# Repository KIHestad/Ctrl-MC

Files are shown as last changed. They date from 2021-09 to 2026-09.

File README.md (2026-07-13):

Ctrl-MC logo

# Motorcycle Control System

Ctrl MC (pronounced: "Control MC") is a system currently in development for simplifying and modernizing the wiring for motorcycles.

The project is managed by [KI Hestad](https://youtube.com/kihestad).
For updated information about the project check the authors [YouTube channel](https://youtube.com/kihestad). Feel free to participate with ideas and feedback by joining the projects [Discord Server](https://discord.gg/p5pfdZxfS8)

PCBs for this project are sponsored by [NextPCB](https://www.nextpcb.com?code=kihestad). If you need PCB manufacturing services, we recommend [NextPCB](https://www.nextpcb.com?code=kihestad).

Do you want to support this project? It's easy, just [click here to subscribe to the YouTube channel](https://youtube.com/kihestad/?sub_confirmation=1)!!!

## Project Description

This project is still in early stages, the idea is to:

* Create a motorcycle control system based on microcontrollers (STM32) and canbus to simplify and improve the wiring harness with possibility to add modern features for 'classic' (=older) motorcycles
  * The main goal is to make an intuitive and reliable system for wiring up a motorcycles lights and instruments 
  * The project does not in the first phases aim to replace or modify the motorcycle engine ignition system, but maybe later?
* Provide software, schematics and instructions free of charge
* Create a community for motorcycle- and Arduino enthusiasts that want to contribute
* Make the solution universal and configurable, it should be suitable for as many motorcycle brands and models as possible

Long term goals, depending on the success of the project:
* Provide a DIY kit with all parts needed
* Provide a completely built solution ready to be installed on the bike

Some of the benefits the system (hopefully) will give:

* Reliability: Individual solid state relays with inbuilt automatic fuses controls 12V to the bikes electrical components
* Simplify wiring: Single cable per component, separat wiring for input controls on handlebar and output power to components
* Providing customization: Setting parameters to enable features and how they should work
* Gives posibility to improve or add new features to the motorcycle (optional): 
  * Touch buttons instead of traditional handlebar switches
  * Keyless ignition using bluetooth, RF-ID or "password" using input buttons
  * OLED display instead of traditional speedometer, tachometer and warning lights
  * Smart functions, ex: auto turn off indicator lights, not possible to trigger start motor when engine is running
  * Alarm if bike is moved
* Use standard components
* Provide a budget friendly solution as an alternative to expensive commercial products

## Development information

The software is developed using Visual Studio Code. The first prototypes where using are using Platform IO, Arduino framework and C++ language. The latest prototype is using STM32CubeIDE and C language. The software is open source and available in this GitHub repository.
* Prototype 1 was a first attempt having a display unit and a relay unit using serial communication to send data in between
* Prototype 2 was a standalone display unit for testing use of hall sensor for speedometer and IT sensor for rpm meter made for a Cagiva 750 Elefant.
* Prototype 3 is a simple canbus communication test using STM32 microcontroller, this is not to be used in further development but just for testing the canbus communication
* MC Wiring Simulator is a PCB designed as a supportng tool for testing and developing purposes. 

## Other info

Let me know if anything is missing, just go to the project [Discord channel](https://discord.gg/p5pfdZxfS8) ^_^

Ctrl-MC logo

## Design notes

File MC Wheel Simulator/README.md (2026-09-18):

# Motorcycle Wheel Simulator

Contributior: Paul McIntosh

The is a wheel simulator is to enable bench testing wheel hall effect sensors and their input to the motorcycle/scooter system.

The basic concept is to simulate a rotating magnet that would sit on a wheel and drives a hall effect sensor. Why is this useful? The signal from a hall effect (or reed switch) can be noisy or not fit for purpose, trying to debug problems on a motorcycle/scooter while riding, takes insane circus skills and although fun, may put your electronic test equipment in danger :)

This simulator solves the problem by providing an adjustable RPM to drive your sensor, so you can develop things like speedometers and other cool things, like power from acceleration.

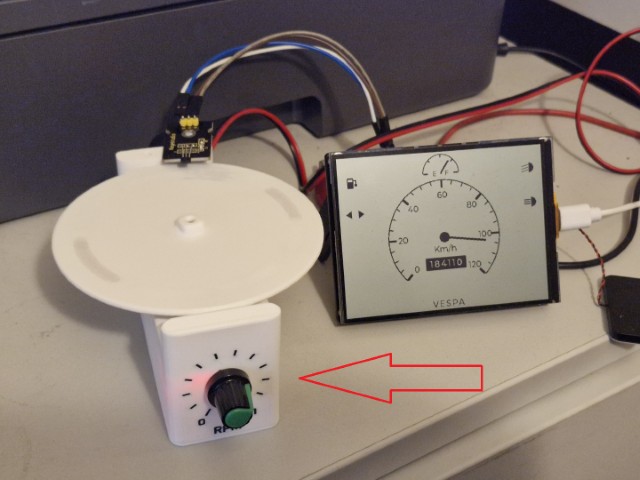
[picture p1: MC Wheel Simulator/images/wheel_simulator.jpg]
wheel_simulator


## What is provided

- stl files you can 3d print
- step files you can adjust to your needs

## What you need

The stls work with the following components

- Neodymium Disc Magnet - 6mm x 2mm
- 1000rpm Mini DC N20 geared motor 
- EMSea PWM DC Low Voltage Motor Speed Controller with Control Knob to match above
- Connectors, screws and wire etc

Note: you get what you pay for - lots of cheap stuff will work but may be noisy and buggy

## Considerations

The stls provided can take 4 x magnets, use 2 or 4 to keep the rotor balanced. **Make sure they are inserted with the same N/S orientation so that the hall sensor detects the same magnetic field each time**

With the above you can pick your target RPM based on wheel size and speed e.g. 2 magnets with 1000RPM motor = 2000RPM.

## Construction Images

Steps to construct - assuming 3d printing has completed

1. Attach wiring to components (see parts list above)

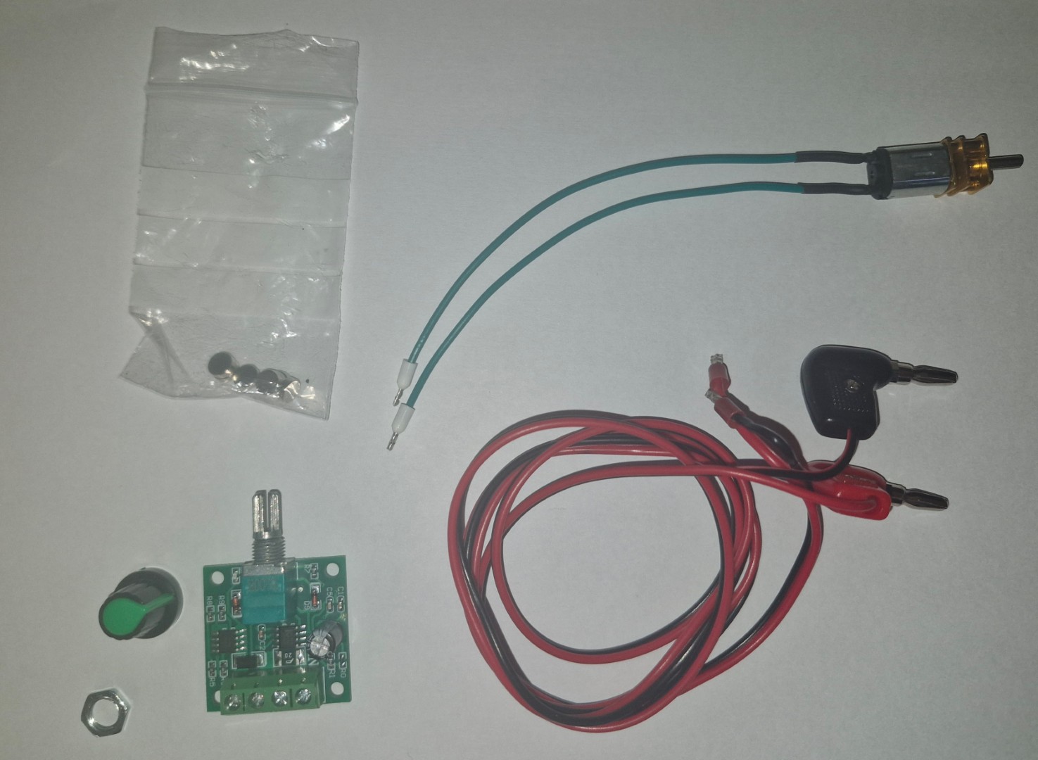
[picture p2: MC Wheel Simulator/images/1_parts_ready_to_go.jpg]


2. Push motor in from the top

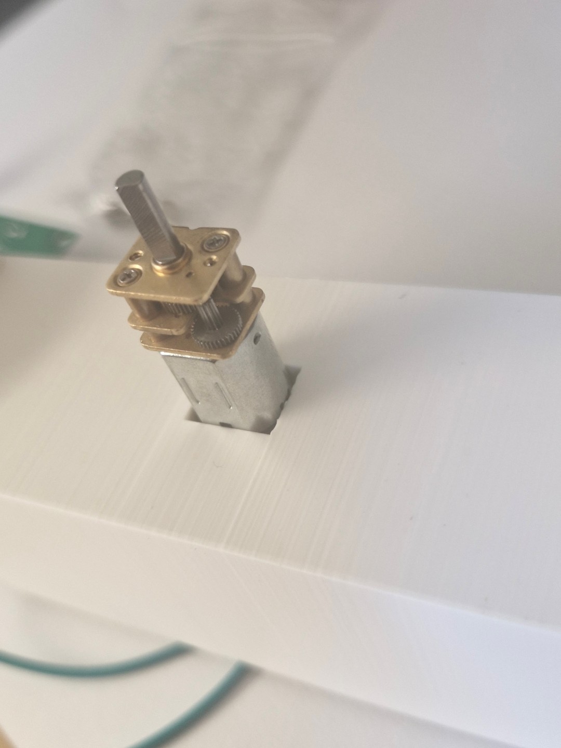
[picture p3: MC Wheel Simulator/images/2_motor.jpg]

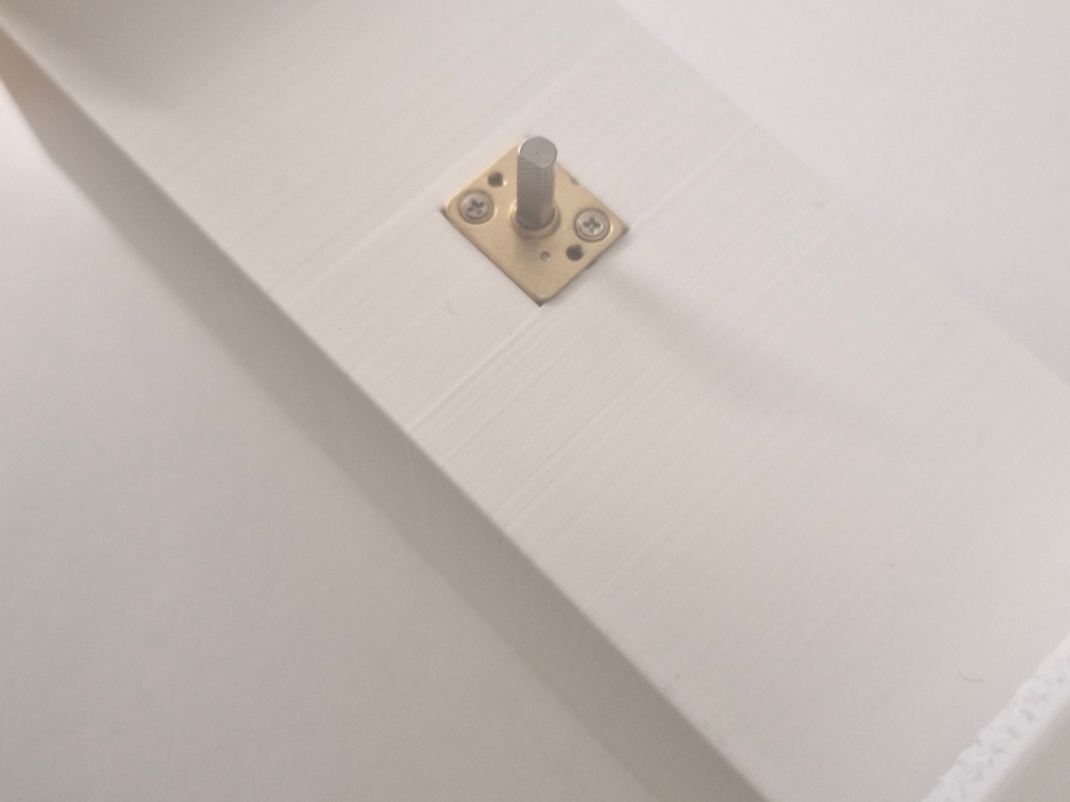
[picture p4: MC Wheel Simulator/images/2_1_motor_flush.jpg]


3. Press on adaptor

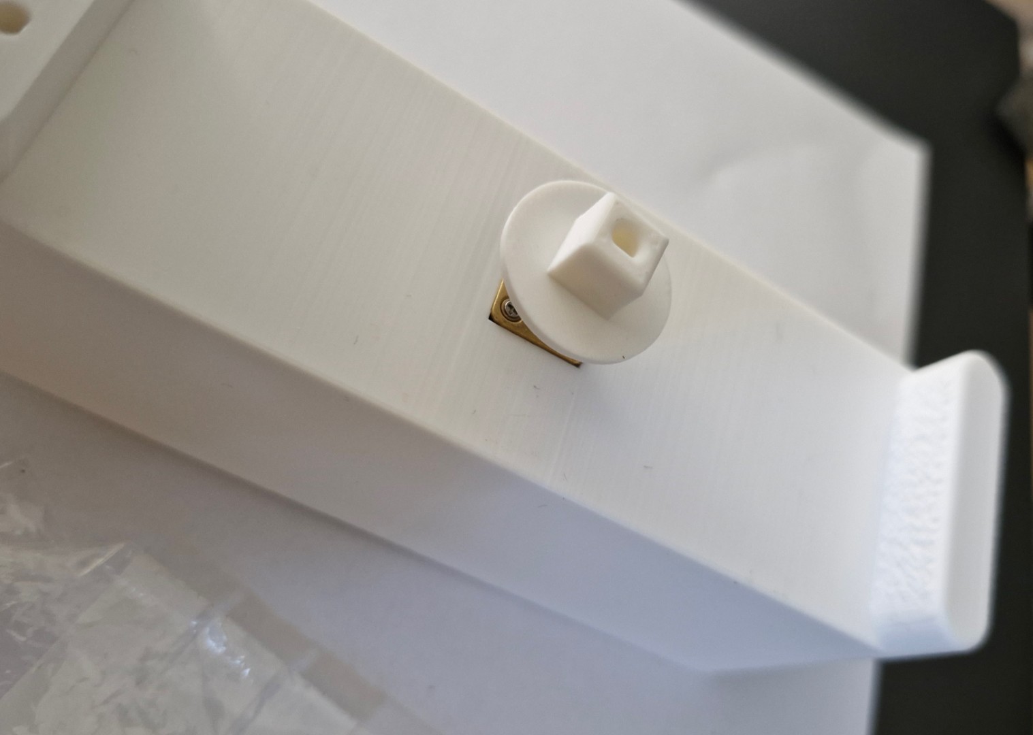
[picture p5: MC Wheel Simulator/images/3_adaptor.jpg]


4. Connect internal wiring and screw controller board into place

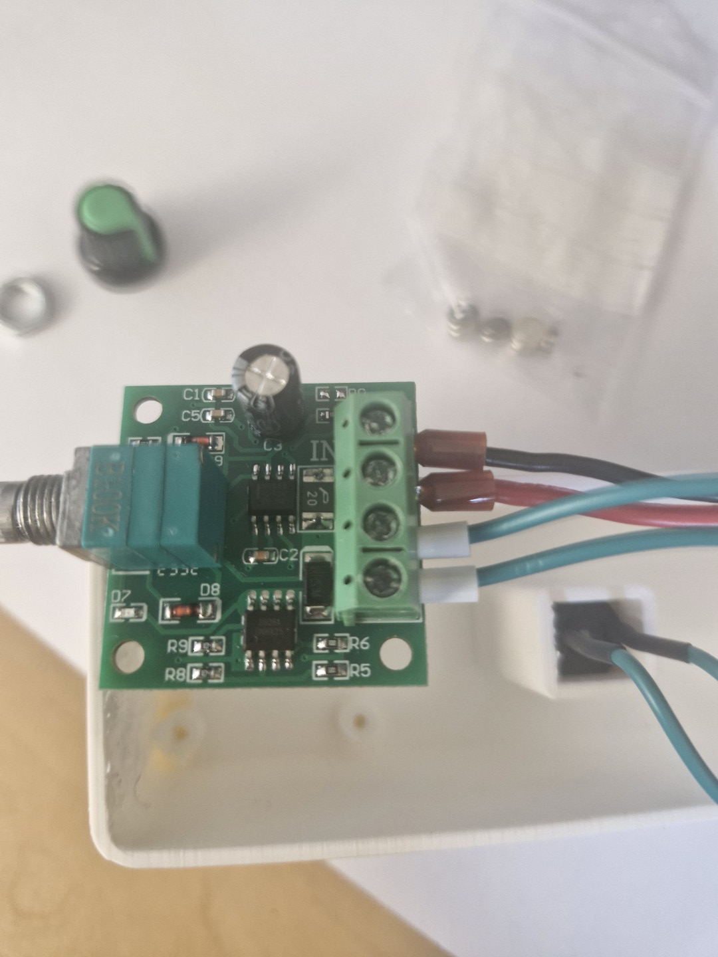
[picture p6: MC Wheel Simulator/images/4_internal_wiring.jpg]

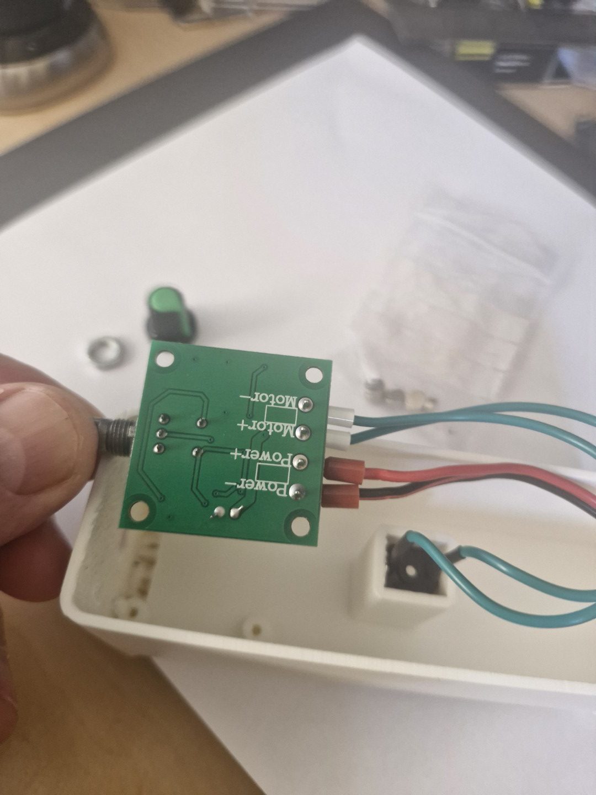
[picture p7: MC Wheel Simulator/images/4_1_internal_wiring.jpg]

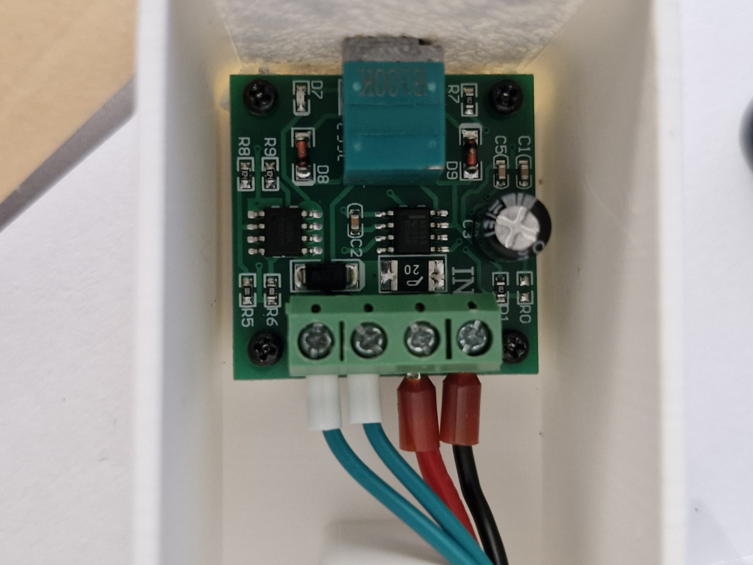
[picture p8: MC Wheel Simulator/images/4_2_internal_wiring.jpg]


5. Check everything works and clip in the base

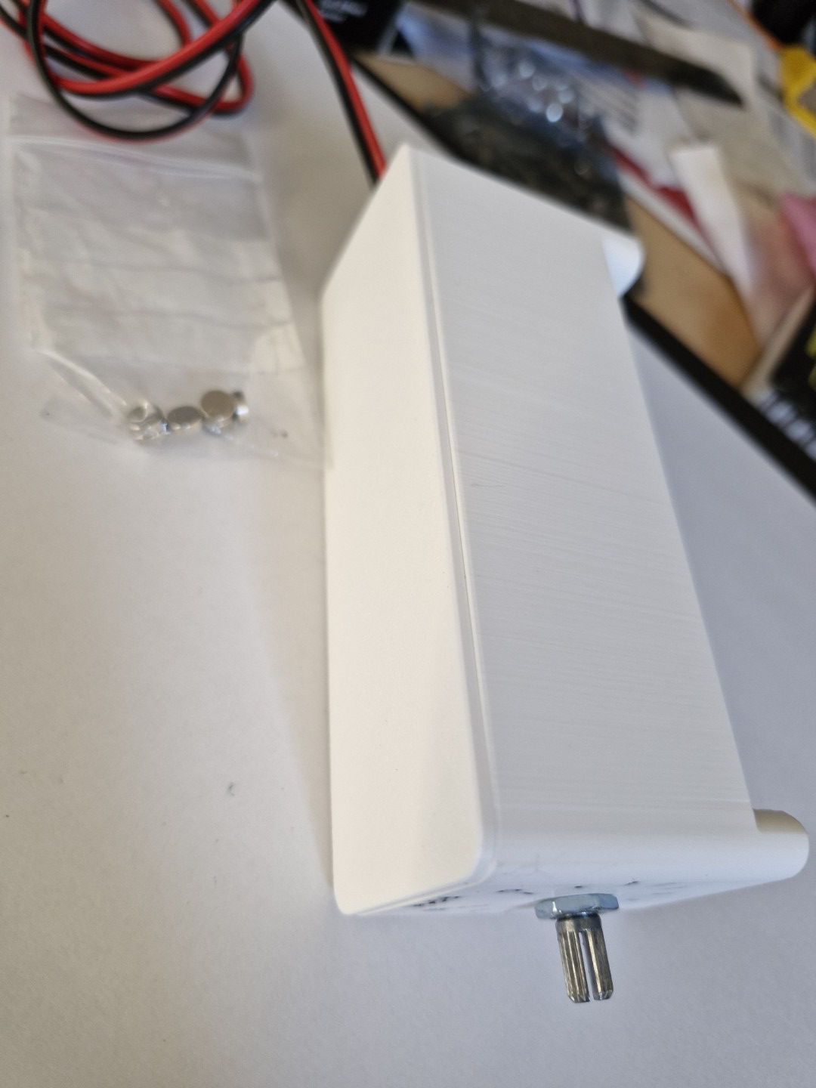
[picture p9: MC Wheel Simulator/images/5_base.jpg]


6. Insert magnets into rotor (keep polarity the same - marking dots helps)

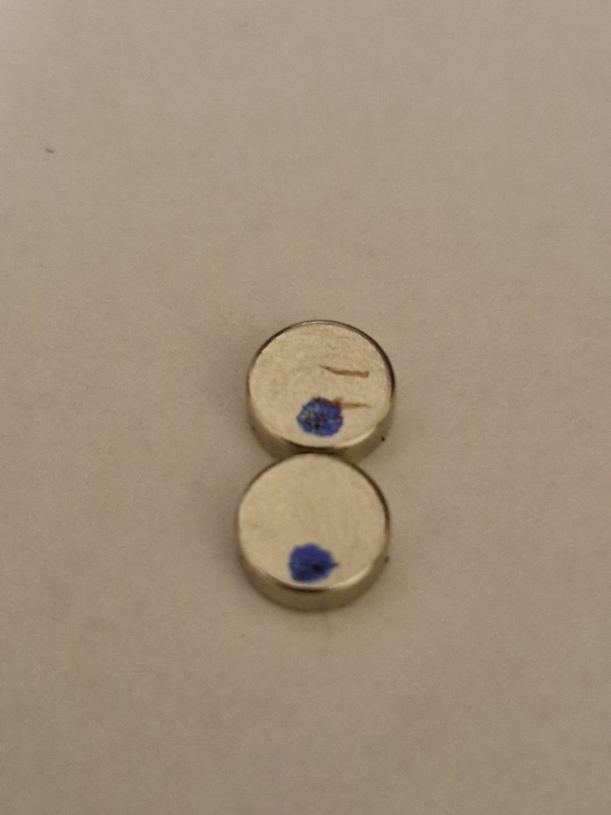
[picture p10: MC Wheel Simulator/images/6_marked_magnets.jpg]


7. Mount rotor and control knob

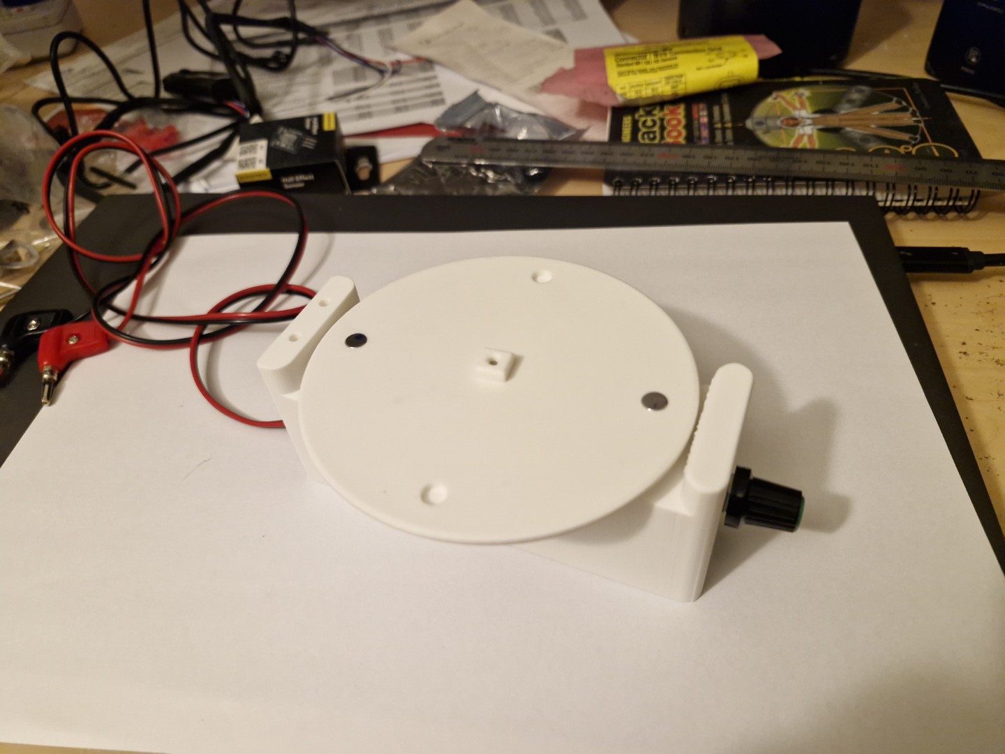
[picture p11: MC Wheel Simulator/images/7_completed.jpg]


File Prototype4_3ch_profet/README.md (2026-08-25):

Ctrl MC logo

# PROTOTYPE 4B: 3 CHANNEL PROFET SWITCHES - STM32 with Infineon Profet +12V Smart Switch modules

The prototype 4B is the second complete software for the Ctrl MC system that uses Infineon Profet +12V Smart Switches. This code is the basis for further development, but it is not the final system. 

The software is made to be used on a WeAct Studio STM32G431 dev board, and one custom PCB module with one 15Amp switch and one 2 x 5Amp swithc. Input GPIO's are also configuret to be able to test turning the switches on and off. It's tested with the MC Wiring Simulator.

The code is built using VS Code with the STM32 extensions. The setup is explained in the document:

*  [Ctrl MC Software Stack Setup.pdf](https://github.com/KIHestad/Ctrl-MC/blob/main/Documents/Ctrl-MC%20Software%20Stack%20Setup.pdf)

Here is the link to the YouTube video demoing this system:

* [The New Modern Motorcycle Wiring System - Ctrl MC](https://youtu.be/QElHGgWnjcQ?si=KIwvGmHAoNGqVMwO)

Here is the link to the YouTube video explaining the system overall:

* [Uprade Your Motorcycle using Smart High-Side Switches](https://youtu.be/tBPsuoETR0Y?si=mi2s_HrKnGi2g0Y8)

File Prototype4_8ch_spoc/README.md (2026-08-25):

Ctrl MC logo

# PROTOTYPE 4C: 8 CHANNEL SPOC SWITCHES - STM32 with Infineon SPOC +12V Smart Switch modules

The prototype 4C is the third complete software for the Ctrl MC system that uses Infineon SPOC +12V Smart Switches. This code is the basis for further development, but it is not the final system. 

The software is made to be used on a WeAct Studio STM32G431 dev board, and one custom PCB modules with two 4 channel SPOC swithces. Each swithc has 2 x 4Amp and 2 x 7Amp channels. It uses SPI for communication with the MCU. It's tested with the MC Wiring Simulator.

The code is built using VS Code with the STM32 extensions. The setup is explained in the document:

*  [Ctrl MC Software Stack Setup.pdf](https://github.com/KIHestad/Ctrl-MC/blob/main/Documents/Ctrl-MC%20Software%20Stack%20Setup.pdf)

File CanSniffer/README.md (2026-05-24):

Ctrl MC logo

# CanSniffer

This is a simple software for sniffing on can bus messages from the Ctrl MC system. It's made so it's possible to connect the system to a computer to inspect canbus messages being transferred on the bus. It's not just sniffing btw, it's also possible to send messages to the can bus, but this is not the main purpose of the software.

The software is made to be used on a WeAct Studio STM32G431 dev board, and a custom power and can bus transceiver PCB module made as part of the Ctrl MC project. 

When using SavvyCan, select connection type "Serial Connection (GVRET) and select highest speed (1000000).

Upload the cmc_can_message.dbc to the DBC File Manager in SavvyCan to get the message names and signals. 

The code is built using VS Code with the STM32 extensions. The setup is explained in the document:

*  [Ctrl MC Software Stack Setup.pdf](https://github.com/KIHestad/Ctrl-MC/blob/main/Documents/Ctrl-MC%20Software%20Stack%20Setup.pdf)

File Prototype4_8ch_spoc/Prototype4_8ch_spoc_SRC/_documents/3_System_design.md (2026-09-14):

# System Design Principles

The system is designed to be modular, with clear separation between hardware abstraction and core application logic. Data structs and functions are separated into separate files, and each is responsible for a specific aspect of the system, such as sensor input processing, actuator control, and CANBUS communication.

The code aligns with the Sense-Compute-Actuate pattern, decoupled by a central app state: `cmc_app_state` that is the single source of truth. The app state is not just a global data store — it also acts as an event bus where changes trigger reactions from features across units. This allows for a reactive and flexible design where different units can respond to state changes without being tightly coupled to each other.

CAN bus messages are used for communication between units. Interrupts should only fetch data and set flags, these are written to app state. The main loop handles all processing and state management.

For data coming from the unit itself, like buttons and sensors, this is managed by the `cmc_app_state_updater`. 

The enabled features are responsible for reading the app state and driving outputs or performing actions based on that state. This separation allows for a clean and maintainable codebase where each component has a clear responsibility. The features are also where CAN messages are generated and transmitted to other units.

# System Logic Processing Flow
The following illustration shows the high-level system logic processing flows.

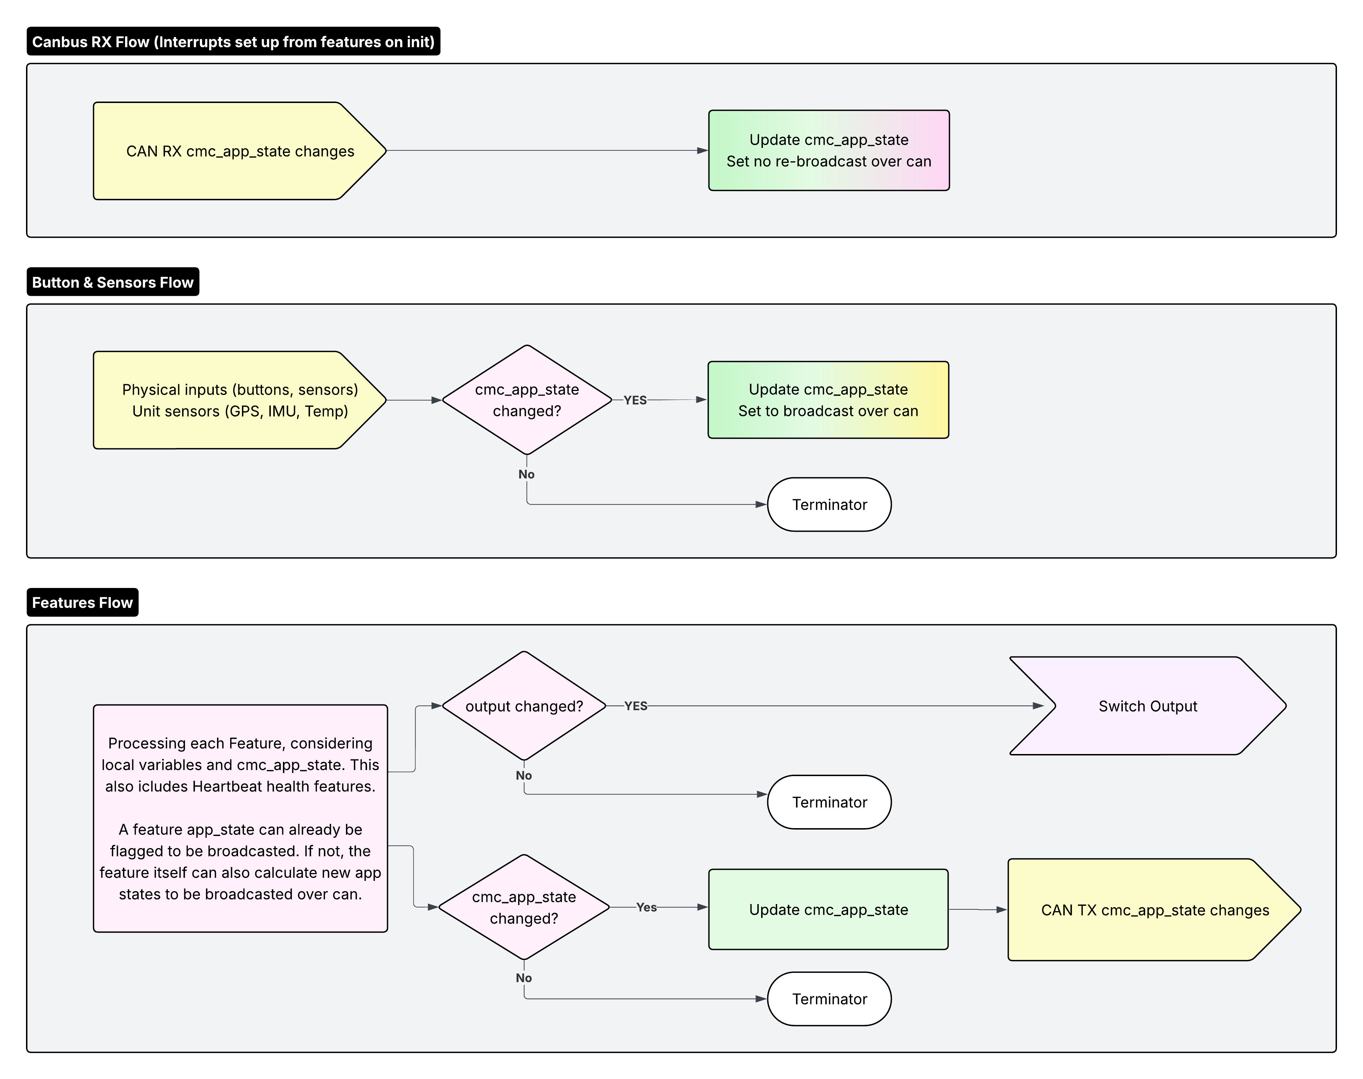
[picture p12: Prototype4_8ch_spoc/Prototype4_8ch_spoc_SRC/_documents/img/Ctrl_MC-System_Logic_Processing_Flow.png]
System Logic Processing Flow


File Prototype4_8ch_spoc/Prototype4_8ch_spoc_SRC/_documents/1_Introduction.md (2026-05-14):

# Introduction

The documents in this folder a high-level overview of the code and its structure. The code is primarily commented inline. 

## The Ctrl MC system
Goto [KI Hestad's homepage](https://hestad.no) or the [Ctrl MC GitHub repository](https://github.com/KIHestad/Ctrl-MC) for more information about the Ctrl MC system.

## About Prototype 4
Prototype 4 is a prototype of the Ctrl MC system, primarely for testing out a fully working prototype of the I/O units based on STM32 microcontoller, Inifion PROFET high-side smart switches and canbus communication for connecting multiple I/O units.

## User Manual

As the system boots up the unit flashes very fast (50ms/150ms = 5 blinks per sec). This is normally such a short time it's not noticable. If this is observed it is most likely a startup issue where the system has crashed before any error handling has been invoked. 

When the unit starts up successfully after memory is cleared, the unit goes into a configuration mode for setting unit id. The onboard LED is flashing medium fast (50ms/950ms = 1 blink per sec) and waits for a button press, when button 1-4 is pressed (short to GND) this will be the unit id.

When unit id is set and the system starts successfully, the unit goes into normal operation mode. 
The onboard LED is flashing every 5th second with number of blinks idincating the unit id.

If an startup error occurs, the unit onboard LED flashes fast the number of blinks representing the error code, repeated every second. The error codes are as the number for the enum: `cmc_app_state_status_t`

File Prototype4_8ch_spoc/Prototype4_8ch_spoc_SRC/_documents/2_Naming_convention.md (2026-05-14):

# Naming Convention

To separate the code made for the Ctrl MC system from the STM32 HAL code, all files, variables and methods uses `cmc_` prefix. 

The `snake_case` style is used for all files, variables and methods.

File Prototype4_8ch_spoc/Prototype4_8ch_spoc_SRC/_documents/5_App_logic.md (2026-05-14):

# Application logic

This explains the application logic.

## Global configuration: cmc_config - flash region: CONFIG (r)

The system is controlled by a global configuration, this is to be set by the user and contains all the settings for the system. All units on the system must have the exact same configuration. A CRC checksum is compared across units to ensure there is no misconfiguration.

The configuration is stored in a struct called `cmc_config_t` and is defined in `cmc_config_type.h`. The configuration is stored in flash memory and is loaded at startup. 

A new unit might be loaded with a new config, when this happens other units will be updated to use the new configuration. A new unit could be "empty", it will then request a valid using canbus and be updated with what is in use on other units. A new config can also be inserted by a dedicated programming unit. 

For the prototype the config is hardcoded by the user by editing the `cmc_config_default`. This is loaded on startup if config is not present in flash. When flashing a unit a complete erase of flash must be done to force the default config to be loaded on first startup after flashing. 

## Unit info: cmc_config_unit_info - flash region: UNIT_INFO (r)

The unit info is a struct that contains information about the individual unit. The unit id is very important, there can not be two units on the system with the same id. This ensures that each unit can be uniquely identified and addressed on the canbus, and when troubleshooting the user can easily identify the unit.

The unit info is stored in flash memory and is loaded at startup. For a new unit with flash erased, the unit info can be updated by the user by pressing a button during startup. 

## Usage Journal: cmc_usage_journal - flash region: USAGE_JOURNAL (r)

The usage journal is a struct that contains information about the usage of the system. Typical data to be stored is distance ridden (total and trip counter), max speed, average speed, ride time, etc. The usage journal is stored in flash memory by rotating what byte position the storage happens to not wear out the flash memory, and is updated during runtime in suitable intervals.

## Startup sequence: (cmc_app_logic) cmc_app_init

The startup sequence reads alle the necessary data from flash (listed above), checks if it is valid, and triggers initialization routines or warnings if needed. The cmc_app_state.system.status is set accoring to the startup result. If error the system will inititate a blink pattern on the onboard LED to indicate the error. 

If startup is successful the system will proceed to normal operation and the unit will blink every 5 seconds to indicate success and number of rapid blinks tells the unit id.

The startup sequence will also set canbus interrupts: `cmc_features_manager.cmc_features_init` according to what features are enabled and active on the unit.

## Normal operation: (cmc_app_logic) cmc_app_execute

During normal operation the system will continuously scan for input, update the state of the system, and execute features based on the state and input. The system will also periodically save the usage journal to flash.

Units are handled by interrupts and not shown as a separate function as part of the main loop.

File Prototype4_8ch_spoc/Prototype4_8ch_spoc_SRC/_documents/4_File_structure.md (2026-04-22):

# File Structure

The ./Core/Src/main.c file is generated by STM32CubeMX and contains the main loop and is the entry point of the program. This file should not be edited beside three specific sections:

```c
/* USER CODE BEGIN Includes */
#include "cmc_app_logic.h"
/* USER CODE END Includes */

/* USER CODE BEGIN 2 */
cmc_app_init();
/* USER CODE END 2 */

/* Infinite loop */
/* USER CODE BEGIN WHILE */
while (1)
{
  cmc_app_process(); // Start main application logic loop
  /* USER CODE END WHILE */
}
```

This makes sure most of the code for the system is separated from the generated code and makes it easier to update the generated from STM32CubeMX code without worrying about merge conflicts. 

## Reference code files for build

CMake is used for building the code, and the CMakeLists.txt file contains the build instructions. 

**CMakeLists.txt files:**

`/cmake/stm32cubemx/CMakeLists.txt`  
This file is generated by STM32CubeMX and contains the build instructions for the generated code. This file should not be edited.

`/CMakeLists.txt`  
This file in root folder contains the build instructions for the code and has a separate secton `# Add sources to executable` for adding the cmc_ files for the build. This file can be edited by the user and is not generated by STM32CubeMX.

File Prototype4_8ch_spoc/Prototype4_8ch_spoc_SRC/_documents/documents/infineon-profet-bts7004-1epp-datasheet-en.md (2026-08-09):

<!-- PageNumber="Side 1" -->

<figure>

infineon

</figure>

BTS7004-1EPP

PROFET™+2 12V
Smart High-Side Power Switch

<figure>

O
Qualified

AEC

·

V

RoHS

</figure>

# 1 Overview

## Potential Applications

· Suitable for driving 15 A resistive, inductive and capacitive loads

· Replaces electromechanical relays, fuses and discrete circuits

· Suitable for driving glow plug, heating loads, DC motor and for power
distribution

## 1x 4.4 ml2

<table>
<tr>
<td>Package</td>
<td>PG-TSDSO-14</td>
</tr>
<tr>
<td>Marking</td>
<td>7004-1P</td>
</tr>
</table>

<figure>

JA
Infineon
TSDSO-14

</figure>

<figure>
<figcaption>Figure 1 BTS7004-1EPP Application Diagram. Further information in Chapter 10</figcaption>

VBAT

ZWIRE

Optional

Optional

Cvs

CVSGND

T1

Logic Supply

J

RGND

VDD

GND

VS

GPIO

RIN

IN

ROL

GPIO

RDEN

DEN

OUT

PROFET™+2
12V

RPD

COUT0

Dz2

Cvs2

Microcontroller

ZWIRE

ADC

RADE

RIS PROT

IS

VSS

CSENSE

DZ1

RSENSE

ZLOAD*

Logic GND

Power GND

Optional

Chassis GND

*See Chapter 1 „Potential Applications“

App_CM_JNTDIO_CVG.ent

</figure>

<!-- PageFooter="Data Sheet www.infineon.com" -->
<!-- PageNumber="1" -->
<!-- PageFooter="Rev. 1.03 2019-10-15" -->
<!-- PageBreak -->

<!-- PageNumber="Side 2" -->

<figure>

Infineon

</figure>

<!-- PageHeader="BTS7004-1EPP PROFET™+2 12V" -->

### Overview

#### Basic Features

· High-Side Switch with Diagnosis and Embedded Protection

· Part of PROFET™+2 12V Family

· ReverseON for low power dissipation in Reverse Polarity

· Green Product (RoHS compliant)

#### Protection Features

· Absolute and dynamic temperature limitation with controlled reactivation

· Overcurrent protection (tripping) with Intelligent Latch

· Undervoltage shutdown

· Overvoltage protection with external components (as shown in Figure 37)

#### Diagnostic Features

· Proportional load current sense

· Open Load in ON and OFF state

· Short circuit to ground and battery

#### Product Validation

Qualified for automotive applications. Product validation according to AEC-Q100 Grade 1.

#### Description

The BTS7004-1EPP is a Smart High-Side Power Switch, providing protection functions and diagnosis.

<table>
<caption>Table 1 Product Summary</caption>
<tr>
<th>Parameter</th>
<th>Symbol</th>
<th>Values</th>
</tr>
<tr>
<td>Minimum Operating voltage</td>
<td>VS(OP)</td>
<td>4.1 V</td>
</tr>
<tr>
<td>Minimum Operating voltage (cranking)</td>
<td>VS(UV)</td>
<td>3.1 V</td>
</tr>
<tr>
<td>Maximum Operating voltage</td>
<td>Vs</td>
<td>28 V</td>
</tr>
<tr>
<td>Minimum Overvoltage protection (T) ≥ 25 ℃)</td>
<td>VDS(CLAMP)_25</td>
<td>35 V</td>
</tr>
<tr>
<td>Maximum current in OFF mode (T) ≤ 85 ℃)</td>
<td>"VS(OFF)_85</td>
<td>0.5 µA</td>
</tr>
<tr>
<td>Maximum operative current</td>
<td>İGND(ON_D)</td>
<td>3 mA</td>
</tr>
<tr>
<td>Typical ON-state resistance (T) = 25 ℃)</td>
<td>RDS(ON)_25</td>
<td>4.4 m22</td>
</tr>
<tr>
<td>Maximum ON-state resistance (T) = 150 ℃)</td>
<td>RDS(ON)_150</td>
<td>8 m22</td>
</tr>
<tr>
<td>Nominal load current (TA = 85 ℃)</td>
<td>IL(NOM)</td>
<td>15 A</td>
</tr>
<tr>
<td>Minimum overload detection current</td>
<td>IL(OVL0)_-40</td>
<td>107 A</td>
</tr>
<tr>
<td>Typical current sense ratio at /L = IL(NOM)</td>
<td>KILIS</td>
<td>20000</td>
</tr>
</table>

<!-- PageFooter="Data Sheet" -->
<!-- PageNumber="2" -->
<!-- PageFooter="Rev. 1.03 2019-10-15" -->
<!-- PageBreak -->

<!-- PageNumber="Side 3" -->

<!-- PageHeader="BTS7004-1EPP PROFET™+2 12V" -->

<figure>

Infineon

</figure>

## Block Diagram and Terms

### 2 Block Diagram and Terms

#### 2.1 Block Diagram

<figure>
<figcaption>Figure 2 Block Diagram of BTS7004-1EPP</figcaption>

VS

Supply Voltage
Monitoring

Overvoltage
Protection

Internal Power Supply

Channel

Intelligent Restart
Control

Voltage Sensor

Overtemperature

T

Overvoltage
Clamping

IS

SENSE Output

Driver
Logic

Gate Control
+
Chargepump

Overcurrent
Protection

IN

ESD
Protection
+
Input Logic

ReverseON
InverseON

OUT

DEN

Load Current Sense

Output Voltage Limitation

Internal Reverse
Polarity Protection

GND Circuitry

GND

Block_HEAT1ch.emf

</figure>

<!-- PageFooter="Data Sheet" -->
<!-- PageNumber="3" -->
<!-- PageFooter="Rev. 1.03 2019-10-15" -->
<!-- PageBreak -->

<!-- PageNumber="Side 4" -->

<!-- PageHeader="BTS7004-1EPP PROFET™+2 12V" -->

<figure>

Infineon

</figure>

## Block Diagram and Terms

### 2.2 Terms

Figure 3 shows all terms used in this data sheet, with associated convention for positive values.

<figure>
<figcaption>Figure 3 Voltage and Current Convention</figcaption>

Ivs

☒

VsIs

VS

/IN

☒
IN

VDS

/DEN

☒
DEN

IL

Vs

OUT
☒

VIN

VDEN

/Is

☒
IS

VOUT

GND

VIS

☒

IGND

Terms_1CH.emf

</figure>

<!-- PageFooter="Data Sheet" -->
<!-- PageNumber="4" -->
<!-- PageFooter="Rev. 1.03 2019-10-15" -->
<!-- PageBreak -->

<!-- PageNumber="Side 5" -->

<!-- PageHeader="BTS7004-1EPP PROFET™+2 12V" -->

<figure>

Infineon

</figure>

Pin Configuration

# 3 Pin Configuration

## 3.1 Pin Assignment

<figure>
<figcaption>Figure 4 Pin Configuration</figcaption>

GND

1

14

OUT

IN

2

13

OUT

DEN

3

12

OUT

IS

4

VS

11

n.c.

n.c.

5

10

OUT

n.c.

6

9

OUT

n.c.

7

exposed pad (bottom)

8

OUT

PinOut_PROFET1ch_PDH.emf

</figure>

<!-- PageFooter="Data Sheet" -->
<!-- PageNumber="5" -->
<!-- PageFooter="Rev. 1.03 2019-10-15" -->
<!-- PageBreak -->

<!-- PageNumber="Side 6" -->

<figure>

Infineon

</figure>

<!-- PageHeader="BTS7004-1EPP PROFET™+2 12V" -->
<!-- PageHeader="Pin Configuration" -->

## 3.2 Pin Definitions and Functions

<table>
<caption>Table 2 Pin Definition</caption>
<tr>
<th>Pin</th>
<th>Symbol</th>
<th>Function</th>
</tr>
<tr>
<td>EP</td>
<td>VS (exposed pad)</td>
<td>Supply Voltage Battery voltage</td>
</tr>
<tr>
<td>1</td>
<td>GND</td>
<td>Ground Signal ground</td>
</tr>
<tr>
<td>2</td>
<td>IN</td>
<td>Input Channel Digital signal to switch ON the channel ("high" active) If not used: connect to GND pin or to module ground with resistor RIN = 4.7 k£2</td>
</tr>
<tr>
<td>3</td>
<td>DEN</td>
<td>Diagnostic Enable Digital signal to enable device diagnosis ("high" active) and to clear the protection latch of channel If not used: connect to GND pin or to module ground with resistor RDEN = 4.7 kQ2</td>
</tr>
<tr>
<td>4</td>
<td>IS</td>
<td>SENSE current output Analog/digital signal for diagnosis If not used: left open</td>
</tr>
<tr>
<td>5-7,11</td>
<td>n.c.</td>
<td>Not connected, internally not bonded</td>
</tr>
<tr>
<td>8-10, 12- 14</td>
<td>OUT</td>
<td>Output Protected high-side power output channel1)</td>
</tr>
</table>

1\) All output pins of the channel must be connected together on the PCB. All pins of the output are internally connected
together. PCB traces have to be designed to withstand the maximum current which can flow.

<!-- PageFooter="Data Sheet" -->
<!-- PageNumber="6" -->
<!-- PageFooter="Rev. 1.03 2019-10-15" -->
<!-- PageBreak -->

<!-- PageNumber="Side 7" -->

<figure>

Infineon

</figure>

<!-- PageHeader="BTS7004-1EPP PROFET™+2 12V" -->

### General Product Characteristics

#### 4 General Product Characteristics

##### 4.1 Absolute Maximum Ratings - General

Table 3
Absolute Maximum Ratings1)

TJ =- 40 °C to +150 ℃; all voltages with respect to ground, positive current flowing into pin
(unless otherwise specified)

<table>
<tr>
<th rowspan="2">Parameter</th>
<th rowspan="2">Symbol</th>
<th colspan="3">Values</th>
<th rowspan="2">Unit</th>
<th rowspan="2">Note or Test Condition</th>
<th rowspan="2">Number</th>
</tr>
<tr>
<th>Min.</th>
<th>Typ.</th>
<th>Max.</th>
</tr>
<tr>
<td>Supply pins</td>
<td></td>
<td></td>
<td colspan="2"></td>
<td></td>
<td></td>
<td></td>
</tr>
<tr>
<td>Power Supply Voltage</td>
<td>Vs</td>
<td>-0.3</td>
<td>–</td>
<td>28</td>
<td>V</td>
<td>–</td>
<td>P_4.1.0.1</td>
</tr>
<tr>
<td>Load Dump Voltage</td>
<td>V BAT(LD)</td>
<td>–</td>
<td>–</td>
<td>35</td>
<td>V</td>
<td>suppressed Load Dump acc. to ISO16750-2 (2010). Ri = 202</td>
<td>P_4.1.0.3</td>
</tr>
<tr>
<td>Supply Voltage for Short Circuit Protection</td>
<td>VBAT(SC)</td>
<td>0</td>
<td>–</td>
<td>24</td>
<td>V</td>
<td>Setup acc. to AEC-Q100-012</td>
<td>P_4.1.0.25</td>
</tr>
<tr>
<td>Reverse Polarity Voltage</td>
<td>-V BAT(REV)</td>
<td>–</td>
<td>–</td>
<td>16</td>
<td>V</td>
<td>t ≤ 2 min TA = +25 ℃ Setup as described in Chapter 10</td>
<td>P_4.1.0.5</td>
</tr>
<tr>
<td>Current through GND Pin</td>
<td>IGND</td>
<td>-50</td>
<td>–</td>
<td>50</td>
<td>mA</td>
<td>RGND according to Chapter 10</td>
<td>P_4.1.0.9</td>
</tr>
<tr>
<td colspan="8">Logic &amp; control pins (Digital Input = DI) DI = IN, DEN</td>
</tr>
<tr>
<td>Current through DI Pin</td>
<td>IDI</td>
<td>-1</td>
<td>–</td>
<td>2</td>
<td>mA</td>
<td>2)</td>
<td>P_4.1.0.14</td>
</tr>
<tr>
<td>Current through DI Pin Reverse Battery Condition</td>
<td>/DI(REV)</td>
<td>-1</td>
<td>–</td>
<td>10</td>
<td>mA</td>
<td>2) t ≤ 2 min</td>
<td>P_4.1.0.36</td>
</tr>
<tr>
<td colspan="8">IS pin</td>
</tr>
<tr>
<td>Voltage at IS Pin</td>
<td>VIS</td>
<td>-1.5</td>
<td>–</td>
<td>VS</td>
<td>V</td>
<td>lis = 10 µA</td>
<td>P_4.1.0.16</td>
</tr>
<tr>
<td>Current through IS Pin</td>
<td>'Is</td>
<td>-25</td>
<td>–</td>
<td>"IS(SAT),M AX</td>
<td>mA</td>
<td>–</td>
<td>P_4.1.0.18</td>
</tr>
<tr>
<td colspan="8">Temperatures</td>
</tr>
<tr>
<td>Junction Temperature</td>
<td>TJ</td>
<td>-40</td>
<td>–</td>
<td>150</td>
<td>℃</td>
<td>–</td>
<td>P_4.1.0.19</td>
</tr>
<tr>
<td>Storage Temperature</td>
<td>TSTG</td>
<td>-55</td>
<td>–</td>
<td>150</td>
<td>ºC</td>
<td>–</td>
<td>P_4.1.0.20</td>
</tr>
</table>

<!-- PageFooter="Data Sheet" -->
<!-- PageNumber="7" -->
<!-- PageFooter="Rev. 1.03 2019-10-15" -->
<!-- PageBreak -->

<!-- PageNumber="Side 8" -->

<figure>

Infineon

</figure>

<!-- PageHeader="BTS7004-1EPP PROFET™+2 12V" -->

###### General Product Characteristics

Table 3
Absolute Maximum Ratings1) (continued)

TJ =- 40 °C to +150 ℃; all voltages with respect to ground, positive current flowing into pin
(unless otherwise specified)

<table>
<tr>
<th rowspan="2">Parameter</th>
<th rowspan="2">Symbol</th>
<th colspan="3">Values</th>
<th rowspan="2">Unit</th>
<th rowspan="2">Note or Test Condition</th>
<th rowspan="2">Number</th>
</tr>
<tr>
<th>Min.</th>
<th>Typ.</th>
<th>Max.</th>
</tr>
<tr>
<td>ESD Susceptibility</td>
<td></td>
<td></td>
<td></td>
<td></td>
<td></td>
<td></td>
<td></td>
</tr>
<tr>
<td>ESD Susceptibility all Pins (HBM)</td>
<td>VESD(HBM)</td>
<td>-2</td>
<td>–</td>
<td>2</td>
<td>kV</td>
<td>HBM3)</td>
<td>P_4.1.0.21</td>
</tr>
<tr>
<td>ESD Susceptibility OUT vs GND and VS connected (HBM)</td>
<td>VESD(HBM)_OU T</td>
<td>-4</td>
<td>–</td>
<td>4</td>
<td>kV</td>
<td>HBM3)</td>
<td>P_4.1.0.22</td>
</tr>
<tr>
<td>ESD Susceptibility all Pins (CDM)</td>
<td>ESD(CDM)</td>
<td>-500</td>
<td>–</td>
<td>500</td>
<td>V</td>
<td>CDM4)</td>
<td>P_4.1.0.23</td>
</tr>
<tr>
<td>ESD Susceptibility Corner Pins (CDM) (pins 1, 7, 8, 14)</td>
<td>VESD(CDM)_CR N</td>
<td>-750</td>
<td>–</td>
<td>750</td>
<td>V</td>
<td>CDM4)</td>
<td>P_4.1.0.24</td>
</tr>
</table>

1\) Not subject to production test - specified by design.

2\) Maximum Vpi to be considered for Latch-Up tests: 5.5 V.

3\) ESD susceptibility, Human Body Model "HBM", according to AEC Q100-002.

4\) ESD susceptibility, Charged Device Model "CDM", according to AEC Q100-011.

####### Notes

1\. Stresses above the ones listed here may cause permanent damage to the device. Exposure to absolute
maximum rating conditions for extended periods may affect device reliability.

2\. Integrated protection functions are designed to prevent IC destruction under fault conditions described in the
data sheet. Fault conditions are considered as "outside" normal operating range. Protection functions are
not designed for continuous repetitive operation.

##### 4.2 Absolute Maximum Ratings - Power Stages

###### 4.2.1 Power Stage - 4 m22

Table 4
Absolute Maximum Ratings1)

TJ =- 40 °C to +150 ℃; all voltages with respect to ground, positive current flowing into pin
(unless otherwise specified)

<table>
<tr>
<th rowspan="2">Parameter</th>
<th rowspan="2">Symbol</th>
<th colspan="3">Values</th>
<th rowspan="2">Unit</th>
<th rowspan="2">Note or Test Condition</th>
<th rowspan="2">Number</th>
</tr>
<tr>
<th>Min.</th>
<th>Typ.</th>
<th>Max.</th>
</tr>
<tr>
<td>Maximum Energy Dissipation Single Pulse</td>
<td>EAS</td>
<td>–</td>
<td>–</td>
<td>150</td>
<td>mJ</td>
<td>/L =2*/L(NOM) TJ(0) = 150 ℃ Vs = 28 V</td>
<td>P_4.2.11.1</td>
</tr>
</table>

<!-- PageFooter="Data Sheet" -->
<!-- PageNumber="8" -->
<!-- PageFooter="Rev. 1.03 2019-10-15" -->
<!-- PageBreak -->

<!-- PageNumber="Side 9" -->

<figure>

Infineon

</figure>

<!-- PageHeader="BTS7004-1EPP PROFET™+2 12V" -->

### General Product Characteristics

Table 4
Absolute Maximum Ratings1) (continued)

TJ =- 40 °C to +150 ℃; all voltages with respect to ground, positive current flowing into pin
(unless otherwise specified)

<table>
<tr>
<th rowspan="2">Parameter</th>
<th rowspan="2">Symbol</th>
<th colspan="3">Values</th>
<th rowspan="2">Unit</th>
<th rowspan="2">Note or Test Condition</th>
<th rowspan="2">Number</th>
</tr>
<tr>
<th>Min.</th>
<th>Typ.</th>
<th>Max.</th>
</tr>
<tr>
<td>Maximum Energy Dissipation Repetitive Pulse</td>
<td>EAR</td>
<td>–</td>
<td>–</td>
<td>44</td>
<td>mJ</td>
<td>IL= IL(NOM) TJ(0) = 85 ℃ Vs = 13.5 V 1M cycles</td>
<td>P_4.2.11.4</td>
</tr>
<tr>
<td>Load Current</td>
<td>V/11</td>
<td>-</td>
<td>-</td>
<td>I L(OVL0),MAX</td>
<td>A</td>
<td>–</td>
<td>P_4.2.11.3</td>
</tr>
</table>

1\) Not subject to production test - specified by design.

#### 4.3 Functional Range

<table>
<caption>Table 5 Functional Range - Supply Voltage and Temperature1)</caption>
<tr>
<th rowspan="2">Parameter</th>
<th rowspan="2">Symbol</th>
<th colspan="3">Values</th>
<th rowspan="2">Unit</th>
<th rowspan="2">Note or Test Condition</th>
<th rowspan="2">Number</th>
</tr>
<tr>
<th>Min.</th>
<th>Typ.</th>
<th>Max.</th>
</tr>
<tr>
<td>Supply Voltage Range for Normal Operation</td>
<td>VS(NOR)</td>
<td>6</td>
<td>13.5</td>
<td>18</td>
<td>V</td>
<td>–</td>
<td>P_4.3.0.1</td>
</tr>
<tr>
<td>Lower Extended Supply Voltage Range for Operation</td>
<td>VS(EXT,LOW)</td>
<td>3.1</td>
<td>–</td>
<td>6</td>
<td>V</td>
<td>2)3) (parameter deviations possible)</td>
<td>P_4.3.0.2</td>
</tr>
<tr>
<td>Supply Voltage Range reached after Overload Protection activation leading to "Undervoltage on Vs" condition</td>
<td>VS(EXT,CVG)</td>
<td>–</td>
<td>–</td>
<td>3.1</td>
<td>V</td>
<td>CVSGND is required when the Overload Protection is triggered (see Chapter 8.2) and the observed number of retries is different from what specified in Chapter 8.3.1</td>
<td>P_4.3.0.7</td>
</tr>
<tr>
<td>Upper Extended Supply Voltage Range for Operation</td>
<td>VS(EXT,UP)</td>
<td>18</td>
<td>–</td>
<td>28</td>
<td>V</td>
<td>3) (parameter deviations possible)</td>
<td>P_4.3.0.3</td>
</tr>
<tr>
<td>Junction Temperature</td>
<td>TJ</td>
<td>-40</td>
<td>–</td>
<td>150</td>
<td>ºC</td>
<td>–</td>
<td>P_4.3.0.5</td>
</tr>
</table>

1\) Not subject to production test - specified by design.

2\) In case of Vs voltage decreasing: VS(EXT,LOW), MIN = 3.1 V. In case of Vs voltage increasing: VS(EXT,LOW), MIN = 4.1 V.

3\) Protection functions still operative.

Note:
Within the functional or operating range, the IC operates as described in the circuit description. The
electrical characteristics are specified within the conditions given in the Electrical Characteristics
tables.

<!-- PageFooter="Data Sheet" -->
<!-- PageNumber="9" -->
<!-- PageFooter="Rev. 1.03 2019-10-15" -->
<!-- PageBreak -->

<!-- PageNumber="Side 10" -->

<!-- PageHeader="BTS7004-1EPP PROFET™+2 12V" -->

<figure>

Infineon

</figure>

# General Product Characteristics

## 4.4 Thermal Resistance

Note:
This thermal data was generated in accordance with JEDEC JESD51 standards. For more
information, go to www.jedec.org.

<table>
<caption>Table 6 Thermal Resistance1)</caption>
<tr>
<th rowspan="2">Parameter</th>
<th rowspan="2">Symbol</th>
<th colspan="3">Values</th>
<th rowspan="2">Unit</th>
<th rowspan="2">Note or Test Condition</th>
<th rowspan="2">Number</th>
</tr>
<tr>
<th>Min.</th>
<th>Typ.</th>
<th>Max.</th>
</tr>
<tr>
<td>Thermal Characterization Parameter Junction-Top</td>
<td>Y JTOP</td>
<td>–</td>
<td>3</td>
<td>5</td>
<td>K/W</td>
<td>2)</td>
<td>P_4.4.0.1</td>
</tr>
<tr>
<td>Thermal Resistance Junction-to-Case</td>
<td>RthJC</td>
<td>–</td>
<td>1.4</td>
<td>2.4</td>
<td>K/W</td>
<td>2) simulated at exposed pad</td>
<td>P_4.4.0.2</td>
</tr>
<tr>
<td>Thermal Resistance Junction-to-Ambient</td>
<td>RthJA</td>
<td>–</td>
<td>31.8</td>
<td>–</td>
<td>K/W</td>
<td>2)</td>
<td>P_4.4.0.3</td>
</tr>
</table>

1\) Not subject to production test - specified by design.

2\) According to Jedec JESD51-2,-5,-7 at natural convection on FR4 2s2p board; the Product (Chip + Package) was
simulated on a 76.2 × 114.3 x 1.5 mm board with 2 inner copper layers (2 x 70 um Cu, 2 x 35 um Cu). Where applicable
a thermal via array under the exposed pad contacted the first inner copper layer. Simulation done at TA = 105℃,
PDISSIPATION = 1 W.

### 4.4.1 PCB Setup

<figure>
<figcaption>Figure 5 1s0p PCB Cross Section</figcaption>

70 um modeled (traces, cooling area)

1,5 mm

70 um, 5% metalization*

*: means percentual Cu metalization on each layer

PCB_Zth_1s0p.emf

</figure>

<figure>
<figcaption>Figure 6 2s2p PCB Cross Section</figcaption>

70 um modeled (traces)

1,5 mm

35 um, 90% metalization*

35 um, 90% metalization*

70 um, 5% metalization*

*: means percentual Cu metalization on each layer

PCB_Zth_2s2p.emf

</figure>

<!-- PageFooter="Data Sheet" -->
<!-- PageNumber="10" -->
<!-- PageFooter="Rev. 1.03 2019-10-15" -->
<!-- PageBreak -->

<!-- PageNumber="Side 11" -->

<!-- PageHeader="BTS7004-1EPP PROFET™+2 12V" -->

<figure>

Infineon

</figure>

#### General Product Characteristics

<figure>
<figcaption>Figure 7 PCB setup for thermal simulations</figcaption>

FE

JEDEC 1s0p / 600mm2

JEDEC 150p / footprint
JEDEC 252p

PCB 1s0p + 600 mm2 cooling

PCB 2s2p / 1s0p footprint

PCB_sim_setup_TSDSO14.emf

</figure>

<figure>
<figcaption>Figure 8 Thermal vias on PCB for 2s2p PCB setup</figcaption>

Solder Pads
Vias

PCB_2s2p_vias_TSDSO14.emf

</figure>

<!-- PageFooter="Data Sheet" -->
<!-- PageNumber="11" -->
<!-- PageFooter="Rev. 1.03 2019-10-15" -->
<!-- PageBreak -->

<!-- PageNumber="Side 12" -->

<!-- PageHeader="BTS7004-1EPP PROFET™+2 12V" -->

<figure>

Infineon

</figure>

# General Product Characteristics

## 4.4.2 Thermal Impedance

<figure>
<figcaption>Figure 9 Typical Thermal Impedance. PCB setup according Chapter 4.4.1</figcaption>

BTS7004-1EPx

100

10

ZthJA (K/W)

TA = 105℃

1

2s2p

1sOp - 600 mm2

1s0p - 300 mm2

1s0p - footprint

0,1

0,0001

0,001

0,01

0,1

1

10

Time (s)

100

1000

</figure>

<figure>
<figcaption>Figure 10 Thermal Resistance on 1s0p PCB with various cooling surfaces</figcaption>

BTS7004-1EPx

120

1sOp - Ta = 105℃

110

100

90

RthJA (K/W)

80

70

60

50

40

30

0

100

200

300

400

500

600

Cooling area (mm2)

</figure>

<!-- PageFooter="Data Sheet" -->
<!-- PageNumber="12" -->
<!-- PageFooter="Rev. 1.03 2019-10-15" -->
<!-- PageBreak -->

<!-- PageNumber="Side 13" -->

<figure>

<!-- PageHeader="Infineon" -->

</figure>

<!-- PageHeader="BTS7004-1EPP PROFET™+2 12V" -->

Logic Pins

# 5 Logic Pins

The device has 2 digital pins.

## 5.1 Input Pin (IN)

The input pin IN activates the output channel. The input circuitry is compatible with 3.3V and 5V
microcontroller (see Chapter 10 for the complete application setup overview). The electrical equivalent of the
input circuitry is shown in Figure 11. In case the pin is not used, it should be pulled to module GND or device
GND pin via RIN = 4.7 kQ2.

<figure>
<figcaption>Figure 11 Input circuitry</figcaption>

VS

IN

IDI

VS(CLAMP)

ESD

/DI

VDI(CLAMP)

VDI

GND

IGND

RGND

Input_IN_INTDIO.emf

</figure>

The logic thresholds for "low" and "high" states are defined by parameters VDI(TH) and VDI(HYS). The relationship
between these two values is shown in Figure 12. The voltage VIN needed to ensure a "high" state is always
higher than the voltage needed to ensure a "low" state.

<figure>
<figcaption>Figure 12 Input Threshold voltages and hysteresis</figcaption>

VDI 4

VDI(TH ),MAX

VDI(TH)

VDI(HYS)

VD(TH ) MIN

t

Internal channel
activation signal

0

x
☒

1

x
☒

0

t

Input_VDITH_2.emf

</figure>

<!-- PageFooter="Data Sheet" -->
<!-- PageNumber="13" -->
<!-- PageFooter="Rev. 1.03 2019-10-15" -->
<!-- PageBreak -->

<!-- PageNumber="Side 14" -->

<figure>

Infineon

</figure>

<!-- PageHeader="BTS7004-1EPP PROFET™+2 12V" -->

Logic Pins

## 5.2 Diagnosis Pin

The Diagnosis Enable (DEN) pin controls the diagnosis circuitry and can be used to reset the latched protection
(Protection circuitry not disabled by DEN). When DEN pin is set to "high", the diagnosis is enabled (see
Chapter 9.2 for more details). When it is set to "low", the diagnosis is disabled (IS pin is set to high
impedance).

The transition from "high" to "low" of DEN pin clears the protection latch of the channel depending on the
logic state of IN pin and DEN pulse length (see Chapter 8.3 for more details). The internal structure of
diagnosis pins is the same as the one of input pins. See Figure 11 for more details.

## 5.3 Electrical Characteristics Logic Pins

Vs = 6 V to 18 V, TJ =- 40 °C to +150 ℃
Typical values: Vs = 13.5 V, TJ= 25 ℃

Digital Input (DI) pins = IN, DEN

<table>
<caption>Table 7 Electrical Characteristics: Logic Pins - General</caption>
<tr>
<th rowspan="2">Parameter</th>
<th rowspan="2">Symbol</th>
<th colspan="3">Values</th>
<th rowspan="2">Unit</th>
<th rowspan="2">Note or Test Condition</th>
<th rowspan="2">Number</th>
</tr>
<tr>
<th>Min.</th>
<th>Typ.</th>
<th>Max.</th>
</tr>
<tr>
<td>Digital Input Voltage Threshold</td>
<td>VDI(TH)</td>
<td>0.8</td>
<td>1.3</td>
<td>2</td>
<td>V</td>
<td>See Figure 11 and Figure 12</td>
<td>P_5.4.0.1</td>
</tr>
<tr>
<td>Digital Input Clamping Voltage</td>
<td>DI(CLAMP1)</td>
<td>-</td>
<td>7</td>
<td>-</td>
<td>V</td>
<td>1) IDI = 1 mA See Figure 11 and Figure 12</td>
<td>P_5.4.0.2</td>
</tr>
<tr>
<td>Digital Input Clamping Voltage</td>
<td>DI(CLAMP2)</td>
<td>6.5</td>
<td>7.5</td>
<td>8.5</td>
<td>V</td>
<td>IDI = 2 mA See Figure 11 and Figure 12</td>
<td>P_5.4.0.3</td>
</tr>
<tr>
<td>Digital Input Hysteresis</td>
<td>VDI(HYS)</td>
<td>–</td>
<td>0.25</td>
<td>–</td>
<td>V</td>
<td>1) See Figure 11 and Figure 12</td>
<td>P_5.4.0.4</td>
</tr>
<tr>
<td>Digital Input Current ("high")</td>
<td>IDI(H)</td>
<td>2</td>
<td>10</td>
<td>25</td>
<td>HA</td>
<td>VDI = 2 V See Figure 11 and Figure 12</td>
<td>P_5.4.0.5</td>
</tr>
<tr>
<td>Digital Input Current ("low")</td>
<td>/DI(L)</td>
<td>2</td>
<td>10</td>
<td>25</td>
<td>µA</td>
<td>VDI = 0.8 V See Figure 11 and Figure 12</td>
<td>P_5.4.0.6</td>
</tr>
</table>

1\) Not subject to production test - specified by design.

<!-- PageFooter="Data Sheet" -->
<!-- PageNumber="14" -->
<!-- PageFooter="Rev. 1.03 2019-10-15" -->
<!-- PageBreak -->

<!-- PageNumber="Side 15" -->

<figure>

Infineon

</figure>

<!-- PageHeader="BTS7004-1EPP PROFET™+2 12V" -->

Power Supply

# 6 Power Supply

The BTS7004-1EPP is supplied by Vs, which is used for the internal logic as well as supply for the power output
stage. Vs has an undervoltage detection circuit, which prevents the activation of the power output stage and
diagnosis in case the applied voltage is below the undervoltage threshold (Vs < VS(op)). During power up, the
internal power on signal is set when supply voltage (Vs) exceeds the minimum operating voltage (Vs > VS(OP).

## 6.1 Operation Modes

BTS7004-1EPP has the following operation modes in case of Vs > VS(OP):

· OFF mode

· ON mode

· Diagnosis in ON mode

· Diagnosis in OFF mode

· Fault

The transition between operation modes is determined according to these variables:

· Logic level at IN pin

· Logic level at DEN pin

· Internal latch

· Sense current lis level

The truth table in case of Vs > Vs(op) is shown in Table 8. The behavior of BTS7004-1EPP as well as some
parameters may change in dependence on the operation mode of the device.

There are three parameters describing each operation mode of BTS7004-1EPP:

· Status of the output channel

· Status of the diagnosis

· Current consumption at VS pin (measured by lys in OFF mode, IGND in all other operative modes)

<table>
<caption>Table 8 Operation Mode truth table</caption>
<tr>
<th>IN</th>
<th>DEN</th>
<th>Internal latch</th>
<th>lis</th>
<th>Operative Mode</th>
<th>Comment</th>
</tr>
<tr>
<td>L</td>
<td>L</td>
<td>L</td>
<td>leakage</td>
<td>OFF</td>
<td>DMOS channel is OFF</td>
</tr>
<tr>
<td>L</td>
<td>L</td>
<td>H</td>
<td>leakage</td>
<td>OFF</td>
<td>DMOS channel is OFF</td>
</tr>
<tr>
<td rowspan="2">L</td>
<td>H</td>
<td>L</td>
<td>leakage</td>
<td rowspan="3">OFF_DIAG</td>
<td>Diagnostic in OFF-mode</td>
</tr>
<tr>
<td></td>
<td></td>
<td>open load</td>
<td>Diagnostic in OFF-mode</td>
</tr>
<tr>
<td>L</td>
<td>H</td>
<td>H</td>
<td>fault</td>
<td>Diagnostic in OFF-mode</td>
</tr>
<tr>
<td>H</td>
<td>L</td>
<td>L</td>
<td>leakage</td>
<td>ON</td>
<td>DMOS channel is ON, no diagnostic</td>
</tr>
<tr>
<td>H</td>
<td>L</td>
<td>H</td>
<td>leakage</td>
<td>fault</td>
<td>DMOS channel is switched OFF due to failure</td>
</tr>
<tr>
<td>H</td>
<td>H</td>
<td>L</td>
<td>Ils</td>
<td>ON_DIAG</td>
<td>DMOS channel is ON and diagnostic</td>
</tr>
<tr>
<td>H</td>
<td>H</td>
<td>H</td>
<td>fault</td>
<td>fault</td>
<td>DMOS channel is switched OFF due to failure</td>
</tr>
</table>

<!-- PageFooter="Data Sheet" -->
<!-- PageNumber="15" -->
<!-- PageFooter="Rev. 1.03 2019-10-15" -->
<!-- PageBreak -->

<!-- PageNumber="Side 16" -->

<figure>

Infineon

</figure>

<!-- PageHeader="BTS7004-1EPP PROFET™+2 12V" -->

Power Supply

### 6.1.1 OFF mode

When BTS7004-1EPP is in OFF mode, the output channel is OFF. The current consumption is minimum (see
parameter /vs(OFF). No Overtemperature, Overload protection mechanism and no diagnosis function is active
when the device is in OFF mode.

### 6.1.2 ON mode

ON (IN = High; DEN = Low) mode is the normal operation mode of BTS7004-1EPP. Device current consumption
is specified with IGND(ON_D) + /IS(OFF) (measured at GND pin because the current at VS pin includes the load
current). Overcurrent and Overtemperature protections are active. No diagnosis function is active.

### 6.1.3 OFF_Diag mode

The device is in OFF_Diag mode as long as DEN pin is set to "high" and IN pin is set to "low". The output
channel is OFF. If an open load case happens, an Open Load in OFF current /IS(OLOFF) may be present at IS pin.
In such situation, the current consumption of the device is increased.

### 6.1.4 ON_Diag mode

The device is in normal ON mode with current sense function. lis or /IS(FAULT) will be present at IS pin. Device
current consumption is specified with IGND(ON_D). Depending on the load condition, either a fault current
VIS(FAULT) or /Is current may be present at IS pin.

### 6.1.5 Fault mode

The device is in Fault mode as soon as a protection event happens which affects that the device switches off
due to its protection function. In Fault mode, a /IS(FAULT) signal is presenting at IS pin during the DEN signal is
"high".

## 6.2 Undervoltage on Vs

Between Vs(OP) and Vs(uv) the undervoltage mechanism is triggered. If the device is operative (in ON mode) and
the supply voltage drops below the undervoltage threshold Vs(uv), the internal logic switches OFF the output
channel.

As soon as the supply voltage Vs is above the operative threshold Vs(op), the channel is switched ON again. The
restart is delayed with a time tDELAY(Uv) which protects the device in case the undervoltage condition is caused
by a short circuit event (according to AEC-Q100-012), as shown in Figure 13.

If the device is in OFF mode and the input is set to "high", the channel will be switched ON if Vs > VS(op) without
waiting for tDELAY(UV)·

<!-- PageFooter="Data Sheet" -->
<!-- PageNumber="16" -->
<!-- PageFooter="Rev. 1.03 2019-10-15" -->
<!-- PageBreak -->

<!-- PageNumber="Side 17" -->

<!-- PageHeader="BTS7004-1EPP PROFET™+2 12V" -->

<figure>

Infineon

</figure>

### Power Supply

<figure>
<figcaption>Figure 13 Vs undervoltage behavior</figcaption>

Vs

VS(OP)

1 VS(HYS)

Vs(Uv)

t

Channel
activation signal

t

VOUT

tDELAY(UV)

t

Power Supply_UVRVS.emf

</figure>

<!-- PageFooter="Data Sheet" -->
<!-- PageNumber="17" -->
<!-- PageFooter="Rev. 1.03 2019-10-15" -->
<!-- PageBreak -->

<!-- PageNumber="Side 18" -->

<figure>

Infineon

</figure>

<!-- PageHeader="BTS7004-1EPP PROFET™+2 12V" -->

Power Supply

## 6.3 Electrical Characteristics Power Supply

Vs = 6 V to 18 V, TJ =- 40 °C to +150 ℃

Typical values: Vs = 13.5 V, TJ= 25 °℃

Typical resistive load connected to the output for testing (unless otherwise specified):

RL = 2.1 22

<table>
<caption>Table 9 Electrical Characteristics: Power Supply - General</caption>
<tr>
<th rowspan="2">Parameter</th>
<th rowspan="2">Symbol</th>
<th colspan="3">Values</th>
<th rowspan="2">Unit</th>
<th rowspan="2">Note or Test Condition</th>
<th rowspan="2">Number</th>
</tr>
<tr>
<th>Min.</th>
<th>Typ.</th>
<th>Max.</th>
</tr>
<tr>
<td colspan="2">VS pin</td>
<td colspan="5"></td>
<td></td>
</tr>
<tr>
<td>Power Supply Undervoltage Shutdown</td>
<td>VS(UV)</td>
<td>1.8</td>
<td>2.3</td>
<td>3.1</td>
<td>V</td>
<td>Vs decreasing IN = "high" From Vps ≤ 0.5 V to VDS=Vs See Figure 13</td>
<td>P_6.4.0.1</td>
</tr>
<tr>
<td>Power Supply Minimum Operating Voltage</td>
<td>VS(OP)</td>
<td>2.0</td>
<td>3.0</td>
<td>4.1</td>
<td>V</td>
<td>Vs increasing IN = "high" From VDs = Vs to VDS ≤ 0.5V See Figure 13</td>
<td>P_6.4.0.3</td>
</tr>
<tr>
<td>Power Supply Undervoltage Shutdown Hysteresis</td>
<td>VS(HYS)</td>
<td>–</td>
<td>0.7</td>
<td>–</td>
<td>V</td>
<td>1) VS(OP) - Vs(Uv) See Figure 13</td>
<td>P_6.4.0.6</td>
</tr>
<tr>
<td>Power Supply Undervoltage Recovery Time</td>
<td>ťDELAY(UV)</td>
<td>2.5</td>
<td>5</td>
<td>7.5</td>
<td>ms</td>
<td>dVs/dt ≤0.5 V/us Vs2 -1V See Figure 13</td>
<td>P_6.4.0.7</td>
</tr>
<tr>
<td>Breakdown Voltage between GND and VS Pins in Reverse Battery</td>
<td>-VS(REV)</td>
<td>16</td>
<td>–</td>
<td>30</td>
<td>V</td>
<td>1) IGND(REV) = 7 mA TJ=150 ℃</td>
<td>P_6.4.0.9</td>
</tr>
</table>

1\) Not subject to production test - specified by design.

<!-- PageFooter="Data Sheet" -->
<!-- PageNumber="18" -->
<!-- PageFooter="Rev. 1.03 2019-10-15" -->
<!-- PageBreak -->

<!-- PageNumber="Side 19" -->

<figure>

Infineon

</figure>

<!-- PageHeader="BTS7004-1EPP PROFET™+2 12V" -->

Power Supply

## 6.4 Electrical Characteristics Power Supply - Product Specific

Vs = 6 V to 18 V, TJ =- 40 °C to +150 ℃

Typical values: Vs = 13.5 V, TJ= 25 ℃

Typical resistive load connected to the output for testing (unless otherwise specified):
RL = 2.1 22

### 6.4.1 BTS7004-1EPP

<table>
<caption>Table 10 Electrical Characteristics: Power Supply BTS7004-1EPP</caption>
<tr>
<th rowspan="2">Parameter</th>
<th rowspan="2">Symbol</th>
<th colspan="3">Values</th>
<th rowspan="2">Unit</th>
<th rowspan="2">Note or Test Condition</th>
<th rowspan="2">Number</th>
</tr>
<tr>
<th>Min.</th>
<th>Typ.</th>
<th>Max.</th>
</tr>
<tr>
<td>Supply Current Consumption in OFF Mode with Loads</td>
<td>VS(OFF)_85</td>
<td>–</td>
<td>0.05</td>
<td>0.5</td>
<td>µA</td>
<td>1) Vs = 18 V VOUT = 0 V IN = DEN = "low" TJ ≤85°℃</td>
<td>P_6.5.21.1</td>
</tr>
<tr>
<td>Supply Current Consumption in OFF Mode with Loads</td>
<td>Ivs(OFF)_150</td>
<td>–</td>
<td>5</td>
<td>20</td>
<td>µA</td>
<td>Vs = 18 V VOUT = 0 V IN = DEN = "low" TJ=150 ℃</td>
<td>P_6.5.21.2</td>
</tr>
<tr>
<td>Operating Current in ON_Diag Mode (Channel ON)</td>
<td>İGND(ON_D)</td>
<td>–</td>
<td>2</td>
<td>3</td>
<td>mA</td>
<td>Vs = 18 V IN = DEN = “high"</td>
<td>P_6.5.21.3</td>
</tr>
<tr>
<td>Operating Current in OFF_Diag Mode</td>
<td>‘GND(OFF_D)</td>
<td>–</td>
<td>1.2</td>
<td>1.8</td>
<td>mA</td>
<td>Vs = 18 V IN = "low"; DEN = "high"</td>
<td>P_6.5.21.5</td>
</tr>
</table>

1\) Not subject to production test - specified by design.

<!-- PageFooter="Data Sheet" -->
<!-- PageNumber="19" -->
<!-- PageFooter="Rev. 1.03 2019-10-15" -->
<!-- PageBreak -->

<!-- PageNumber="Side 20" -->

<figure>

Infineon

</figure>

<!-- PageHeader="BTS7004-1EPP PROFET™+2 12V" -->

# Power Stages

## 7 Power Stages

The high-side power stage is built using a N-channel vertical Power MOSFET with charge pump.

### 7.1 Output ON-State Resistance

The ON-state resistance RDS(ON) depends mainly on junction temperature TJ. Figure 14 shows the variation of
RDS(ON) across the whole T, range. The value "2" on the y-axis corresponds to the maximum RDS(ON) measured
at TJ = 150 ℃.

<figure>
<figcaption>Figure 14 RDS(ON) variation factor</figcaption>

RDS(ON) variation over TJ

2.20

Reference value:

2.00

"2"=RDS(ON),MAX@150 ℃

1.80

1.60

RDS(ON) variation factor

1.40

1.20

1.00

0.80

0.60

0.40

0.20

Typical

0.00

-40

-30

-20

-10

0

10

20

30

40

50

60

70

80

90

100

110

120

130

140

150

160

Junction Temperature (℃)

</figure>

The behavior in Reverse Polarity is described in Chapter 8.4.1.

### 7.2 Switching loads

#### 7.2.1 Switching Resistive Loads

When switching resistive loads, the switching times and slew rates shown in Figure 15 can be considered. The
switch energy values EON and EOFF are proportional to load resistance and times ton and tOFF.

<!-- PageFooter="Data Sheet" -->
<!-- PageNumber="20" -->
<!-- PageFooter="Rev. 1.03 2019-10-15" -->
<!-- PageBreak -->

<!-- PageNumber="Side 21" -->

<figure>

Infineon

</figure>

<!-- PageHeader="BTS7004-1EPP PROFET™+2 12V" -->

##### Power Stages

<figure>
<figcaption>Figure 15 Switching a Resistive Load</figcaption>

IN

VIN(TH)

VIN (HYS)

t

VOUT

90% of Vs

ton

tOFF(DELAY)

70% of Vs

70% of Vs

(dV/dt)ON

-(dV/dt)OFF

30% of Vs

30% of Vs

10% of Vs

tON(DELAY)

tOFF

t

PDMOS

EON

EOFF

t

Power Stage_SwitchRes.emf

</figure>

#### 7.2.2 Switching Inductive Loads

When switching OFF inductive loads with high-side switches, the voltage VOUT drops below ground potential,
because the inductance intends to continue driving the current. To prevent the destruction of the device due
to overvoltage, a voltage clamp mechanism is implemented. The clamping structure limits the negative
output voltage so that VDs = VDS(CLAMP). Figure 16 shows a concept drawing of the implementation. The
clamping structure is available in all operation modes listed in Chapter 6.1.

<figure>
<figcaption>Figure 16 Output Clamp concept</figcaption>

Vs

High-side
Channel

VS

VDS

VSIS(CLAMP)

VDS(CLAMP)

IS

IL

VS(CLAMP)

OUT

VOUT

RSENSE

GND

L,

RL

RGND

PowerStage_Clamp_INTDIO_1CH.emf

</figure>

<!-- PageFooter="Data Sheet" -->
<!-- PageNumber="21" -->
<!-- PageFooter="Rev. 1.03 2019-10-15" -->
<!-- PageBreak -->

<!-- PageNumber="Side 22" -->

<!-- PageHeader="BTS7004-1EPP PROFET™+2 12V" -->

<figure>

Infineon

</figure>

##### Power Stages

During demagnetization of inductive loads, energy has to be dissipated in BTS7004-1EPP. The energy can be
calculated with Equation (7.1):

VS-VDS(CLAMP)

E = VDS(CLAMP)
⋅
–
L
I
RL
· In(1
VS - VDS(CLAMP)
⎞
+
L
(7.1)

The maximum energy, therefore the maximum inductance for a given current, is limited by the thermal design
of the component. Please refer to Chapter 4.2 for the maximum allowed values of EAs (single pulse energy)
and EAR (repetitive energy).

#### 7.2.3 Output Voltage Limitation

To increase the current sense accuracy, Vps voltage is monitored. When the output current /_ decreases while
the channel is diagnosed (DEN pin set to "high" - see Figure 17) bringing Vps equal or lower than VDS(SLC), the
output DMOS gate is partially discharged. This increases the output resistance so that VDs = VDS(SLC) even for
very small output currents. The Vps increase allows the current sensing circuitry to work more efficiently,
providing better kILIs accuracy for output current in the low range.

<figure>
<figcaption>Figure 17 Output Voltage Limitation activation during diagnosis</figcaption>

IN

t

DEN

IL

t

VDS

t

Vs

VDS(SLC)

t

PowerStage_GBR_diag_HEAT.emf

</figure>

### 7.3 Advanced Switching Characteristics

#### 7.3.1 Inverse Current behavior

When VOUT > Vs, a current /INy flows into the power output transistor (see Figure 18). This condition is known
as "Inverse Current".

If the channel is in OFF state, the current flows through the intrinsic body diode generating high power losses
therefore an increase of overall device temperature. If the channel is in ON state, RDS(INV) can be expected and
power dissipation in the output stage is comparable to normal operation in RDS(ON).

During Inverse Current condition, the channel remains in ON or OFF state as long as |-4| |-[INV) .

With InverseON, it is possible to switch ON the channel during Inverse Current condition as long as |-| -|- L(INV]
(see Figure 19).

<!-- PageFooter="Data Sheet" -->
<!-- PageNumber="22" -->
<!-- PageFooter="Rev. 1.03 2019-10-15" -->
<!-- PageBreak -->

<!-- PageNumber="Side 23" -->

<!-- PageHeader="BTS7004-1EPP PROFET™+2 12V" -->

<figure>

<!-- PageHeader="Infineon" -->

</figure>

##### Power Stages

<figure>
<figcaption>Figure 18 Inverse Current Circuitry</figcaption>

VBAT

Vs

Gate
Driver

Device
Logic

INV
Comp.

-IL

VOUT>VS

OUT

GND

RGND
RGND

PowerStage_Inverse_HEAT.emf

</figure>

<figure>
<figcaption>Figure 19 InverseON - Channel behavior in case of applied Inverse Current</figcaption>

IN

CASE 1 : Switch is ON

IN

CASE 2 : Switch is OFF

ON

OFF

t

t

IL

IL

NORMAL

NORMAL

NORMAL

NORMAL

t

t

INVERSE

INVERSE

DMOS state

DMOS state

ON

OFF

t

t

CASE 3 : Switch ON into Inverse Current

CASE 4 : Switch OFF into Inverse Current

IN

IN

OFF

ON

ON

OFF

t

t

IL

IL

NORMAL

NORMAL

NORMAL

NORMAL

t

t

INVERSE

INVERSE

DMOS state

DMOS state

OFF

ON

ON

OFF

t

t

PowerStage_InvCurr_INVON.emf

</figure>

Note:
No protection mechanism like Overtemperature or Overload protection is active during applied
Inverse Currents.

<!-- PageFooter="Data Sheet" -->
<!-- PageNumber="23" -->
<!-- PageFooter="Rev. 1.03 2019-10-15" -->
<!-- PageBreak -->

<!-- PageNumber="Side 24" -->

<!-- PageHeader="BTS7004-1EPP PROFET™+2 12V" -->

<figure>

Infineon

</figure>

# Power Stages

## 7.3.2 Cross Current robustness with H-Bridge configuration

When BTS7004-1EPP is used as high-side switch e.g. in a bridge configuration (therefore paired with a low-side
switch as shown in Figure 20), the maximum slew rate applied to the output by the low-side switch must be
lower than | dVOUT / dt |. Otherwise the output stage may turn ON in linear mode (not in RDS(ON)) while the low-
side switch is commutating. This creates an unprotected overheating for the DMOS due to the cross-
conduction current.

<figure>
<figcaption>Figure 20 High-Side switch used in Bridge configuration</figcaption>

VBAT

R/L cable

HSS 1

HSS 2

VS

VS

T

T

ON (DC)

IN

IN

OFF

OUT

OUT

dVour / dt

Current through Motor

Cross
Current

M

ON (PWM)

OFF

PowerStage_PassiveSlew_PROFET1Ch.emf

</figure>

<!-- PageFooter="Data Sheet" -->
<!-- PageNumber="24" -->
<!-- PageFooter="Rev. 1.03 2019-10-15" -->
<!-- PageBreak -->

<!-- PageNumber="Side 25" -->

<figure>

Infineon

</figure>

<!-- PageHeader="BTS7004-1EPP PROFET™+2 12V" -->

Power Stages

### 7.4 Electrical Characteristics Power Stages

Vs = 6 V to 18 V, T] = - 40 °C to +150 ℃

Typical values: Vs = 13.5 V, TJ= 25 °℃

Typical resistive load connected to the output for testing (unless otherwise specified):

RL = 2.1 22

<table>
<caption>Table 11 Electrical Characteristics: Power Stages - General</caption>
<tr>
<th rowspan="2">Parameter</th>
<th rowspan="2">Symbol</th>
<th colspan="3">Values</th>
<th rowspan="2">Unit</th>
<th rowspan="2">Note or Test Condition</th>
<th rowspan="2">Number</th>
</tr>
<tr>
<th>Min.</th>
<th>Typ.</th>
<th>Max.</th>
</tr>
<tr>
<td>Voltages</td>
<td></td>
<td></td>
<td></td>
<td></td>
<td></td>
<td></td>
<td></td>
</tr>
<tr>
<td>Drain to Source Clamping Voltage at TJ = - 40 ℃</td>
<td>VDS(CLAMP) _- 40</td>
<td>33</td>
<td>36.5</td>
<td>42</td>
<td>V</td>
<td>/L = 5 mA TJ =- 40ºC See Figure 16</td>
<td>P_7.4.0.1</td>
</tr>
<tr>
<td>Drain to Source Clamping Voltage at TJ ≥ 25 °℃</td>
<td>VDS(CLAMP)_25</td>
<td>35</td>
<td>38</td>
<td>44</td>
<td>V</td>
<td>1) /L = 5 mA TJ ≥ 25°C See Figure 16</td>
<td>P_7.4.0.2</td>
</tr>
</table>

1\) Tested at TJ = 150°C.

#### 7.4.1 Electrical Characteristics Power Stages

<table>
<caption>Table 12 Electrical Characteristics: Power Stages</caption>
<tr>
<th rowspan="2">Parameter</th>
<th rowspan="2">Symbol</th>
<th colspan="3">Values</th>
<th rowspan="2">Unit</th>
<th rowspan="2">Note or Test Condition</th>
<th rowspan="2">Number</th>
</tr>
<tr>
<th>Min.</th>
<th>Typ.</th>
<th>Max.</th>
</tr>
<tr>
<td>Timings</td>
<td></td>
<td></td>
<td></td>
<td></td>
<td></td>
<td></td>
<td></td>
</tr>
<tr>
<td>Switch-ON Delay</td>
<td>tON(DELAY)</td>
<td>10</td>
<td>70</td>
<td>130</td>
<td>μς</td>
<td>Vs = 13.5 V VOUT = 10% VS</td>
<td>P_7.4.5.1</td>
</tr>
<tr>
<td>Switch-OFF Delay</td>
<td>tOFF(DELAY)</td>
<td>10</td>
<td>50</td>
<td>160</td>
<td>μς</td>
<td>Vs = 13.5 V VOUT = 90% VS</td>
<td>P_7.4.5.2</td>
</tr>
<tr>
<td>Switch-ON Time</td>
<td>ton</td>
<td>50</td>
<td>130</td>
<td>210</td>
<td>μς</td>
<td>Vs = 13.5 V VOUT = 90% VS</td>
<td>P_7.4.5.3</td>
</tr>
<tr>
<td>Switch-OFF Time</td>
<td>tOFF</td>
<td>30</td>
<td>100</td>
<td>220</td>
<td>μς</td>
<td>Vs = 13.5 V VOUT = 10% VS</td>
<td>P_7.4.5.4</td>
</tr>
<tr>
<td>Switch-ON/OFF Matching ton - tOFF</td>
<td>Atsw</td>
<td>-60</td>
<td>25</td>
<td>90</td>
<td>μς</td>
<td>Vs = 13.5 V</td>
<td>P_7.4.5.5</td>
</tr>
<tr>
<td colspan="8">Voltage Slope</td>
</tr>
<tr>
<td>Switch-ON Slew Rate</td>
<td>(dV/dt) ON</td>
<td>0.16</td>
<td>0.27</td>
<td>0.39</td>
<td>V/us</td>
<td>Vs = 13.5 V VOUT = 30% to 70% of Vs</td>
<td>P_7.4.5.6</td>
</tr>
<tr>
<td>Switch-OFF Slew Rate</td>
<td>-(dV/dt) OFF</td>
<td>0.16</td>
<td>0.27</td>
<td>0.39</td>
<td>V/us</td>
<td>Vs = 13.5 V VOUT = 70% to 30% of Vs</td>
<td>P_7.4.5.7</td>
</tr>
</table>

<!-- PageFooter="Data Sheet" -->
<!-- PageNumber="25" -->
<!-- PageFooter="Rev. 1.03 2019-10-15" -->
<!-- PageBreak -->

<!-- PageNumber="Side 26" -->

<figure>

Infineon

</figure>

<!-- PageHeader="BTS7004-1EPP PROFET™+2 12V" -->

# Power Stages

<table>
<caption>Table 12 Electrical Characteristics: Power Stages (continued)</caption>
<tr>
<th rowspan="2">Parameter</th>
<th rowspan="2">Symbol</th>
<th colspan="3">Values</th>
<th rowspan="2">Unit</th>
<th rowspan="2">Note or Test Condition</th>
<th rowspan="2">Number</th>
</tr>
<tr>
<th>Min.</th>
<th>Typ.</th>
<th>Max.</th>
</tr>
<tr>
<td>Slew Rate Matching (dV/dt) ON - (dV/dt) OFF</td>
<td>A(dV/dt)sw</td>
<td>-0.15</td>
<td>0</td>
<td>+0.15</td>
<td>V/us</td>
<td>Vs = 13.5 V</td>
<td>P_7.4.5.8</td>
</tr>
<tr>
<td colspan="8">Voltages</td>
</tr>
<tr>
<td>Output Voltage Drop Limitation at Small Load Currents</td>
<td>VDS(SLC)</td>
<td>2</td>
<td>10</td>
<td>20</td>
<td>mV</td>
<td>1) "OUT = "OUT(OL) =20 mA</td>
<td>P_7.4.5.9</td>
</tr>
</table>

1\) Not subject to production test - specified by design

## 7.5 Electrical Characteristics - Power Output Stages

Vs = 6 V to 18 V, T] =- 40 ℃ to +150 ℃

Typical values: Vs = 13.5 V, TJ= 25 ℃

Typical resistive load connected to the output for testing (unless otherwise specified):

RL = 2.12

### 7.5.1 Power Output Stage - 4 m22

<table>
<caption>Table 13 Electrical Characteristics: Power Stages - 4 m22</caption>
<tr>
<th rowspan="2">Parameter</th>
<th rowspan="2">Symbol</th>
<th colspan="3">Values</th>
<th rowspan="2">Unit</th>
<th rowspan="2">Note or Test Condition</th>
<th rowspan="2">Number</th>
</tr>
<tr>
<th>Min.</th>
<th>Typ.</th>
<th>Max.</th>
</tr>
<tr>
<td>Output characteristics</td>
<td></td>
<td></td>
<td></td>
<td></td>
<td></td>
<td></td>
<td></td>
</tr>
<tr>
<td>ON-State Resistance at TJ =25 ℃</td>
<td>RDS(ON)_25</td>
<td>–</td>
<td>4.4</td>
<td>–</td>
<td>m22</td>
<td>1) TJ =25 ℃</td>
<td>P_7.5.11.1</td>
</tr>
<tr>
<td>ON-State Resistance at TJ=150 ℃</td>
<td>RDS(ON)_150</td>
<td>-</td>
<td>-</td>
<td>8</td>
<td>m22</td>
<td>TJ=150 ℃</td>
<td>P_7.5.11.2</td>
</tr>
<tr>
<td>ON-State Resistance in Cranking</td>
<td>RDS(ON)_CRAN K</td>
<td>–</td>
<td>–</td>
<td>10</td>
<td>mQ2</td>
<td>TJ =150 ℃ Vs = 3.1 V</td>
<td>P_7.5.11.3</td>
</tr>
<tr>
<td>ON-State Resistance in Inverse Current at Ty = 25 ℃</td>
<td>RDS(INV)_25</td>
<td>–</td>
<td>4.5</td>
<td>–</td>
<td>m22</td>
<td>1) TJ =25 ℃ Vs = 13.5 V /L =- 4A DEN = "low" see Figure 18</td>
<td>P_7.5.11.4</td>
</tr>
<tr>
<td>ON-State Resistance in Inverse Current at TJ = 150 ℃</td>
<td>RDS(INV)_150</td>
<td>–</td>
<td>–</td>
<td>10</td>
<td>mQ2</td>
<td>TJ =150 ℃ Vs = 13.5 V /L =- 4A DEN = "low" see Figure 18</td>
<td>P_7.5.11.5</td>
</tr>
</table>

<!-- PageFooter="Data Sheet" -->
<!-- PageNumber="26" -->
<!-- PageFooter="Rev. 1.03 2019-10-15" -->
<!-- PageBreak -->

<!-- PageNumber="Side 27" -->

<figure>

Infineon

</figure>

<!-- PageHeader="BTS7004-1EPP PROFET™+2 12V" -->

Power Stages

<table>
<caption>Table 13 Electrical Characteristics: Power Stages - 4 m22 (continued)</caption>
<tr>
<th rowspan="2">Parameter</th>
<th rowspan="2">Symbol</th>
<th colspan="3">Values</th>
<th rowspan="2">Unit</th>
<th rowspan="2">Note or Test Condition</th>
<th rowspan="2">Number</th>
</tr>
<tr>
<th>Min.</th>
<th>Typ.</th>
<th>Max.</th>
</tr>
<tr>
<td>ON-State Resistance in Reverse Polarity at TJ = 25 ℃</td>
<td>RDS(REV)_25</td>
<td>–</td>
<td>9.5</td>
<td>–</td>
<td>m22</td>
<td>1) TJ =25 ℃ Vs =- 13.5 V /L =- 4A see Figure 29</td>
<td>P_7.5.11.6</td>
</tr>
<tr>
<td>ON-State Resistance in Reverse Polarity at TJ = 150 ℃</td>
<td>RDS(REV)_150</td>
<td>–</td>
<td>–</td>
<td>16</td>
<td>m22</td>
<td>TJ =150 ℃ Vs =- 13.5 V /L =- 4A</td>
<td>P_7.5.11.7</td>
</tr>
<tr>
<td>Nominal Load Current</td>
<td>IL(NOM)</td>
<td>–</td>
<td>15</td>
<td>–</td>
<td>A</td>
<td>1) TA = 85 ℃ TJ ≤150℃</td>
<td>P_7.5.11.8</td>
</tr>
<tr>
<td>Output Leakage Current at TJ ≤ 85℃</td>
<td>IL(OF)_85</td>
<td>–</td>
<td>0.05</td>
<td>0.5</td>
<td>µA</td>
<td>1) VOUT = 0 V VIN = "low" TA ≤ 85℃</td>
<td>P_7.5.11.9</td>
</tr>
<tr>
<td>Output Leakage Current at TJ =150 ℃</td>
<td>IL(OFF)_150</td>
<td>–</td>
<td>–</td>
<td>15</td>
<td>µA</td>
<td>VOUT = 0 V VIN = "low" TA = 150 ℃</td>
<td>P_7.5.11.10</td>
</tr>
<tr>
<td>Inverse Current Capability</td>
<td>IL(INV)</td>
<td>–</td>
<td>-15</td>
<td>–</td>
<td>A</td>
<td>1) VS &lt; VOUT IN = "high" see Figure 18</td>
<td>P_7.5.11.11</td>
</tr>
<tr>
<td>Voltage Slope</td>
<td colspan="7"></td>
</tr>
<tr>
<td>Passive Slew Rate (e.g. for Half Bridge Configuration)</td>
<td>IdVOUT / dt]</td>
<td>-</td>
<td>–</td>
<td>10</td>
<td>V/μς</td>
<td>1) Vs = 13.5 V see Figure 20</td>
<td>P_7.5.11.12</td>
</tr>
<tr>
<td colspan="8">Voltages</td>
</tr>
<tr>
<td>Drain Source Diode Voltage</td>
<td>IV DS(DIODE)</td>
<td>–</td>
<td>550</td>
<td>700</td>
<td>mV</td>
<td>/_ =- 190 mA TJ=150 ℃</td>
<td>P_7.5.11.13</td>
</tr>
<tr>
<td colspan="8">Switching Energy</td>
</tr>
<tr>
<td>Switch-ON Energy</td>
<td>EON</td>
<td>–</td>
<td>1.4</td>
<td>–</td>
<td>mJ</td>
<td>1) Vs = 18 V see Figure 15</td>
<td>P_7.5.11.14</td>
</tr>
<tr>
<td>Switch-OFF Energy</td>
<td>E OFF</td>
<td>–</td>
<td>1.65</td>
<td>–</td>
<td>mJ</td>
<td>1) Vs = 18 V see Figure 15</td>
<td>P_7.5.11.15</td>
</tr>
</table>

1\) Not subject to production test - specified by design.

<!-- PageFooter="Data Sheet" -->
<!-- PageNumber="27" -->
<!-- PageFooter="Rev. 1.03 2019-10-15" -->
<!-- PageBreak -->

<!-- PageNumber="Side 28" -->

<!-- PageHeader="BTS7004-1EPP PROFET™+2 12V" -->

<figure>

Infineon

</figure>

<!-- PageHeader="Protection" -->

# 8 Protection

The BTS7004-1EPP is protected against Overtemperature, Overload, Reverse Battery (with ReverseON) and
Overvoltage. Overtemperature and Overload protections are working when the device is in ON or ON_Diag
mode but not during InverseON and ReverseON function. Overvoltage protection works in all operation
modes. Reverse Battery protection works when the GND and VS pins are reverse supplied.

## 8.1 Overtemperature Protection

The device incorporates both an absolute (TJ(ABS) and a dynamic (TJ(DYN) temperature protection circuitry for
the channel. An increase of junction temperature T, above either one of the two thresholds (TJ(ABS) or TJ(DYN))
switches OFF the overheated channel to prevent destruction. The channel remains switched OFF until
junction temperature has reached the "Reactivation" condition described in Table 14. The behavior is shown
in Figure 21 (absolute Overtemperature Protection) and Figure 22 (dynamic Overtemperature Protection).
TJ(REF) is the reference temperature used for dynamic temperature protection.

<figure>
<figcaption>Figure 21 Overtemperature Protection (Absolute)</figcaption>

IN

t

DEN

t

IL

IL(OVL 0)

IL(NOM)

t

TJ

TJ(ABS)

Is

t

Is = IL/KILIS

/IS(FAULT)

t

Internal
latch

0

1

t

Over_Temperature_Behaviour.emf

</figure>

<!-- PageFooter="Data Sheet" -->
<!-- PageNumber="28" -->
<!-- PageFooter="Rev. 1.03 2019-10-15" -->
<!-- PageBreak -->

<!-- PageNumber="Side 29" -->

<!-- PageHeader="BTS7004-1EPP PROFET™+2 12V" -->

<figure>

Infineon

</figure>

### Protection

<figure>
<figcaption>Figure 22 Overtemperature Protection (Dynamic)</figcaption>

IN

t

DEN

t

1

IL(OVL)

t

TJ

T(ABS)

Tx(DYN)

T (REF)

t

Is

LIKILIS

IS(FAULT)

t

Internal
Latch

0

1

t

</figure>

When the Overtemperature protection circuitry allows the channel to be switched ON again, the Intelligent
Latch strategy described in Chapter 8.3 is followed.

## 8.2 Overload Protection

The BTS7004-1EPP is protected in case of Overload or short circuit to ground. Two Overload thresholds are
defined (see Figure 23) and selected automatically depending on the voltage Vos across the power DMOS:

· IL(OVLO) when VDs < 13 V

· IL(OVL1) When VDs > 22 V

<!-- PageFooter="Data Sheet" -->
<!-- PageNumber="29" -->
<!-- PageFooter="Rev. 1.03 2019-10-15" -->
<!-- PageBreak -->

<!-- PageNumber="Side 30" -->

<!-- PageHeader="BTS7004-1EPP PROFET™+2 12V" -->

<figure>

Infineon

</figure>

### Protection

<figure>
<figcaption>Figure 23 Overload Current Thresholds</figcaption>

Overload threshold variation ("1" = IL(OVLo) typ @ VDs =5 V)

1.1

IL(OVLO)

1

0.9

0.8

0.7

0.6

L(OVL1)

0.5

0.4

0.3

0.2

0.1

0

4

6

8

10

12

14

16

18

20

22

24

26

28

Drain Source Voltage (V)

</figure>

In order to allow a higher load inrush at low ambient temperature, Overload threshold is maximum at low
temperature and decreases when Ty increases (see Figure 24). IL(OVLO) typical value remains constant up to a
junction temperature of +75 ℃.

<figure>
<figcaption>Figure 24 Overload Current Thresholds variation with T,</figcaption>

IL(OVLO) Variation over T,

1.3

1.2

1.1

0

IL (OVLO) Variation factor

0.9

0.8

0.7

reference value

"1"= IL(OVLO) typ@-40 ℃

0.6

0.5

0.4

0.3

0.2

0.1

Typ

0.0

-40°℃

-20°℃

0°℃

20°℃

40℃

60℃

80°℃

100°C

120°℃

140℃

160℃

Junction Temperature (℃)

</figure>

<!-- PageFooter="Data Sheet" -->
<!-- PageNumber="30" -->
<!-- PageFooter="Rev. 1.03 2019-10-15" -->
<!-- PageBreak -->

<!-- PageNumber="Side 31" -->

<figure>

Infineon

</figure>

<!-- PageHeader="BTS7004-1EPP PROFET™+2 12V" -->

#### Protection

Power supply voltage Vs can increase above 18 V for short time, for instance in Load Dump or in Jump Start
condition. Whenever Vs > Vs(s), the overload detection current is set to IL(OVL_Js) as shown in Figure 25.

<figure>
<figcaption>Figure 25 Overload Detection Current variation with Vs voltage</figcaption>

/L(OVL)

/L(OVL_JS)

Vs(JS)

Vs

Protection_JS.emf

</figure>

When ILL(OVL) (either / L(OVLO) or /L(OVL1) the channel is switched OFF. The channel is allowed to be reactivated
according to the intelligent latch strategy described in Chapter 8.3.

## 8.3 Protection and Diagnosis in case of Fault

Any event that triggers a protection mechanism (either Overtemperature or Overload) has 2 consequences:

· The channel switches OFF and the internal latch is set to "1"

· If the diagnosis is active for the channel, a current /IS(FAULT) is provided by IS pin (see Chapter 9.2.2 for
further details)

The channel can be switched ON again if all the protection mechanisms fulfill the "reactivation" conditions
described in Table 14. Furthermore, the device has the intelligent latch to protect itself against unwanted
repetitive reactivation in fault condition.

<table>
<caption>Table 14 Protection "Reactivation" Condition</caption>
<tr>
<th>Fault condition</th>
<th>Switch OFF event</th>
<th>"Reactivation" condition</th>
</tr>
<tr>
<td>Overtemperature</td>
<td>TJ ≥ TJ(ABS) Or (TJ - TJ(REF) ≥ TJ(DYN)</td>
<td>TJ &lt;TJ(ABS) and (T) -TJ(REF) &lt;TJ(DYN) (including hysteresis)</td>
</tr>
<tr>
<td>Overload</td>
<td>IL≥ /L(OVL)</td>
<td>Device is OFF</td>
</tr>
</table>

### 8.3.1 Intelligent Latch Strategy

At normal condition, when IN is set to "high", the channel is switched ON. In case of fault condition the output
stage latches OFF. There are two ways to de-latch the switch.

With IN pin:

It is necessary to set the input pin to "low" for a time longer than tDELAY(LR) ("latch reset delay" time) to de-latch
the channel. The channel can be allowed to restart only if the "latch" conditions for the protection
mechanisms are fulfilled (see Table 14 ).

<!-- PageFooter="Data Sheet" -->
<!-- PageNumber="31" -->
<!-- PageFooter="Rev. 1.03 2019-10-15" -->
<!-- PageBreak -->

<!-- PageNumber="Side 32" -->

<!-- PageHeader="BTS7004-1EPP PROFET™+2 12V" -->

<figure>

Infineon

</figure>

#### Protection

During the "latch reset delay" time, if the input is set to "high" the channel remains switched OFF and the timer
tDELAY(LR) is reset. The timer tDELAY(LR) restarts as soon as the input pin is set to "low" again.
The intelligent latch strategy is shown in Figure 28 (flowchart) and Figure 26 (timing diagram).

With DEN pin:

It is possible to "force" a reset of the internal latch without waiting for tDELAY(LR) by applying a pulse (rising edge
followed by a falling edge) to the DEN pin while IN pin is "low". The pulse applied to DEN pin must have a
duration longer than tDEN(LR) to ensure a reset of the internal latch.

The timing is shown in Figure 27.

<figure>
<figcaption>Figure 26 Intelligent Latch Timing Diagram</figcaption>

ÉDELAY (LR)

IN

t

Short circuit
to ground

t

IL

t

Internal
latch

0

1

0

1

t

DEN

t

ts IS(DIAG )

ton

/Is (FAULT)

,

IS (FAULT)

lis

t

Protection_Latch_Timing.emf

</figure>

<!-- PageFooter="Data Sheet" -->
<!-- PageNumber="32" -->
<!-- PageFooter="Rev. 1.03 2019-10-15" -->
<!-- PageBreak -->

<!-- PageNumber="Side 33" -->

<!-- PageHeader="BTS7004-1EPP PROFET™+2 12V" -->

<figure>

Infineon

</figure>

<!-- PageHeader="Protection" -->

<figure>
<figcaption>Figure 27 Intelligent Latch Timing Diagram with Forced Reset</figcaption>

IN

t

Short circuit
to ground

1

t

t

Internal
latch

0

1

0

1

t <İDEN(LR)

t > tDEN(LR)

t

DEN

t

tsIS (DIAG)

ts IS(DIAG )

tsIS(DIAG)

IS (FAULT)

/IS (FAULT )

VIS (FAULT)

lis

t

Protection_Latch_DENforce.emf

</figure>

<!-- PageFooter="Data Sheet" -->
<!-- PageNumber="33" -->
<!-- PageFooter="Rev. 1.03 2019-10-15" -->
<!-- PageBreak -->

<!-- PageNumber="Side 34" -->

<!-- PageHeader="BTS7004-1EPP PROFET™+2 12V" -->

<figure>

Infineon

</figure>

##### Protection

<figure>
<figcaption>Figure 28 Intelligent Latch Flowchart</figcaption>

START

IN is "high"

no

yes

yes

Latch = 1

no

Reactivation
condition fulfilled
(T, and / or AT / and / or
Overload)

no

yes

Latch = 0

Switch channel ON

Yes

DEN pulse > tDEN(LR)

Fault
(Overtemperature
or Overload)

no

no

yes

Switch channel OFF

Wait until
DEN pulse > tDEN(LR)

Latch = 1

Wait until IN is "low"
then start counting for
tDELAY(LR)

Set DEN to „high“

IN is "low"

no

yes

yes

De-latching with
DEN

no

Continue latching for
İDELAY(LR)

İDELAY(LR) elapsed

no

yes

Latch = 0

</figure>

Protection_PROFET_Flow_PDH.emf

<!-- PageFooter="Data Sheet" -->
<!-- PageNumber="34" -->
<!-- PageFooter="Rev. 1.03 2019-10-15" -->
<!-- PageBreak -->

<!-- PageNumber="Side 35" -->

<!-- PageHeader="BTS7004-1EPP PROFET™+2 12V" -->

<figure>

<!-- PageHeader="Infineon" -->

</figure>

<!-- PageHeader="Protection" -->

## 8.4 Additional protections

### 8.4.1 Reverse Polarity Protection

In Reverse Polarity condition (also known as Reverse Battery), the output stage is switched ON (see parameter
RDS(REV)) because of ReverseON feature which limits the power dissipation in the output stage. Each ESD diode
of the logic contributes to total power dissipation. The reverse current through the output stage must be
limited by the connected load. The current through digital input pins has to be limited as well by an external
resistor (please refer to the Absolute Maximum Ratings listed in Chapter 4.1 and to Application Information in
Chapter 10).

Figure 29 shows a typical application including a device with ReverseON. A current flowing into GND pin (-/GND)
during Reverse Polarity condition is necessary to activate ReverseON, therefore a resistive path between
module ground and device GND pin must be present.

<figure>
<figcaption>Figure 29 Reverse Battery Protection (application example)</figcaption>

-VBAT(REV)

High-side
Channel

VS

Microcontroller

IDI

DO

RDI

DI

ReverseON

OUT

-/L

GND

IS

GND

L, C, R

-/Is

RSENSE

RGND

-IGND

Protection_RevBatt_HEAT.emf

</figure>

### 8.4.2 Overvoltage Protection

In the case of supply voltages between VS(EXT,UP) and VBAT(LD), the output transistor is still operational and
follows the input pin. In addition to the output clamp for inductive loads as described in Chapter 7.2.2, there
is a clamp mechanism available for Overvoltage protection for the logic circuit and the output channel,
monitoring the voltage between VS and GND pins (VS(CLAMP).

<!-- PageFooter="Data Sheet" -->
<!-- PageNumber="35" -->
<!-- PageFooter="Rev. 1.03 2019-10-15" -->
<!-- PageBreak -->

<!-- PageNumber="Side 36" -->

<!-- PageHeader="BTS7004-1EPP PROFET™+2 12V" -->

<figure>

Infineon

</figure>

<!-- PageHeader="Protection" -->

## 8.5 Protection against loss of connection

### 8.5.1 Loss of Battery and Loss of Load

The loss of connection to battery or to the load has no influence on device robustness when load and wire
harness are purely resistive. In case of driving an inductive load, the energy stored in the inductance must be
handled. PROFET™+2 12V devices can handle the inductivity of the wire harness up to 10 uH with /L(NOM). In case
of applications where currents and/or the aforementioned inductivity are exceeded, an external suppressor
diode (like diode Dz2 shown in Chapter 10) is recommended to handle the energy and to provide a well-
defined path to the load current.

### 8.5.2 Loss of Ground

In case of loss of device ground, it is recommended to have a resistor connected between any Digital Input pin
and the microcontroller to ensure a channel switch OFF (as described in Chapter 10).

Note:
In case any Digital Input pin is pulled to ground (either by a resistor or active) a parasitic ground
path is available, which could keep the device operational during loss of device ground.

<!-- PageFooter="Data Sheet" -->
<!-- PageNumber="36" -->
<!-- PageFooter="Rev. 1.03 2019-10-15" -->
<!-- PageBreak -->

<!-- PageNumber="Side 37" -->

<figure>

Infineon

</figure>

<!-- PageHeader="BTS7004-1EPP PROFET™+2 12V" -->

# Protection

## 8.6 Electrical Characteristics Protection

Vs = 6 V to 18 V, TJ =- 40 ℃ to +150 ℃

Typical values: Vs = 13.5 V, TJ= 25 ℃

Typical resistive load connected to the output for testing (unless otherwise specified):

RL = 2.12

<table>
<caption>Table 15 Electrical Characteristics: Protection - General</caption>
<tr>
<th rowspan="2">Parameter</th>
<th rowspan="2">Symbol</th>
<th colspan="3">Values</th>
<th rowspan="2">Unit</th>
<th rowspan="2">Note or Test Condition</th>
<th rowspan="2">Number</th>
</tr>
<tr>
<th>Min.</th>
<th>Typ.</th>
<th>Max.</th>
</tr>
<tr>
<td>Thermal Shutdown Temperature (Absolute)</td>
<td>TJ(ABS)</td>
<td>150</td>
<td>175</td>
<td>200</td>
<td>ºC</td>
<td>1)2) See Figure 21</td>
<td>P_8.6.0.1</td>
</tr>
<tr>
<td>Thermal Shutdown Hysteresis (Absolute)</td>
<td>THYS(ABS)</td>
<td>–</td>
<td>30</td>
<td>–</td>
<td>K</td>
<td>3) See Figure 21</td>
<td>P_8.6.0.2</td>
</tr>
<tr>
<td>Thermal Shutdown Temperature (Dynamic)</td>
<td>TJ(DYN)</td>
<td>–</td>
<td>80</td>
<td>–</td>
<td>K</td>
<td>3) See Figure 22</td>
<td>P_8.6.0.3</td>
</tr>
<tr>
<td>Power Supply Clamping Voltage at TJ = - 40 ℃</td>
<td>VS(CLAMP) _- 40</td>
<td>33</td>
<td>36.5</td>
<td>42</td>
<td>V</td>
<td>Ivs = 5 mA TJ =- 40 °℃ See Figure 16</td>
<td>P_8.6.0.6</td>
</tr>
<tr>
<td>Power Supply Clamping Voltage at TJ ≥ 25 ℃</td>
<td>VS(CLAMP)_25</td>
<td>35</td>
<td>38</td>
<td>44</td>
<td>V</td>
<td>2) Ivs = 5 mA TJ ≥ 25°℃ See Figure 16</td>
<td>P_8.6.0.7</td>
</tr>
<tr>
<td>Power Supply Voltage Threshold for Overcurrent Threshold Reduction in case of Short Circuit</td>
<td>VS(JS)</td>
<td>20.5</td>
<td>22.5</td>
<td>24.5</td>
<td>V</td>
<td>3) Setup acc. to AEC- Q100-012</td>
<td>P_8.6.0.8</td>
</tr>
</table>

1\) Functional test only.

2\) Tested at TJ = 150℃ only.

3\) Not subject to production test - specified by design.

### 8.6.1 Electrical Characteristics Protection

<table>
<caption>Table 16 Electrical Characteristics: Protection</caption>
<tr>
<th rowspan="2">Parameter</th>
<th rowspan="2">Symbol</th>
<th colspan="3">Values</th>
<th rowspan="2">Unit</th>
<th rowspan="2">Note or Test Condition</th>
<th rowspan="2">Number</th>
</tr>
<tr>
<th>Min.</th>
<th>Typ.</th>
<th>Max.</th>
</tr>
<tr>
<td>Latch Reset Delay Time after Fault Condition</td>
<td>tDELAY(LR)</td>
<td>40</td>
<td>70</td>
<td>100</td>
<td>ms</td>
<td>1)</td>
<td>P_8.6.4.1</td>
</tr>
<tr>
<td>Minimum DEN Pulse Duration for Latch Reset</td>
<td>İDEN(LR)</td>
<td>50</td>
<td>100</td>
<td>150</td>
<td>us</td>
<td>2)</td>
<td>P_8.6.4.2</td>
</tr>
</table>

1\) Functional test only.

2\) Not subject to production test - specified by design.

<!-- PageFooter="Data Sheet" -->
<!-- PageNumber="37" -->
<!-- PageFooter="Rev. 1.03 2019-10-15" -->
<!-- PageBreak -->

<!-- PageNumber="Side 38" -->

<figure>

Infineon

</figure>

<!-- PageHeader="BTS7004-1EPP PROFET™+2 12V" -->
<!-- PageHeader="Protection" -->

## 8.7 Electrical Characteristics Protection - Power Output Stages

Vs = 6 V to 18 V, TJ =- 40 °C to +150 ℃
Typical values: Vs = 13.5 V, T ]= 25 ℃

Typical resistive load connected to the output for testing (unless otherwise specified):

RL =2.12

### 8.7.1 Protection Power Output Stage - 4 m22

<table>
<caption>Table 17 Electrical Characteristics: Protection - 4 m22</caption>
<tr>
<th rowspan="2">Parameter</th>
<th rowspan="2">Symbol</th>
<th colspan="3">Values</th>
<th rowspan="2">Unit</th>
<th rowspan="2">Note or Test Condition</th>
<th rowspan="2">Number</th>
</tr>
<tr>
<th>Min.</th>
<th>Typ.</th>
<th>Max.</th>
</tr>
<tr>
<td>Overload Detection Current at TJ =- 40 °℃</td>
<td>IL(OVLO) _- 40</td>
<td>107</td>
<td>119.5</td>
<td>132</td>
<td>A</td>
<td>1) TJ =- 40 ℃ d//dt = 0.4 A/us see Figure 23 and Figure 24</td>
<td>P_8.7.11.1</td>
</tr>
<tr>
<td>Overload Detection Current at TJ = 25 ℃</td>
<td>I L(OVL0)_25</td>
<td>103</td>
<td>117.5</td>
<td>132</td>
<td>A</td>
<td>2) TJ = 25 ℃ d//dt = 0.4 A/us see Figure 23 and Figure 24</td>
<td>P_8.7.11.7</td>
</tr>
<tr>
<td>Overload Detection Current at TJ =150 ℃</td>
<td>/L(OVLO)_150</td>
<td>88</td>
<td>101</td>
<td>114</td>
<td>A</td>
<td>2) TJ=150 ℃ d//dt = 0.4 A/us see Figure 23 and Figure 24</td>
<td>P_8.7.11.8</td>
</tr>
<tr>
<td>Overload Detection Current at High VDs</td>
<td>IL(OVL1)</td>
<td>–</td>
<td>72</td>
<td>–</td>
<td>A</td>
<td>2) d//dt = 0.4 A/us see Figure 23</td>
<td>P_8.7.11.5</td>
</tr>
<tr>
<td>Overload Detection Current Jump Start Condition</td>
<td>L(OV_JS)</td>
<td>–</td>
<td>72</td>
<td>–</td>
<td>A</td>
<td>2) V=&gt;VS(JS) d//dt = 0.4 A/us see Figure 25</td>
<td>P_8.7.11.6</td>
</tr>
</table>

1\) Functional test only.

2\) Not subject to production test - specified by design.

<!-- PageFooter="Data Sheet" -->
<!-- PageNumber="38" -->
<!-- PageFooter="Rev. 1.03 2019-10-15" -->
<!-- PageBreak -->

<!-- PageNumber="Side 39" -->

<!-- PageHeader="BTS7004-1EPP PROFET™+2 12V" -->

<figure>

Infineon

</figure>

<!-- PageHeader="Diagnosis" -->

## 9 Diagnosis

For diagnosis purpose, the BTS7004-1EPP provides a sense current signal (/Is) at pin IS. In case of disabled
diagnostic (DEN pin set to "low"), IS pin becomes high impedance.

A sense resistor RSENSE must be connected between IS pin and module ground if the current sense diagnosis is
used. RSENSE Value has to be higher than 820 02 (or 400 02 when a central Reverse Battery protection is present
on the battery feed) to limit the power losses in the sense circuitry. A typical value is RSENSE = 1.2 kQ2.

Due to the internal connection between IS pin and Vs supply voltage, it is not recommended to connect the IS
pin to the sense current output of other devices, if they are supplied by a different battery feed.

See Figure 30 for details as an overview.

<figure>
<figcaption>Figure 30 Diagnosis Block Diagram</figcaption>

VS

Output Channel

T

Overtemperature

Latch

IS Pin Control
Logic

IN

OUT

DEN

KILIS

/IS(FAULT)

\+
VDS(OLOFF)

/IS(OLOFF)

MUX

IS

RSENSE

Diagnosis_HEAT_1CH.emf

</figure>

<!-- PageFooter="Data Sheet" -->
<!-- PageNumber="39" -->
<!-- PageFooter="Rev. 1.03 2019-10-15" -->
<!-- PageBreak -->

<!-- PageNumber="Side 40" -->

<figure>

Infineon

</figure>

<!-- PageHeader="BTS7004-1EPP PROFET™+2 12V" -->
<!-- PageHeader="Diagnosis" -->

### 9.1 Overview

Table 18 gives a quick reference to the state of the IS pin during BTS7004-1EPP operation.

<table>
<caption>Table 18 SENSE Signal, Function of Application Condition</caption>
<tr>
<th>Application Condition</th>
<th>Input level</th>
<th>DEN level</th>
<th>VOUT</th>
<th>Diagnostic Output</th>
</tr>
<tr>
<td>Normal operation</td>
<td rowspan="6">“low"</td>
<td rowspan="14">“high"</td>
<td>~ GND</td>
<td>Z VIS(FAULT) if latch # 0</td>
</tr>
<tr>
<td>Short circuit to GND</td>
<td>~ GND</td>
<td>Z JIS(FAULT) if latch # 0</td>
</tr>
<tr>
<td>Overtemperature</td>
<td>Z</td>
<td>/ IS(FAULT)</td>
</tr>
<tr>
<td>Short circuit to Vs</td>
<td>Vs</td>
<td>/IS(OLOFF) (/IS(FAULT) if latch # 0)</td>
</tr>
<tr>
<td>Open Load</td>
<td>&lt;Vs - VDS(OLOF) &gt; Vs - VDS(OLOF) 1)</td>
<td>Z !IS(OLOFF) (in both cases /IS(FAULT) if latch # 0)</td>
</tr>
<tr>
<td>Inverse current</td>
<td>VOUT &gt; Vs</td>
<td>‘S(OLOF) (/IS(FAULT) if latch # 0)</td>
</tr>
<tr>
<td>Normal operation</td>
<td rowspan="8">“high"</td>
<td>~ Vs</td>
<td>/Is = /L / KILIS</td>
</tr>
<tr>
<td>Overload</td>
<td>&lt; Vs</td>
<td>/ IS(FAULT)</td>
</tr>
<tr>
<td>Short circuit to GND</td>
<td>~ GND</td>
<td>/ IS(FAULT)</td>
</tr>
<tr>
<td>Overtemperature</td>
<td>Z</td>
<td>/ IS(FAULT)</td>
</tr>
<tr>
<td>Short circuit to Vs</td>
<td>VS</td>
<td>IS &lt; /1 / KILIS</td>
</tr>
<tr>
<td>Open Load</td>
<td>~ Vs 2 )</td>
<td>Is = 1 Is(EN)</td>
</tr>
<tr>
<td>Under load (e.g. Output Voltage Limitation condition)</td>
<td>~ VS3)</td>
<td>IS(EN) &lt;115&lt;/L(NOM) / KILIS</td>
</tr>
<tr>
<td>Inverse current</td>
<td>VOUT &gt; Vs</td>
<td>Is = IS (EN)</td>
</tr>
<tr>
<td>All conditions</td>
<td>n.a.</td>
<td>“low"</td>
<td>n.a.</td>
<td>Z</td>
</tr>
</table>

1\) With additional pull-up resistor.

2\) The output current has to be smaller than /L(OL)-

3\) The output current has to be higher than / L(OL)-

### 9.2 Diagnosis in ON state

A current proportional to the load current (ratio kILIs =/L/ /Is) is provided at pin IS when the following conditions
are fulfilled:

· The power output stage is switched ON with VDs < VDS(OLOFF)

· The diagnosis is enabled

. No fault (as described in Chapter 8.3) is present or was present and not cleared yet (see Chapter 9.2.2 for
further details)

If a "hard" failure mode is present or was present and not cleared yet a current /IS(FAULT) is provided at IS pin.

<!-- PageFooter="Data Sheet" -->
<!-- PageNumber="40" -->
<!-- PageFooter="Rev. 1.03 2019-10-15" -->
<!-- PageBreak -->

<!-- PageNumber="Side 41" -->

<!-- PageHeader="BTS7004-1EPP PROFET™+2 12V" -->

<figure>

Infineon

</figure>

<!-- PageHeader="Diagnosis" -->

#### 9.2.1 Current Sense (KILIS)

The accuracy of the sense current depends on temperature and load current. lis increases linearly with IL
output current until it reaches the saturation current /IS(SAT). In case of Open Load at the output stage (/) close
to 0 A), the maximum sense current /IS(EN) (no load, diagnosis enabled) is specified. This condition is shown in
Figure 32. The blue line represents the ideal klus line, while the red lines show the behavior of a typical
product.

An external RC filter between IS pin and microcontroller ADC input pin is recommended to reduce signal ripple
and oscillations (a minimum time constant of 1 us for the RC filter is recommended).

The KILIs factor is specified with limits that take into account effects due to temperature, supply voltage and
manufacturing process. Tighter limits are possible (within a defined current window) with calibration:

· A well-defined and precise current (/L(CAL) is applied at the output during End of Line test at customer side

. The corresponding current at IS pin is measured and the kILIs is calculated (KILIS @ IL(CAL))

. Within the current range going from / L(CAL)_ to / L(CAL)_H the KILIS is equal to KILIS @ L(CAL) with limits defined by
AKILIS

The derating of kILIs after calibration is calculated using the formulas in Figure 31 and it is specified by AKILIS

<figure>

AKILIS, MAX = 100 · MAX

KILIS@IL(CAL)_L

1,
KILIS@IL(CAL)_H
KILIS@IL(CAL)

KILIS@IL(CAL)

1

AK ILIS, MIN = 100 · MIN

KILIS@IL(CAL)_L
KILIS@IL(CAL)

KILIS@IL(CAL)_H
1

1,

KILIS@IL(CAL)

Diagnosik_CHILIS ant

</figure>

Figure 31 AKILIs calculation formulas

The calibration is intended to be performed at TA(CAL) = 25℃. The parameter AKILIs includes the drift
overtemperature as well as the drift over the current range from /L(CAL)_ to /L(CAL)_H.

<figure>
<figcaption>Figure 32 Current Sense Ratio in Open Load at ON condition</figcaption>

/Is

/IS(OL)

IS(EN)

L(OL)

IL

Diagnosis_OLON_adv.emf

</figure>

#### 9.2.2 Fault Current (/IS(FAULT))

As soon as a protection event occurs, the value of the internal latch (see Chapter 8.3 for more details) is
changed from 0 to 1, a current /IS(FAULT) is provided by pin IS when DEN is set to "high" and the affected device
is switched OFF.

<!-- PageFooter="Data Sheet" -->
<!-- PageNumber="41" -->
<!-- PageFooter="Rev. 1.03 2019-10-15" -->
<!-- PageBreak -->

<!-- PageNumber="Side 42" -->

<!-- PageHeader="BTS7004-1EPP PROFET™+2 12V" -->

<figure>

Infineon

</figure>

##### Diagnosis

If internal latch is 1, and it is not reset, the current /IS(FAULT) is provided each time the device diagnosis is
activated by DEN=High.

Figure 33 shows the relation between /Is = IL / KILIS, 'IS(SAT) and /IS(FAULT).

<figure>
<figcaption>Figure 33 SENSE behavior - overview</figcaption>

lis

/IS (SAT).max

VIS (SAT)

/IS (FAULT).max

VIS (FAULT)

VIS (SAT).min
/IS(FAULT).min

ILI KLIS

İL(OVL).min

İL(OVL).max

IL

Diagnosis_HEAT_IISFAULT_IISSAT.emf

</figure>

### 9.3 Diagnosis in OFF state

When a power output stage is in OFF state, the BTS7004-1EPP can measure the drain-source voltage and
compare it with a threshold voltage. In this way, using some additional external components (a pull-down
resistor and a switchable pull-up current source), it is possible to detect if the load is missing or if there is a
short circuit to battery. If a Fault condition was detected by the device (if internal latch is 1, fault current is
provided by IS pin independent of drain-source or output voltage, as long as DEN=High) a current /Is(FAULT) iS
provided by IS pin each time the channel diagnosis is checked also in OFF state. See Chapter 9.2.2 for further
details.

#### 9.3.1 Open Load current (/Is(OLOFF))

In OFF state, when DEN pin is set to "high", the Vps voltage is compared with a threshold voltage VDS(OLOFF). If
the load is properly connected and there is no short circuit to battery, VDs ~ Vs therefore VDs > VDS(OLOFF). When
the diagnosis is active and VDs ≤ VDS(OLOFF), a current /IS(OLOFF) is provided by IS pin. Figure 34 shows the
relationship between /IS(OLOFF) and /IS(FAULT) as functions of Vps. The two currents do not overlap making it always
possible to differentiate between Open Load in OFF and Fault condition.

<!-- PageFooter="Data Sheet" -->
<!-- PageNumber="42" -->
<!-- PageFooter="Rev. 1.03 2019-10-15" -->
<!-- PageBreak -->

<!-- PageNumber="Side 43" -->

<!-- PageHeader="BTS7004-1EPP PROFET™+2 12V" -->

<figure>

Infineon

</figure>

<!-- PageHeader="Diagnosis" -->

<figure>
<figcaption>Figure 34 lIs in OFF State</figcaption>

his

/IS(FAUL T)

/IS(OLOFF)

VDS(OLOFF)

VDS

Diagnosis_PROFET_IISOL OFF.emf

</figure>

It is necessary to wait a time tIS(OLOFF)_D between the falling edge of the input pin and the sensing at pin IS for
Open Load in OFF diagnosis to allow the internal comparator to settle. In Figure 35 the timings for an Open
Load detection are shown - the load is always disconnected.

<figure>
<figcaption>Figure 35 Open Load in OFF Timings - load disconnected</figcaption>

IN

t

DEN

ts(OLOFF)_D

t

VOUT

~ Vs

VDS(OLOFF)

Load
connect ed

t

/Is

/IS(OLOFF)

/ S(OL)

t

Diagnosis_PROFET_OLOFF_time.emf

</figure>

<!-- PageFooter="Data Sheet" -->
<!-- PageNumber="43" -->
<!-- PageFooter="Rev. 1.03 2019-10-15" -->
<!-- PageBreak -->

<!-- PageNumber="Side 44" -->

<!-- PageHeader="BTS7004-1EPP PROFET™+2 12V" -->

<figure>

Infineon

</figure>

<!-- PageHeader="Diagnosis" -->

## 9.4 SENSE Timings

Figure 36 shows the timing during settling tsIS(ON) and disabling tsIS(OFF) of the SENSE (including the case of load
change). As a proper signal cannot be established before the load current is stable (therefore before tON),
tsIS(DIAG) ≤3x(tON_max +tsIS(ON)_max).

<figure>
<figcaption>Figure 36 SENSE Settling / Disabling Timing</figcaption>

IN

OFF

ON

OFF

t

DEN

t

IL

tsIS (LC)

tsIS (OFF)

tsIS (ON)

tsIS (OFF)

t

lIs

tsIS (DIAG)

Diagnose_PROFET_SENSE_timings_Heat.emf

t

</figure>

<!-- PageFooter="Data Sheet" -->
<!-- PageNumber="44" -->
<!-- PageFooter="Rev. 1.03 2019-10-15" -->
<!-- PageBreak -->

<!-- PageNumber="Side 45" -->

<figure>

Infineon

</figure>

<!-- PageHeader="BTS7004-1EPP PROFET™+2 12V" -->

Diagnosis

## 9.5 Electrical Characteristics Diagnosis

Vs = 6 V to 18 V, TJ =- 40 °C to +150 ℃
Typical values: Vs = 13.5 V, T ]= 25 ℃

Typical resistive load connected to the output for testing (unless otherwise specified):

RL = 2.12

<table>
<caption>Table 19 Electrical Characteristics: Diagnosis - General</caption>
<tr>
<th rowspan="2">Parameter</th>
<th rowspan="2">Symbol</th>
<th colspan="3">Values</th>
<th rowspan="2">Unit</th>
<th rowspan="2">Note or Test Condition</th>
<th rowspan="2">Number</th>
</tr>
<tr>
<th>Min.</th>
<th>Typ.</th>
<th>Max.</th>
</tr>
<tr>
<td>SENSE Saturation Current</td>
<td>/ IS(SAT)</td>
<td>4.4</td>
<td>–</td>
<td>15</td>
<td>mA</td>
<td>1) VSIS = Vs - VIS≥ 2 V See Figure 33</td>
<td>P_9.6.0.1</td>
</tr>
<tr>
<td>SENSE Leakage Current when Disabled</td>
<td>/IS(OFF)</td>
<td>–</td>
<td>0.01</td>
<td>0.5</td>
<td>µA</td>
<td>DEN = "low" VIS = 0 V</td>
<td>P_9.6.0.2</td>
</tr>
<tr>
<td>SENSE Leakage Current when Enabled at TJ ≤ 85 ℃</td>
<td>/IS(EN)_85</td>
<td>–</td>
<td>0.2</td>
<td>1</td>
<td>µA</td>
<td>1) TJ ≤85°℃ DEN = "high" 1=0A See Figure 32</td>
<td>P_9.6.0.3</td>
</tr>
<tr>
<td>SENSE Leakage Current when Enabled at TJ = 150 ℃</td>
<td>/IS(EN)_150</td>
<td>–</td>
<td>0.2</td>
<td>1</td>
<td>HA</td>
<td>TJ=150 ℃ DEN = "high" IL = 0 A See Figure 32</td>
<td>P_9.6.0.4</td>
</tr>
<tr>
<td>SENSE Operative Range for KILIS Operation (Vs - VIs)</td>
<td>VSIS_k</td>
<td>–</td>
<td>0.5</td>
<td>1</td>
<td>V</td>
<td>1) Vs =6V IN = DEN = "high" IL ≤2* /L(NOM)</td>
<td>P_9.6.0.6</td>
</tr>
<tr>
<td>SENSE Operative Range for Open Load at OFF Diagnosis (Vs - VIS)</td>
<td>VSIS_OL</td>
<td>–</td>
<td>0.5</td>
<td>1</td>
<td>V</td>
<td>1) Vs =6V IN = "low" DEN = "high"</td>
<td>P_9.6.0.7</td>
</tr>
<tr>
<td>SENSE Operative Range for Fault Diagnosis (Vs - VIs)</td>
<td>VSIS_F</td>
<td>–</td>
<td>0.5</td>
<td>1</td>
<td>V</td>
<td>1) Vs = 6V IN = "low" DEN = "high" latch ± 0</td>
<td>P_9.6.0.8</td>
</tr>
<tr>
<td>Power Supply to IS Pin Clamping Voltage at TJ =- 40 ℃</td>
<td>SIS(CLAMP) _- 40</td>
<td>33</td>
<td>36.5</td>
<td>42</td>
<td>V</td>
<td>lis = 1 mA TJ =- 40 ℃ See Figure 16</td>
<td>P_9.6.0.9</td>
</tr>
<tr>
<td>Power Supply to IS Pin Clamping Voltage at TJ ≥ 25℃</td>
<td>SIS(CLAMP)_25</td>
<td>35</td>
<td>38</td>
<td>44</td>
<td>V</td>
<td>2) lis = 1 mA TJ ≥25℃ See Figure 16</td>
<td>P_9.6.0.10</td>
</tr>
</table>

1\) Not subject to production test - specified by design.

2\) Tested at TJ = 150°C.

<!-- PageFooter="Data Sheet" -->
<!-- PageNumber="45" -->
<!-- PageFooter="Rev. 1.03 2019-10-15" -->
<!-- PageBreak -->

<!-- PageNumber="Side 46" -->

<figure>

Infineon

</figure>

<!-- PageHeader="BTS7004-1EPP PROFET™+2 12V" -->

Diagnosis

### 9.5.1 Electrical Characteristics Diagnosis

<table>
<caption>Table 20 Electrical Characteristics: Diagnosis</caption>
<tr>
<th rowspan="2">Parameter</th>
<th rowspan="2">Symbol</th>
<th colspan="3">Values</th>
<th rowspan="2">Unit</th>
<th rowspan="2">Note or Test Condition</th>
<th rowspan="2">Number</th>
</tr>
<tr>
<th>Min.</th>
<th>Typ.</th>
<th>Max.</th>
</tr>
<tr>
<td>SENSE Fault Current</td>
<td>/IS(FAULT)</td>
<td>4.4</td>
<td>5.5</td>
<td>10</td>
<td>mA</td>
<td>–</td>
<td>P_9.6.4.1</td>
</tr>
<tr>
<td>SENSE Open Load in OFF Current</td>
<td>"IS(OLOFF)</td>
<td>1.8</td>
<td>2.5</td>
<td>3.5</td>
<td>mA</td>
<td>–</td>
<td>P_9.6.4.2</td>
</tr>
<tr>
<td>SENSE Open Load in OFF Delay Time</td>
<td>tIS(OLOFF)_D</td>
<td>70</td>
<td>185</td>
<td>300</td>
<td>μς</td>
<td>VDS &lt; VOL(OF) from IN falling edge to VIS = RSENSE * 0.9 * /IS(OLOFF), MIN DEN = "high"</td>
<td>P_9.6.4.4</td>
</tr>
<tr>
<td>Open Load Vps Detection Threshold in OFF State</td>
<td>VDS(OLOFF)</td>
<td>1.3</td>
<td>1.8</td>
<td>2.3</td>
<td>V</td>
<td>–</td>
<td>P_9.6.4.5</td>
</tr>
<tr>
<td>SENSE Settling Time with Nominal Load Current Stable</td>
<td>İşIS(ON)</td>
<td>–</td>
<td>5</td>
<td>40</td>
<td>μς</td>
<td>IL=IL(NOM) DEN from "low" to “high"</td>
<td>P_9.6.4.6</td>
</tr>
<tr>
<td>SENSE Disable Time</td>
<td>İşIS(OFF)</td>
<td>–</td>
<td>5</td>
<td>20</td>
<td>μς</td>
<td>1) From DEN falling edge to lis = /IS(OFF) See Figure 36</td>
<td>P_9.6.4.8</td>
</tr>
<tr>
<td>SENSE Settling Time after Load Change</td>
<td>tsIS(LC)</td>
<td>–</td>
<td>5</td>
<td>20</td>
<td>μς</td>
<td>1) from /L = IL18 to I L = I L19 See Figure 36</td>
<td>P_9.6.4.9</td>
</tr>
</table>

1\) Not subject to production test - specified by design.

<!-- PageFooter="Data Sheet" -->
<!-- PageNumber="46" -->
<!-- PageFooter="Rev. 1.03 2019-10-15" -->
<!-- PageBreak -->

<!-- PageNumber="Side 47" -->

<figure>

Infineon

</figure>

<!-- PageHeader="BTS7004-1EPP PROFET™+2 12V" -->

Diagnosis

## 9.6 Electrical Characteristics Diagnosis - Power Output Stages

Vs = 6 V to 18 V, TJ =- 40 °C to +150 ℃
Typical values: Vs = 13.5 V, T ] = 25 ℃

Typical resistive load connected to the output for testing (unless otherwise specified):
RL = 2.12

### 9.6.1 Diagnosis Power Output Stage - 4 m22

<table>
<caption>Table 21 Electrical Characteristics: Diagnosis - 4 m22</caption>
<tr>
<th rowspan="2">Parameter</th>
<th rowspan="2">Symbol</th>
<th colspan="3">Values</th>
<th rowspan="2">Unit</th>
<th rowspan="2">Note or Test Condition</th>
<th rowspan="2">Number</th>
</tr>
<tr>
<th>Min.</th>
<th>Typ.</th>
<th>Max.</th>
</tr>
<tr>
<td>Open Load Output Current at /Is = 4 uA</td>
<td>/L(OL)_4u</td>
<td>60</td>
<td>90</td>
<td>120</td>
<td>mA</td>
<td>"Is = /Is(OL) = 4 µA see Figure 32</td>
<td>P_9.7.11.1</td>
</tr>
<tr>
<td>Current Sense Ratio at IL=/L04</td>
<td>KILIS04</td>
<td>-65%</td>
<td>20000</td>
<td>+65%</td>
<td></td>
<td>/L04 = 50 mA</td>
<td>P_9.7.11.8</td>
</tr>
<tr>
<td>Current Sense Ratio at 1L=/L07</td>
<td>KILIS07</td>
<td>-65%</td>
<td>20000</td>
<td>+65%</td>
<td></td>
<td>/L07 = 200 mA</td>
<td>P_9.7.11.11</td>
</tr>
<tr>
<td>Current Sense Ratio at 1L=1109</td>
<td>KILIS09</td>
<td>-55%</td>
<td>20000</td>
<td>+55%</td>
<td></td>
<td>/L09 = 450 mA</td>
<td>P_9.7.11.13</td>
</tr>
<tr>
<td>Current Sense Ratio at /L=1113</td>
<td>KILIS13</td>
<td>-40%</td>
<td>20000</td>
<td>+40%</td>
<td></td>
<td>/113 = 2 A</td>
<td>P_9.7.11.17</td>
</tr>
<tr>
<td>Current Sense Ratio at IL = IL16</td>
<td>KILIS16</td>
<td>-24%</td>
<td>20000</td>
<td>+24%</td>
<td></td>
<td>/L16 = 5.5 A</td>
<td>P_9.7.11.20</td>
</tr>
<tr>
<td>Current Sense Ratio at IL = IL18</td>
<td>KILIS18</td>
<td>-8%</td>
<td>20000</td>
<td>+8%</td>
<td></td>
<td>IL18 = 10 A</td>
<td>P_9.7.11.22</td>
</tr>
<tr>
<td>Current Sense Ratio at 1L=1119</td>
<td>KILIS19</td>
<td>-8%</td>
<td>20000</td>
<td>+8%</td>
<td></td>
<td>1) /119 = 15 A</td>
<td>P_9.7.11.23</td>
</tr>
<tr>
<td>SENSE Current Derating with Low Current Calibration</td>
<td>AKILIS (OL)</td>
<td>-30</td>
<td>0</td>
<td>+30</td>
<td>%</td>
<td>1) IL(CAL) = /107 IL(CAL)_H = /L09 /L(CAL)_L = /L04 TA(CAL) = 25 ℃</td>
<td>P_9.7.11.27</td>
</tr>
<tr>
<td>SENSE Current Derating with Nominal Current Calibration</td>
<td>AKILIS(NOM)</td>
<td>-4</td>
<td>0</td>
<td>+4</td>
<td>%</td>
<td>1) IL(CAL) = /L18 IL(CAL)_H = /L19 IL(CAL)_L = /L16 TA(CAL) = 25 ℃</td>
<td>P_9.7.11.29</td>
</tr>
</table>

1\) Not subject to production test - specified by design.

<!-- PageFooter="Data Sheet" -->
<!-- PageNumber="47" -->
<!-- PageFooter="Rev. 1.03 2019-10-15" -->
<!-- PageBreak -->

<!-- PageNumber="Side 48" -->

<!-- PageHeader="BTS7004-1EPP PROFET™+2 12V" -->

<figure>

Infineon

</figure>

# Application Information

## 10 Application Information

Note:
The following information is given as a hint for the implementation of the device only and shall not
be regarded as a description or warranty of a certain functionality, condition or quality of the device.

## 10.1 Application setup

<figure>
<figcaption>Figure 37 BTS7004-1EPP Application Diagram</figcaption>

VBAT

ZWIRE

Optional

[Optional

Cvs

CVSGND

T1

Logic Supply

RGND

VDD

GND

VS

GPIO

RIN

IN

ROL

GPIO

RDEN

DEN

OUT

PROFET™+2
12V

RPD

COUT0

ZWIRE

Dz2

Cvs2

Microcontroller

ADC

RADC

RIS PROT

IS

VSS

CSENSE

Dz1

RSENSE

ZLOAD*

Logic GND

Power GND

Optional

Chassis GND

*See Chapter 1 „Potential Applications“

App_ICH_INTDE)_CVG.Jernf

</figure>

Note:
This is a very simplified example of an application circuit. The function must be verified in the real
application.

<!-- PageFooter="Data Sheet" -->
<!-- PageNumber="48" -->
<!-- PageFooter="Rev. 1.03 2019-10-15" -->
<!-- PageBreak -->

<!-- PageNumber="Side 49" -->

<figure>

Infineon

</figure>

<!-- PageHeader="BTS7004-1EPP PROFET™+2 12V" -->

# Application Information

## 10.2 External Components

<table>
<caption>Table 22 Suggested Component values</caption>
<tr>
<th>Reference</th>
<th>Value</th>
<th>Purpose</th>
</tr>
<tr>
<td>RIN</td>
<td>4.7 kQ</td>
<td>Protection of the microcontroller during Overvoltage and Reverse Polarity Necessary to switch OFF BTS7004-1EPP output during Loss of Ground</td>
</tr>
<tr>
<td>RDEN</td>
<td>4.7 k22</td>
<td>Protection of the microcontroller during Overvoltage and Reverse Polarity Necessary to switch OFF BTS7004-1EPP output during Loss of Ground</td>
</tr>
<tr>
<td>RPD</td>
<td>47 kQ</td>
<td>Output polarization (pull-down) Ensures polarization of BTS7004-1EPP outputs to distinguish between Open Load and Short to Vs in OFF Diagnosis</td>
</tr>
<tr>
<td>ROL</td>
<td>1.5 kQ</td>
<td>Output polarization (pull-up) Ensures polarization of BTS7004-1EPP output during Open Load in OFF diagnosis</td>
</tr>
<tr>
<td>COUT</td>
<td>10 nF</td>
<td>Protection of BTS7004-1EPP output during ESD events and BCI</td>
</tr>
<tr>
<td>T1</td>
<td>BC 807</td>
<td>Switch the battery voltage for Open Load in OFF diagnosis</td>
</tr>
<tr>
<td>Cvs</td>
<td>100 nF</td>
<td>Filtering of voltage spikes on the battery line</td>
</tr>
<tr>
<td>CVSGND</td>
<td>47 nF</td>
<td>Buffer capacitor for fast transient See Table 5 (P_4.3.0.7) for the boundary conditions A placeholder on PCB layout is recommended</td>
</tr>
<tr>
<td>DZ2</td>
<td>33 V TVS Diode</td>
<td>Transient Voltage Suppressor diode Protection during Overvoltage and in case of Loss of Battery while driving an inductive load</td>
</tr>
<tr>
<td>Cvs2</td>
<td>–</td>
<td>Filtering / buffer capacitor located at VBAT connector</td>
</tr>
<tr>
<td>RSENSE</td>
<td>1.2 kQ</td>
<td>SENSE resistor</td>
</tr>
<tr>
<td>RIS_PROT</td>
<td>4.7 kQ2</td>
<td>Protection during Overvoltage, Reverse Polarity, Loss of Ground Value to be tuned according to microcontroller specifications</td>
</tr>
<tr>
<td>DZ1</td>
<td>7 V Z-Diode</td>
<td>Protection of microcontroller during Overvoltage</td>
</tr>
<tr>
<td>RADC</td>
<td>4.7 kQ2</td>
<td>Protection of microcontroller ADC input during Overvoltage, Reverse Polarity, Loss of Ground Value to be tuned according to microcontroller specifications</td>
</tr>
<tr>
<td>CSENSE</td>
<td>220 pF</td>
<td>Sense signal filtering A time constant (RADC + RIS_PROT) * CSENSE longer than 1 us is recommended</td>
</tr>
<tr>
<td>RGND</td>
<td>47 Ω</td>
<td>Protection in case of Overvoltage and Loss of Battery while driving inductive loads</td>
</tr>
</table>

## 10.3 Further Application Information

· Please contact us for information regarding the Pin FMEA

. For further information you may contact http://www.infineon.com/

<!-- PageFooter="Data Sheet" -->
<!-- PageNumber="49" -->
<!-- PageFooter="Rev. 1.03 2019-10-15" -->
<!-- PageBreak -->

<!-- PageNumber="Side 50" -->

<!-- PageHeader="BTS7004-1EPP PROFET™+2 12V" -->

<figure>

<!-- PageHeader="Infineon" -->

</figure>

# Package Outlines
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

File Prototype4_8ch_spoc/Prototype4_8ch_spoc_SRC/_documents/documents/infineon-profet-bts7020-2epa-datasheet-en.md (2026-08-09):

<!-- PageNumber="Side 1" -->

<figure>

infineon

</figure>

BTS7020-2EPA

PROFET™+2 12V
Smart High-Side Power Switch

<figure>

O
Qualified

AEC

·

Y

RoHS

</figure>

2x 20 ml2

<table>
<tr>
<td>Package</td>
<td>PG-TSDSO-14</td>
</tr>
<tr>
<td>Marking</td>
<td>7020-2A</td>
</tr>
</table>

# 1 Overview

## Potential Applications

· Suitable for resistive, inductive and capacitive loads

· Replaces electromechanical relays, fuses and discrete circuits

· Driving capability suitable for 5 A loads and high inrush current loads such
as 2 x P27W + R5W lamps or equivalent electronic loads (e.g. LED modules)

<figure>

JA
Infineon
TSDSO-14

</figure>
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

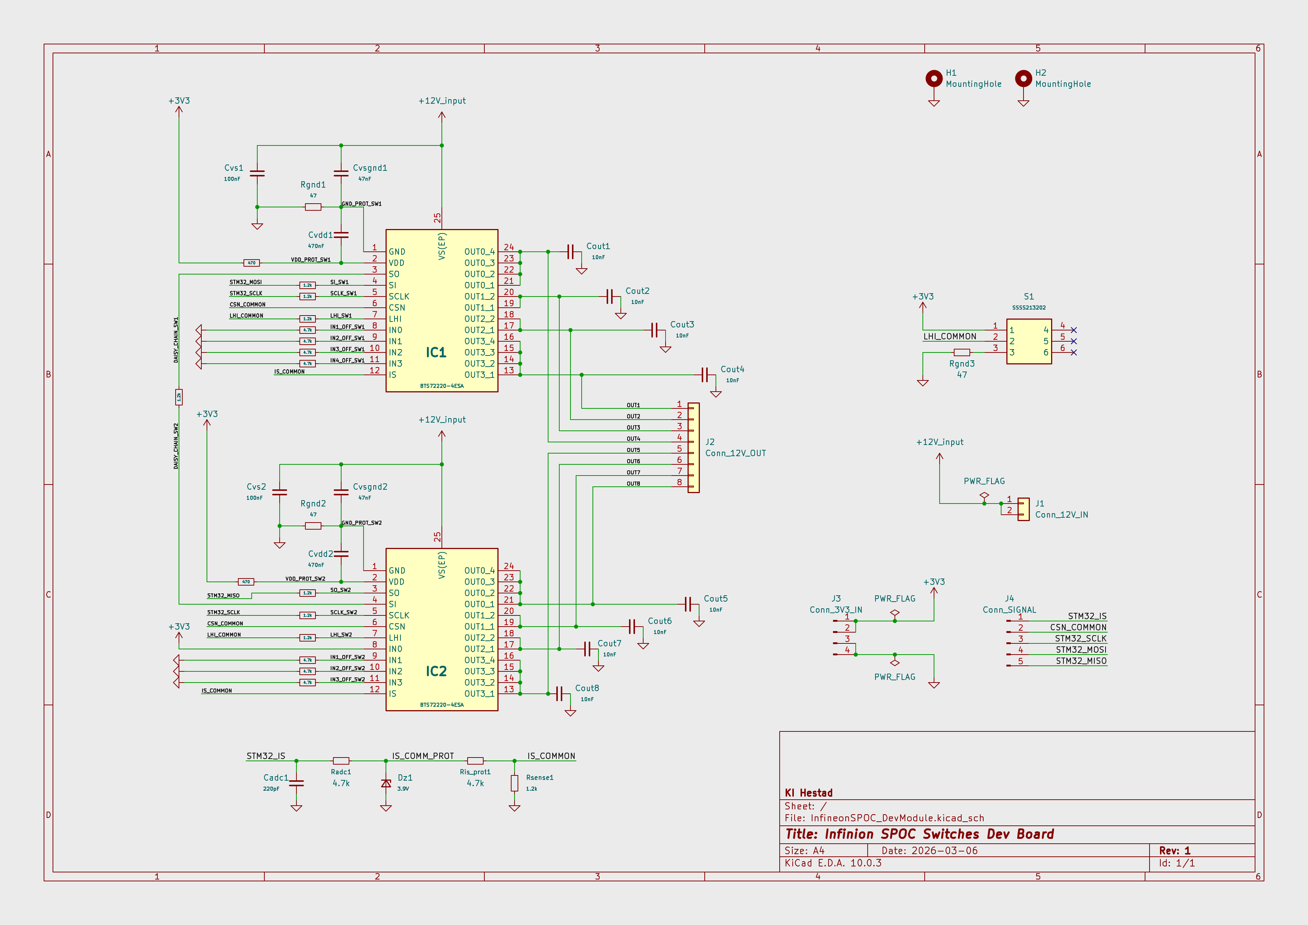
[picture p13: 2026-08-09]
Prototype4_8ch_spoc/Prototype4_8ch_spoc_SRC/_documents/documents/infineon-spoc-bts72220-4esa-2x-pcb-devmodule-schematics.png

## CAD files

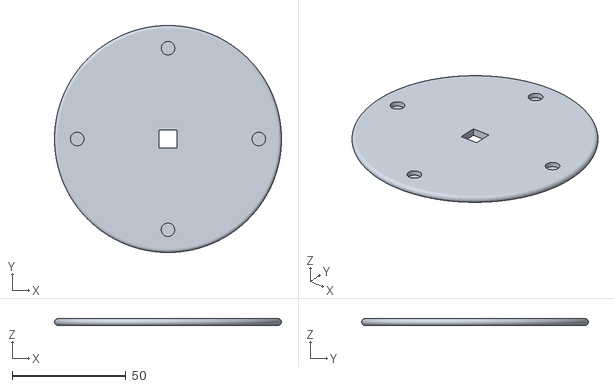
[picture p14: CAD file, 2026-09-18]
MC Wheel Simulator/CAD/rotor.stl
100.0 x 100.0 x 3.00

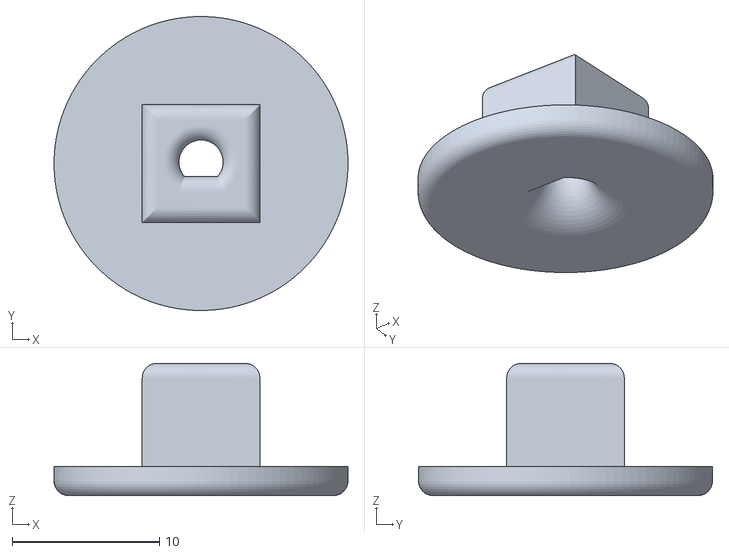
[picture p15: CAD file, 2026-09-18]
MC Wheel Simulator/CAD/rotor_shaft_adapter.stl
20.0 x 20.0 x 9.00

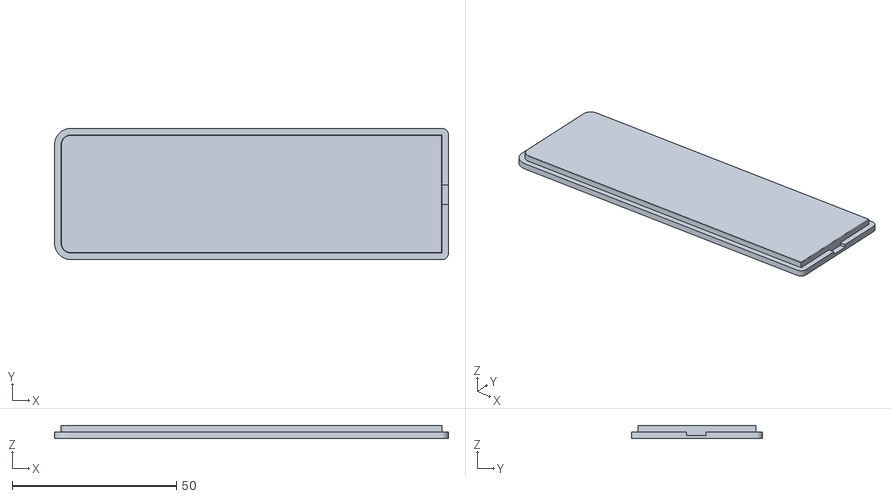
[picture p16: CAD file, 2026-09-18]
MC Wheel Simulator/CAD/rotor_base_cover.stl
120.0 x 40.0 x 4.00

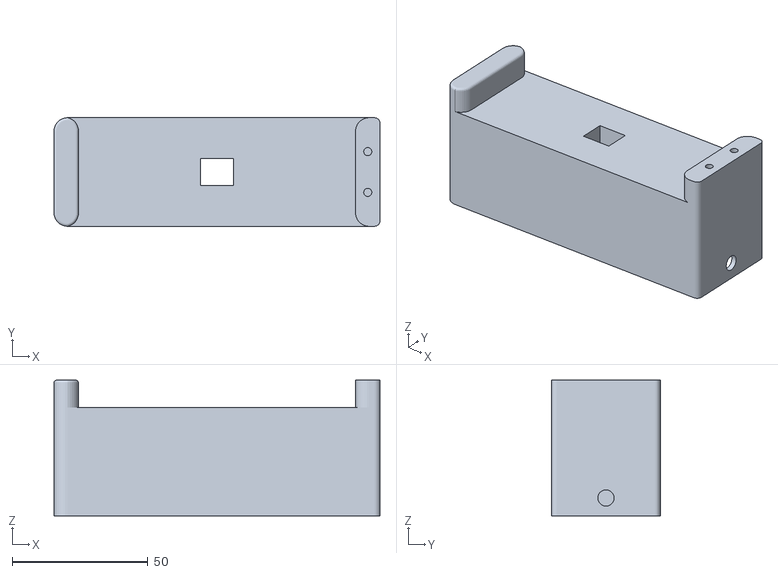
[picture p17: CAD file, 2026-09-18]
MC Wheel Simulator/CAD/rotor_base.stl
120.0 x 40.0 x 50.0

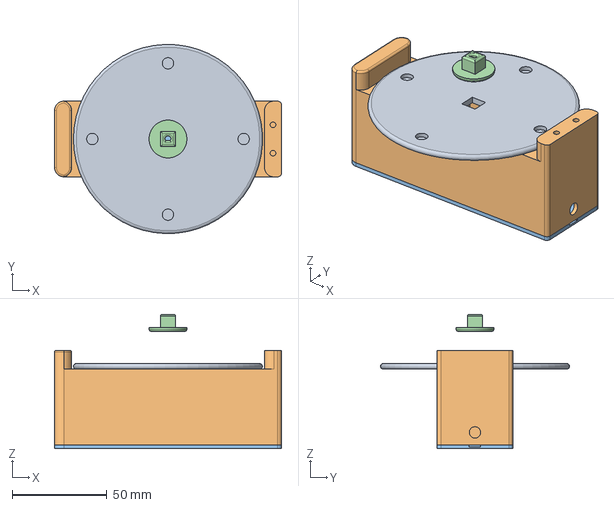
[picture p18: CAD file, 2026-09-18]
MC Wheel Simulator/CAD/wheel_simulator.step
120.0 x 100.0 x 71.0 mm

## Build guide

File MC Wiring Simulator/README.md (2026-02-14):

Ctrl MC logo

# Motorcycle Wiring Simulator

The Motorcycle Wiring Simulator is a PCB to be used for developing and testing motorcycle wiring solutions. The schematics and PCB layout can be found in the zipped file in this folder. It's an achived KiCad project (version 9.0.5).

Version 1.0 is shown in the video referenced below. The included file is however version 1.1 and it has some minor improvements:

* The resistors to limit the voltage for the LEDs are changed according to version 1.0. The new resisrors reduces and balances the brightness.
* The buzzer is changed to a 12V type instaed of a 5V type with 680 ohm resistor to limit the voltage. The buzzer is also included in the parts list for ordering from JLCPCB.
* The pin headers are moved to the edge of the PCB and the lables are moved to the other side of the pin headers to make it easier to read the labels when working with the module.
* The KiCad project includes part numbers for fabrication and assembly from JLCPCB. Pin headers are marked as excluded so they will by default not be added into the BOM- and placement file. Add part numbers and include them to BOM and placement file if you want JLCPCB to mount them for you.

Be aware that version 1.1 is not tested, if ordering a PCB based on this project remember to check it first.

Check the YouTube video "I Turned a Motorcycle Into a Circuit Board" for more info and for a demo of version 1.0:

* https://youtu.be/JKvbBq6Y1_M?si=p860frQD5cO-tTMq

Version 1.1 looks like this:
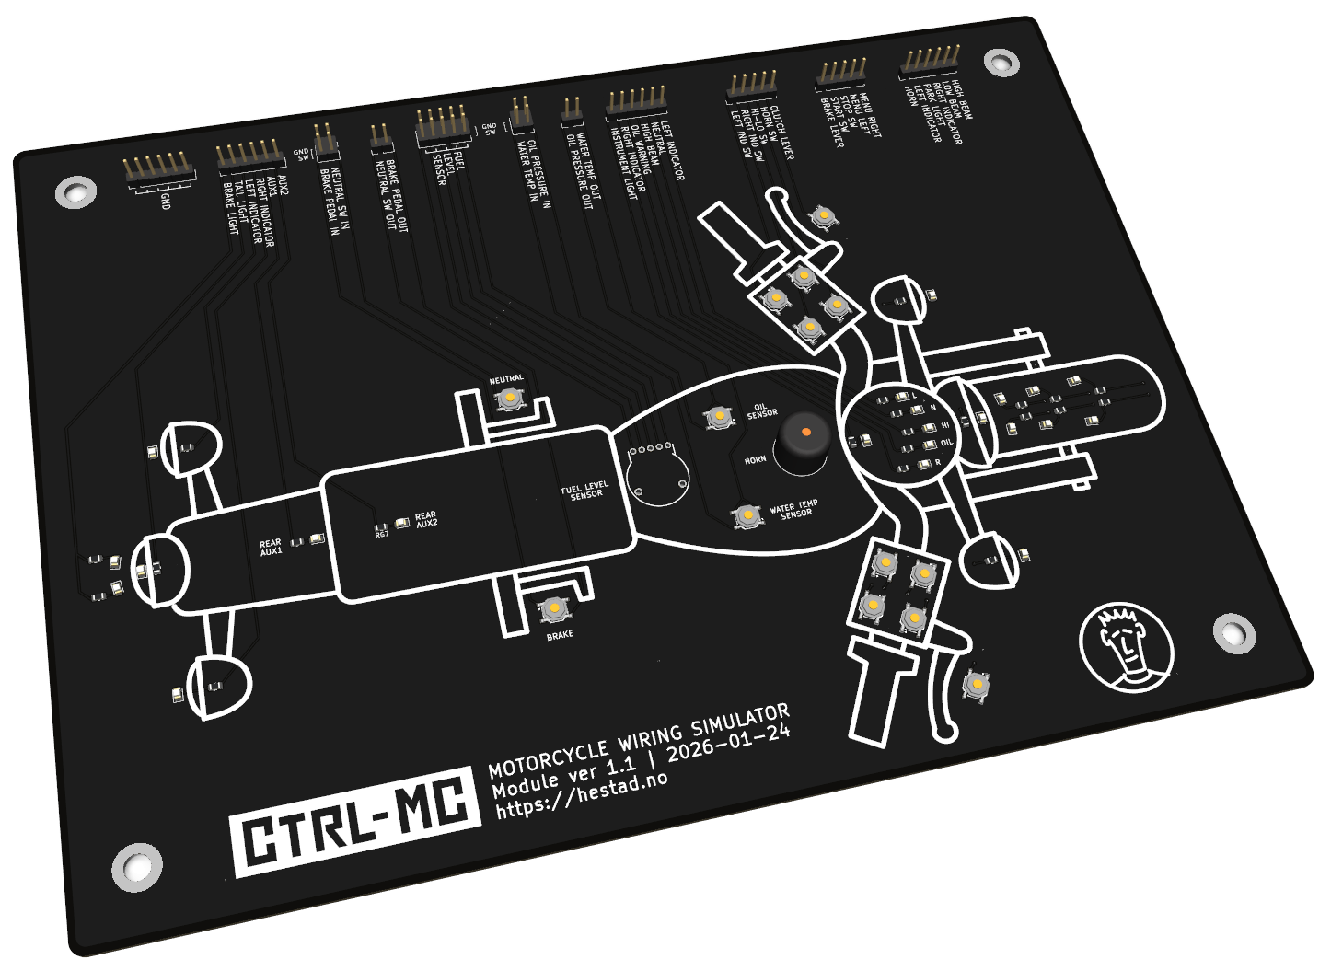
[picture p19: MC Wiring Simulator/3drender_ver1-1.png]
MC Wiring Simulator


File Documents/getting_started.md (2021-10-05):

# Ctrl-MC // Getting Started

_document is currently in progress_

Just writing down stuff that might be useful as the project moves forward.

## Electronics

Supported Arduino boards and other HW recommadations are not yet decided upon. HW used during initial dev stages are:

* Relay Unit:
  * Arduino board: Arduino Nano (ATmega328PB)
  * Relay module: 8 channel + 2 channel (12V) controlled by digital pins from the Arduino
    * Mosfet switches instead of relay module might have been better, but not found any suitable board yet
  
* Handlebar Unit:
  * NodeMCU / espressif8266: Curretly used but has not enough pins, considering EPS32 / STM32
  * Display: 0.96" I2C IIC SPI Serial 128X64 OLED LCD LED Display Module for Arduino or other 128x64 displays
    * 1.8" Color OLED displays looks interesting

* Power Supply / DC-DC stepdown 12V -> 5V
  * Motorcycles has normally 12V battery, ned reliable DC-DC step down
    * if lead acid battery on bike: voltage can vary depending on charge from 0-15V
    * if lithium battery: voltage can vary depending on charge from 9-13V
  * Need to figure out if possible to have one common power supply unit with long cabels, or if best having 2 separate close to unit
  * Product suggestion:
    * [DC-DC Auto Converter 2A 18W Full Range Regulator Step-up Step-down Power Module](https://www.ebay.com/itm/353687714361)

## Enclosure / Housing

Create 3D models in Fusion 360 for 3D printing

## Handlebar Control Switches

Handlebar control swithes will be made using water proof buttons and 3D printed case
* [Waterproof Momentary ON-OFF Push Button Round SPST Switch](https://www.ebay.com/itm/401560101338)

Here some options for prebuilt handlebar control swithes:
* [Motorcycle 3-Button 1" Handlebar Control Momentary Switch](https://www.ebay.com/itm/284179253202)
* [motogadget mo.switch basic](https://www.motogadget.com/shop/en/mo-switch-basic.html)

## Assembly

_todo_

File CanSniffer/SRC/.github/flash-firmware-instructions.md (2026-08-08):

Use STM32 Cube Programmer to flash the firmware to the STM32G431xx MCU.
Use STLink V2
Goto OB + User Settings + Uncheck nSWBOOT0 + Check nBOOT0
Apply
Now flash new SW

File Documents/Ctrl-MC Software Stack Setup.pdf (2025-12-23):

# Ctrl-MC Software Stack Setup + Getting Started

This document describes the software stack and method used to set up the development
environment for the Ctrl-MC project. This guide is for a PC setup with Windows 11, but many of the
instructions work for other platforms as well.

If you don’t want to create your own project, but just want to be able to modify and compile the existing Ctrl-MC source code, you should still make sure all the software mentioned below is installed and the extensions in VS Code are set up. You can skip the instructions on how to set up a new project, instead just download the source code from GitHub. (https://github.com/KIHestad/Ctrl-MC) Use VS Code and select “File” + “Open Folder…” + select the folder for the code you want to work with.

## Overview

The microcontrollers used for the Ctrl-MC system are from the STM32 family of microcontrollers (mcu). For the very first prototypes made in 2025/2026 the STM32G431 is used.

Software to be used is STM32CubeMX for generating the initial code, STM32CubeCLT for third-party integrated dev environments, and Microsoft VS Code with STM32 extensions for code editing, for uploading the code to mcu and for debugging. In addition CMake must be installed for

## STM32CubeMX

The software: STM32CubeMX is used to generate the initial code needed to interact with a STM32 microcontroller. The software can be downloaded for free from st.com website. You will have to create an account to download, but the software is completely free.

- STM32CubeMX: https://www.st.com/en/development-tools/stm32cubemx.html

For creating a new development project, start the application and select “Start My project
from ST Board”

Select the correct board from the tab “Board Selector” if using a STM dev board. If using a 3rd party board, like the “WeAct Studio” dev board used for the first prototype, identify the mcu ID, for example: “STM32G431CBU6”. Select the tab “MCU/MPU Selector” and use the field “Commercial Part Number” to find the correct MCU.

When the correct board or MCU is found, select: Start Project.

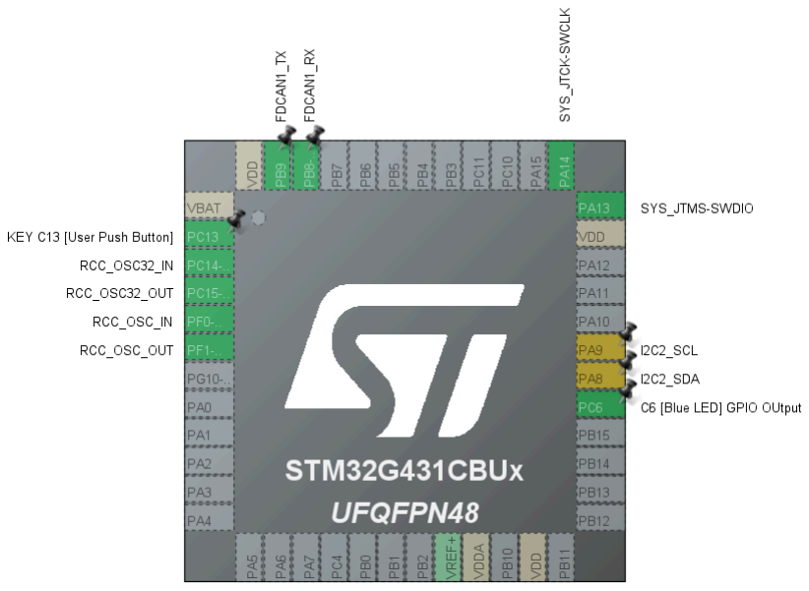
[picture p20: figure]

Now the tab “Pinout & Configuration” should be selected,
and the mcu should be shown visualized similarly to the picture to the right with all its pins. Each pin to be used must be selected and configured.

The next tab is the “Clock Configuration”, this needs also to be configured to set the speed for mcu.

When configuration is done, select the third tab: “Project Manager”. Remember to set “CMake” as build system, this what Ctrl-MC project users. Set at least this:
- Project name (no spaces in the name)
- Project location where you want the files saved
- Toolchain / IDE select: CMake

The config should be done, select the button that says: generate code.

## STM32CubeCLT

STM32CubeCLT is a toolset for third-party integrated development environment (IDE) providers, allowing the use of STMicroelectronics proprietary tools within their own IDE frameworks.

- STM32CubeCLT: https://www.st.com/en/development-tools/stm32cubeclt.html

Follow the user manual install instructions from the documents tab from the download page. (https://www.st.com/en/development-tools/stm32cubeclt.html#documentation)

## Microsoft Visual Studio Code

The preferred code editor is MS VS code. It has an extension that makes it convenient to upload the code to the mcu and for debugging code while running it.

- Microsoft Visual Studio Code: https://code.visualstudio.com/download

After install select the extension selector in the left sidebar, and search for:

- STM32Cube for Visual Studio Code

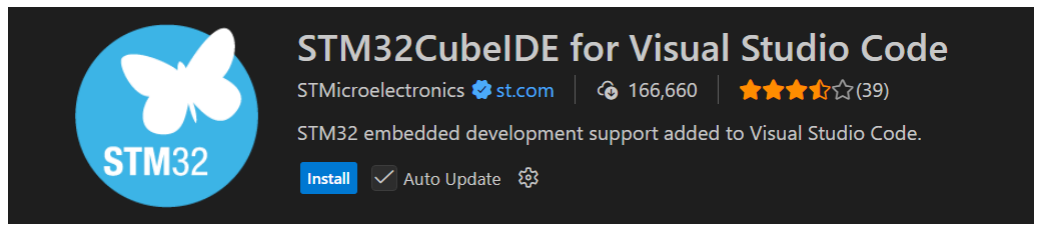
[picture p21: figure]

## CMake

CMake is a cross-platform, open-source build system generator that uses configuration files to automate the creation of platform-specific build scripts (like Makefiles or Visual Studio projects) for managing the software compilation process.

CMake is needed to be installed for compiling the STM32CubeIDE project and for uploading it to the MCU since this is what was set in STM32CubeMX as the Toolchain / IDE parameter.

Check here for more info, how to download and install CMake: https://cmake.org/download

On Windows it’s possible to install it from an elevated command prompt like this: | choco install cmake | You
might need to refresh path environment variables or just restart the PC after install.

## Getting started with a new STM32 project in Visual Studio

Setting up your own project is a smart way to understand the fundamentals. It’s highly recommended to do this before diving into others' code. Here is a quick guide for how to get started.

This assumes all the software on the previous pages is set up and a new project is created using STM32CubeMX. Open VS Code and navigate to the root folder of the project by selecting “File” + “Open Folder…” and select the folder.

The picture to the right shows an example folder structure of a newly created project named: “CANBUS_PROTO2”.

Navigate to the STM32 extension in the left navigation bar and select “Setup STM32Cube
project(s)” (double click).

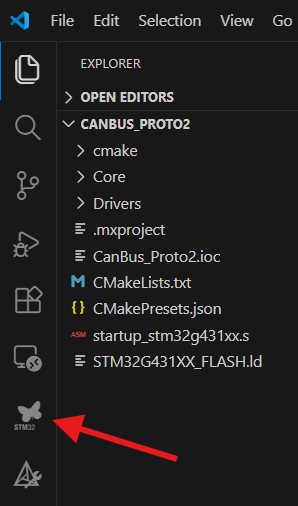
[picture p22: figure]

Fill in the project setup by selecting the same board/device as used in the STM32CubeMX configuration, and use the GCC toolchain. The picture below shows a config using the “WeAct Studio” development board with a STM32G431 mcu on it.

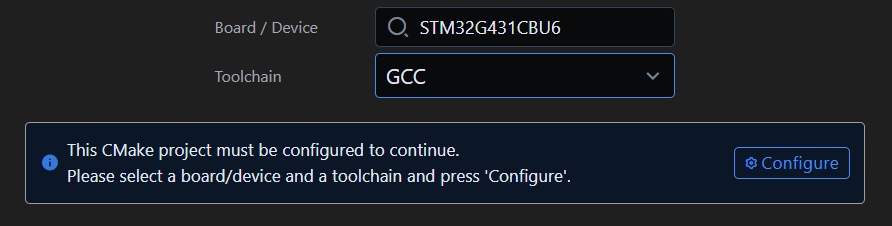
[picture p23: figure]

Press the “Configure” button and then select the “Debug” option, and then “Save and close”

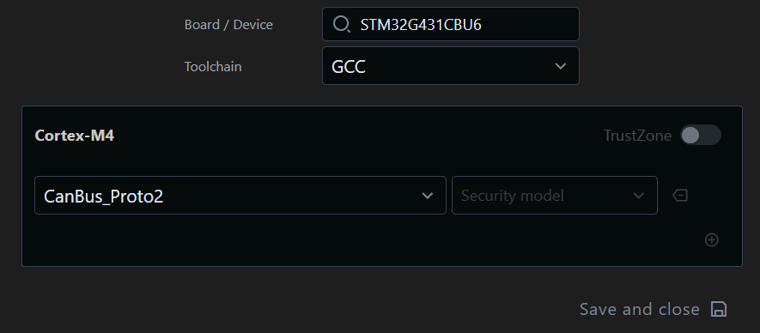
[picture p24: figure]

When this is done, additional folders (.settings, .vscode and build) will be created for the project.

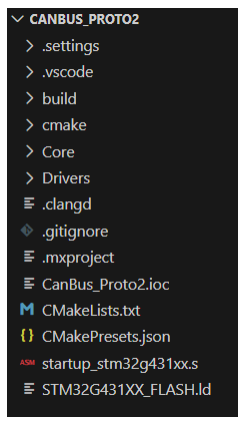
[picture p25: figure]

Go to the folder: Core + Src + main.c to start building your first code, remember to always add your custom code in between of comments like:

/* USER CODE BEGIN 2 */

// Blink 5 times rapidly to indicate startup
for (int i = 0; i < 10; i++)
{
HAL_GPIO_TogglePin(C6_BLUE_LED_GPIO_Port, C6_BLUE_LED_Pin); HAL_Delay(50);
}
HAL_GPIO_WritePin(C6_BLUE_LED_GPIO_Port, C6_BLUE_LED_Pin, GPIO_PIN_RESET);

/* USER CODE END 2 */

This code should now be possible to build and upload to the microcontroller. Good Luck!

## Revisions

Version 1 - Created by KI Hestad: 2025-12-16

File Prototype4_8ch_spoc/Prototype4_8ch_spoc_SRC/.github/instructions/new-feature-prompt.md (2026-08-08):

# Before starting check the following:
- If a new canbus message/signal is needed for the feature, this needs to be added to the file `can/cmc_can_message.dbc` and checked by the user using KVASER database editor to make sure it's according to requirements before any other code changes are made. When the DBC file is updated, the user must run `cantools` to generate the new `/Core/Inc/can/cmc_can_message.h` and `/Core/Src/can/cmc_can_message.c` files. The user must also check that the generated files are correct and do not contain any errors.

# Create a new feature module following the Ctrl-MC pattern:
- Header in `Core/Inc/feature/cmc_feature_<name>.h`
- Source in `Core/Src/feature/cmc_feature_<name>.c`
- Follow naming rules in `_documents/2_Naming_convention.md`
- Register in `cmc_features_manager`

# Instructions for implementing the feature logic:
Create a `cmc_feature_<name>_init()` function that initializes the feature and is called from `cmc_features_manager` during system initialization. The feature subscribes relevant state changes in `cmc_app_state` and implement the necessary logic to control outputs or perform actions based on the state of the system. Use `cmc_features_output` functions to control physical outputs as needed.

Create a `cmc_feature_<name>_process()` function that is called from the main loop in `cmc_features_manager`. This function is the single authoritative resolver for the feature's output state. It implements two independent parallel paths that both execute on every call:

**Path 1 — Switch output:** Read the relevant resolved state from `cmc_app_state`, compare to previous output state, and drive physical switch outputs if anything changed. All output-only features implement only this path.

**Path 2 — Logical state (only for features that compute derived state):** Read multiple fields from `cmc_app_state` (button inputs, CAN-received states, IMU events, alarm state, ignition state, etc.), apply priority and conflict resolution rules, and if the computed logical state has changed, call the appropriate `cmc_app_state_update_<state>()` function in `cmc_app_state_updater.c`. That function writes the resolved state to `cmc_app_state` and broadcasts it over CAN so all units stay in sync. Features never write to `cmc_app_state` directly — they always go through the updater as the write gateway.

Examples of features using only Path 1: horn, ignition output, starter.
Examples of features using both paths: direction indicator (resolves cancel-other/hazard → Path 2, then drives blink outputs → Path 1), alarm (computes alarm active state → Path 2, then drives hazard outputs → Path 1).

Add into `cmc_app_state_updater.c` logic to update the app state and send over canbus the appropriate messages based on input states or other conditions that are relevant for the new feature. This could involve adding new variables to the `cmc_app_state` struct to track the necessary state for the feature. This must be considered carefully to ensure that the app state remains efficient and does not exceed flash storage limits.

If the feature requires configuration parameters, add them as a dedicated struct (e.g. `cmc_feature_<name>_t`) in the feature header, then:
1. Add a field for it inside `cmc_config_t` in `cmc_config_type.h`, alongside the other `feature_*` members.
2. Add `sizeof(cmc_feature_<name>_t)` to the `_padding` expression in the same struct so that the total size of `cmc_config_t` remains a multiple of 8 bytes for flash storage alignment. The padding is calculated as `(8 - (sum of all member sizes) % 8) % 8` — every new member must be included in that sum.
3. Set sensible default values in `cmc_config_defaults.c` under the `cmc_config_default_for_demo` initialiser.

Remember to add new c-files to the `CMakeLists.txt` at root level in the appropriate sections to ensure they are compiled and linked correctly.

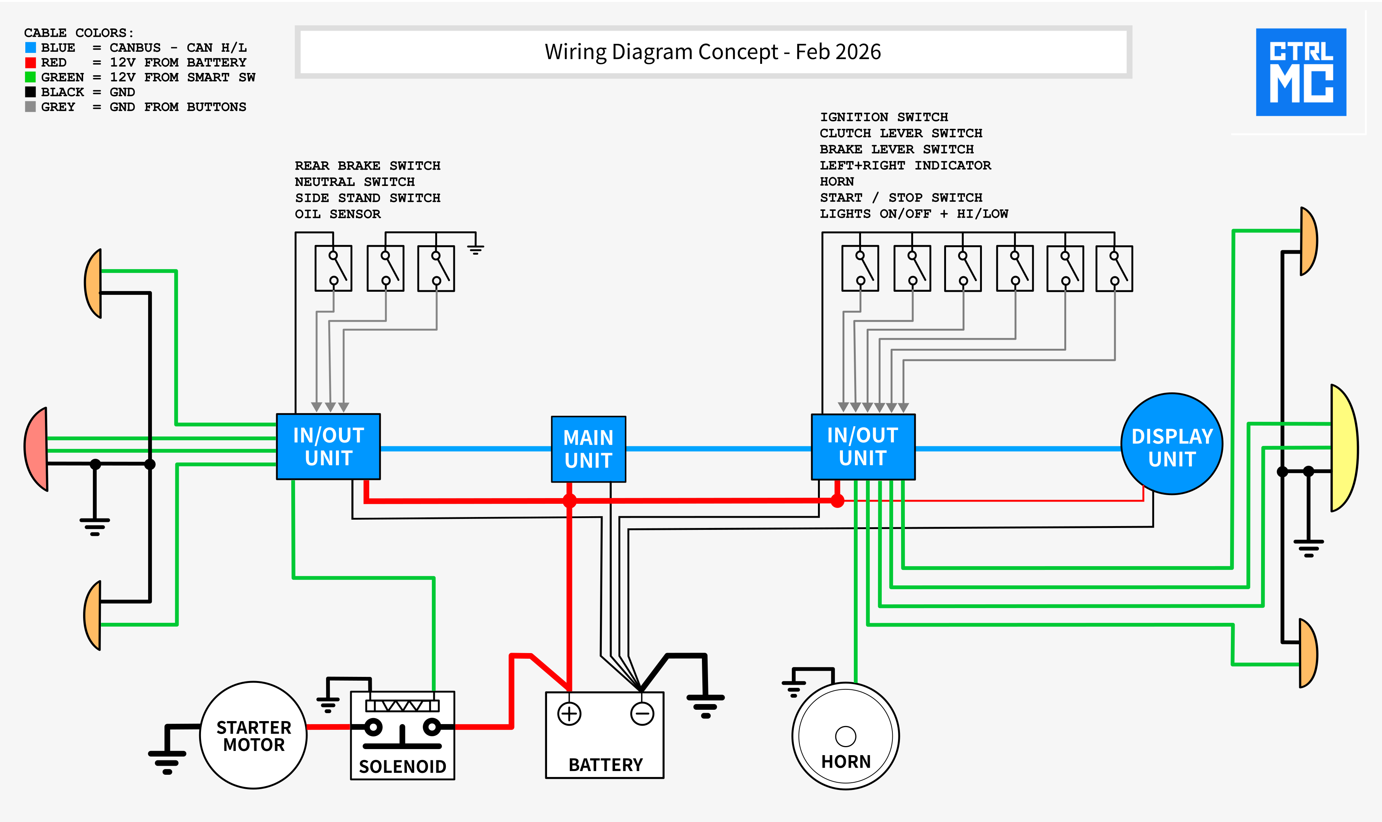
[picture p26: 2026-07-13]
Documents/Wiring_Diagram_Concept.png

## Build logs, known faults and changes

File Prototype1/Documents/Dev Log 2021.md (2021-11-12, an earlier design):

#Development Log 2021

_This document is some kind of journal, I'm not really sure yet what it is._
_It will randomly be updated by me as the project evolves._
_I do not expect anyone to be bothered reading this,_
_it is more or less written by me to myself..._
_...but if you accidentally end up here - feel free to take a look :-)_

_Best regards_
_KI Hestad_

##How it all began - September 2021
The beginning of it all is more or less summarized in my YouTube video: [Motorcycle Wiring done differently - this can be BIG!](https://youtu.be/3W9Y04q-X2k)

What I did not include in the video was a couple of failed attempts, version 1 and 2:

##Version 0.1 - September 2021
I started the project trying to use only one Arduino Nano. It was supposed to be located under the seat tray near the battery and the relays. This required long cables to the handlebar for attaching to buttons and the display. There were not enough pins on the board for individual input and outputs, so I tested using multiple buttons with resistors in between and read signals from the buttons using analogRead.
 
It worked with short cables, but there were not reliable signals when using a long cable (around 1.5m). 
Another problem occured when I got the OLED display, it did not work at all using long cables. The I2C communication framework used for the display does not work over long cables.

##Version 0.2 - September 2021
After some research I found the serial communication option using the RX/TX pins and switched over to using two Arduino Nanos. That worked great! It solved multiple problems, now I put the arduinos close to the display/relay unit, and I got twice as many pins to use for input/outputs. 

Because of this I could change from using a single pin for multiple buttons to using a separate input pin per button and changed to digitalRead. This makes it possible to read input signals when several buttons are pressed simultaneously, and the readings are more reliable and easier to set up.

This configuration worked for a while, until the c++ code became bigger and there was not enough memory on the Arduino Nano for the handlebar unit. The Adafruit OLED library needs about 1K SRAM just for driving the display, the total of 2K on the Arduino Nano board was not enough.

##Version 0.3 = September 2021
I had a NodeMCU / esp8266 laying around. It has a lot more memory and is much faster. It required just some minor code changes and I could continue the development. However this board has only 5 usable input pins available for buttons after the OLED display and the serial communication has occupied the pins they need.
The NodeMCU board is also a bit big, I would like to have a small form factor to make the handlebar unit compact. 

I started to check out different Arduino boards that could be better suitable for the handlebar unit, but I managed to use the NodeMCU with limited number
of buttons to at least create the first usable version of the system.

##From private project to Open Source
When I started the job on this project in the beginning of September 2021, the plan was to make a solution for my bike only, and create a video of it to share on YouTube. I have always been a fan of open source projects. I have used a lot of free software from open source projects. Some examples: I have been using several Linux distros, and my 3D-printer is running on software from open source projects (Marlin, OctoPrint). 

As the project went along, and I finally started to get it to work, I thought this project could be my chance to contribute to the "Open Source World". If the solution I have started on can be of use for others, why not. As I have not much experience with electronics and Arduino development it might also help the project
going forward if others would like to contribute. 

I have gained quite some experience with programming and software development in general over the years, mostly on Windows and web. The languages I know best is C#, but I have been using a lot of languages: Basic, Java, JavaScript, Pascal, Perl, Python, Visual Basic, and probably more. C++is a programming language I have not used before, but learning a new programming language is not that hard  :-) Each language has its tricks and quirks though, it takes time to master it fully.

##Publishing the first YouTube video about the project - October 2021
I decided to create a video of what I have done so far, and at the same time check if there was any interest from others to participate. No need to say more - it is all covered in the YouTube video: [Motorcycle Wiring done differently - this can be BIG!](https://youtu.be/3W9Y04q-X2k)

I also posted a link to the video on a couple of Facebook Arduino groups, and hoped someone would find the project interesting. The feedback on the video and the project was very positive, a lot of comments both on FB and on the YouTube channel. That is great! @Ramjet from Australia reached out and offered his help, he also set up the [Discord Channel: Ctrl-MC](https://discord.gg/ccT6R4EF)

##Preparing Version 0.4 - October 2021
Several viewers have suggested using solid state relays instead for the traditional relay module I have planned for. @Ramjet has suggested creating a custom one designed as a perfect fit for the relay unit. This is a much better solution, more compact and energy efficient, and with no moving parts hopefully also more durable. Lets see how this goes :-)

In the serch for finding a better Arduino board for the handlebar unit, a couple of STM32 boards was aqured. I thought could be the right solution for the handlebar unit. It is quite powerful, has a lot of pins and it is very small. The boards use a 32bit ARM based CPU, quite a beast, but after some more research it seems to be a bit complex to set up. It needs a USB 2.0 to TTL Serial Adapter for flashing code to it as there is no built in bootloader. Seems like not all Arduino libraries supports this bord either. 

I ended up buying a 30 pins ESP32 (ESP32 NodeMCU Module Board WiFi Bluetooth CP2102 ESP-32S 2.4GHZ). This board is flexible when it comes to pin usage, most can be used for both input and output. It has WiFi & BT as well, this can be useful for future upgrades like: turn on/off ignintion or configure settings from smartphone. The board worked perfectly, and will be the one to use for the next version.

A 8 channel relay unit has also been bought and will be used in addition to the 2 channel relay used for demoing version 0.3. A slightly bigger 1.3" OLED display will replace the first 0.96" display. Some 3D-printed enclosures will also be made.

##Still preparing Version 0.4 - Nov 2021

Decided to rework the code. Better overall structure and a common local library is holding shared code used by both the relay unit & the display unit. "Display unit" is by the way the new name for the arduino previously called "Handlebar unit". All parts for creating a prototype has now arrived. A 3d printed enclosure for the relay unit is also made. A test feature is also added, possible to enable by longpress on a spesific button before the ignition is turned on, just to check that pin assignments for the display unit is correctly configured, it displays the name of the button pressed on the display.

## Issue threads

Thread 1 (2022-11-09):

Procedure to upload this code to Arduino

ramabaruva, 2022-11-09:
Hello ,
I was very impressed by the initiative and work done,
I am trying to implement the same on my bike .
But got stuck on step one ,as I am not a programmer.
can you please share the details on procedure how to use the code and deploy it on the Arduino.
a video will also help for the same.
Also please uploaded the circuit diagram of the finished wiring setup.

Regards
Rama

KIHestad, 2023-07-03:
Hey, sorry for not replying. I had not noticed this request. The project has been paused for a while, but I am starting up again now.

I hope to share some news very soon, will be posted a video on YouTube later this summer.

Closed 2023-07-03.

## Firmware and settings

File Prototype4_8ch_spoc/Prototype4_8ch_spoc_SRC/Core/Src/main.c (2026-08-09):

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
/* Includes ------------------------------------------------------------------*/
#include "main.h"

/* USER CODE BEGIN Includes */

/*******************************************************************************
 *  CMC Include app logic header                                               *
 ******************************************************************************/

 #include "app/cmc_app_logic.h" 


/* USER CODE END Includes */

ADC_HandleTypeDef hadc1;

CRC_HandleTypeDef hcrc;

FDCAN_HandleTypeDef hfdcan1;

SPI_HandleTypeDef hspi1;

void SystemClock_Config(void);
static void MX_GPIO_Init(void);
static void MX_FDCAN1_Init(void);
static void MX_ADC1_Init(void);
static void MX_CRC_Init(void);
static void MX_SPI1_Init(void);
/**
  * @brief  The application entry point.
  * @retval int
  */
int main(void)
{

  /* MCU Configuration--------------------------------------------------------*/

  /* Reset of all peripherals, Initializes the Flash interface and the Systick. */
  HAL_Init();

  /* Configure the system clock */
  SystemClock_Config();

  /* Initialize all configured peripherals */
  MX_GPIO_Init();
  MX_FDCAN1_Init();
  MX_ADC1_Init();
  MX_CRC_Init();
  MX_SPI1_Init();
  /* USER CODE BEGIN 2 */
  
  /*********************************************************************************
  *  CMC Main application logic init                                               *
  *********************************************************************************/
  
  cmc_app_init(); 
  
  /* USER CODE END 2 */

  /* Infinite loop */
  /* USER CODE BEGIN WHILE */
  while (1)
  {
    
  /**********************************************************************************
  *  CMC Start main application logic loop                                          *
  **********************************************************************************/
    
    cmc_app_process(); 
 
    
    /* USER CODE END WHILE */

    /* USER CODE BEGIN 3 */
  }
  /* USER CODE END 3 */
}

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


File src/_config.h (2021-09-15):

/*
 *   Ctrl-MC // An open source Arduino project made by KI Hestad: https://github.com/KIHestad/Ctrl-MC
 */

// *************************************************
// Inputs, outputs and features
// *************************************************
// The controller has differen features that can be enabled or disabled
// A feature is a code part controlling "somthing" on the motorcycle, ex: controlling the signal horn
// Most features has one or several inputs and the same for outputs


// *************************************************
//   Arduino Input Pins Configuration
// *************************************************
// Map the controllers inputs to relecant input pin for reading buttons/switches signals, levers/pedals or sensors
// It is possible to map several features to same pin, ex: handlebar buttons connected in series using a resistors between each button delivers different values per button back to the analog input pin
// Some analog pins can on most Arduinos also be used as a digital pin, A0 (fist analog pin) can normally be referred to as pin 14 when used as digital pin
// For each feature set input pin configuration like this: { pin_number, short_name, pin_read_type, analog_pin_expected_read_value (20 - 1023) }
// Examples
// - Value for disabled inputs:  { false }; // Other values can be added, will be ignored by the system
// - Value for digial read:      { true, 12, digitalPin, 0, "IGN-SW", "Ignition Switch" };
// - Value for analog read:      { true, A0, analogPin, 1023, "CLUTCH", "Clutch Lever" };
int ANALOG_PIN_VALUE_VARIATION = 25; // This value will be subtracted and added to the analog_value to get min- and max reading acceptance range
// Normally only the pin number and analog_pin_expected_read_value should be edited and set according to the Arduino pin actually used and input signal according to what values returned
// When using several buttons on one analog pin connected in series, the reccomended resistor is: 150ohm (but it can vary)
Input MAIN_IGNITION_SWITCH_INPUT        = { false, 12, digitalPin, 0, "IGN-SW", "Ignition Switch" };
// Lever left
Input CLUTCH_SWITCH_INPUT               = { true, A0, analogPin, 1023, "CLUTCH", "Clutch Lever" };
// Normally on left hand side handle button controls
Input SIGNAL_HORN_SWITCH_INPUT          = { true, A0, analogPin, 145, "HORN", "Horn Button" }; // When triggered using long press it can use same pin as for ligths hi/lo
Input LIGHTS_LOW_HIGHT_SWITCH_INPUT     = { true, A0, analogPin, 145, "HI/LO", "Lights High/Low Beam Button" }; // Triggered with short press, can be same as signal horn
Input INDICATOR_LEFT_SWITCH_INPUT       = { true, A0, analogPin, 437, "T-LEFT", "Turn Signal Left Button" };
Input INDICATOR_RIGHT_SWITCH_INPUT      = { true, A0, analogPin, 254, "T-RIGHT", "Turn Signal Left Button" };
// Normally on right hand side handle button controls
Input LIGHTS_MAIN_SWITCH_INPUT          = { false }; // Can be ignored if not having enough buttons, lights can be selected from display menu
Input START_MOTOR_SWITCH_INPUT          = { true, A1, analogPin, 145, "STA/STP", "Start/Stop Button" }; // Can be safer to use separate digital pin in case series buttons has dirty signal
Input DISPLAY_MENU_ITEM_SELECT_INPUT    = { true, A1, analogPin, 437, "D-SEL", "Display Select Item" };
Input DISPLAY_MENU_ITEM_NEXT_INPUT      = { true, A1, analogPin, 254, "D-NEXT", "Display Goto Next" };
// Lever right
Input BRAKE_SWITCH_INPUT                = { true, A1, analogPin, 1023, "BRAKE", "Brake Lever" };
// Sensors
Input OIL_SENSOR_INPUT                  = { false };
Input NEUTRAL_SWITCH_INPUT              = { false };
Input ENGINE_RUNNING_SENSOR_INPUT       = { false };

// Several buttons can be connected to the same pin when using analog input
// In this section list the inputs that are connected to the same pin, it makes reading the buttons faster for the methods, as it is not needed to perform actual analogRead per input
bool HANDLEBAR_SWITCHES_LEFT_ENABLED = true;
Input HANDLEBAR_SWITCHES_LEFT[5] = {                 
    CLUTCH_SWITCH_INPUT,
    SIGNAL_HORN_SWITCH_INPUT,
    LIGHTS_LOW_HIGHT_SWITCH_INPUT,
    INDICATOR_LEFT_SWITCH_INPUT,
    INDICATOR_RIGHT_SWITCH_INPUT 
};
bool HANDLEBAR_SWITCHES_RIGHT_ENABLED = true;
Input HANDLEBAR_SWITCHES_RIGHT[4] = {                 
    START_MOTOR_SWITCH_INPUT,
    START_MOTOR_SWITCH_INPUT,
    DISPLAY_MENU_ITEM_SELECT_INPUT,
    BRAKE_SWITCH_INPUT
};
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

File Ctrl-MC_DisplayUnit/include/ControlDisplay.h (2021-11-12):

/***  Ctrl-MC // An open source Motorcycle Controller Arduino project by KI Hestad: https://github.com/KIHestad/Ctrl-MC  ***/

class ControlDisplay {

    public:
        
        // Constructor
        void init() {
            // SSD1306_SWITCHCAPVCC = generate display voltage from 3.3V internally
            if(!display.begin(SSD1306_SWITCHCAPVCC, DISPLAY_SCREEN_ADDRESS)) {
                // TODO, use spaker to send alarm sound signal
                // Serial.println(F("Display (SSD1306) allocation failed"));
                for(;;); // HALT - Don't proceed, loop forever
            }
            display.setTextSize(DISPLAY_TEXT_SIZE);
            display.setTextColor(SSD1306_WHITE);
            showSplash();
            gotoStatusPageInitiate();
        };

        // Show splash screen
        void showSplash() {
            Image image = Image();
            image.kiHestadLogo();
            delay(1750);
            display.clearDisplay();
            setCursorForCenteredText(1, 7);
            display.println(F("Ctrl-MC"));
            display.display();
            delay(250);
            setCursorForCenteredText(2, 21);
            display.println(F("Motorcycle Controller"));
            display.display();
            delay(250);
            setCursorForCenteredText(3, 12);
            display.println(F("by KI Hestad"));
            display.display();
            delay(250);
        };

        // Goto status page after a timeout period, show progressbar until done
        void gotoStatusPage() {
            if (bikeStatus.displayGotoStatusPageTimestamp > 0) {
                unsigned long timeElapsed = millis() - bikeStatus.displayGotoStatusPageTimestamp;
                // Check progress
                if (timeElapsed > MENU_STATUS_PAGE_PROGRESSBAR_DURATON) {
                    // Switch to status page now
                    gotoStatusPageCancel();
                    bikeStatus.displayMenyPageSelected = 0;
                    bikeStatus.displayMenySubPageSelected = 0;
                    bikeStatus.displayMenuTimeoutTimestamp = 0;
                    bikeStatus.displayMenyShowRunningStopWatch = 0;
                    if (bikeStatus.ignition == BikeStatusIgnition::ignTestButtonsMode)
                        bikeStatus.ignition = BikeStatusIgnition::ignOff;
                    refreshStatusPage();
                }
                else {
                    // Show progress bar
                    int xLineStart = DISPLAY_SCREEN_WIDTH * timeElapsed / MENU_STATUS_PAGE_PROGRESSBAR_DURATON / 2;
                    int xLineEnd = DISPLAY_SCREEN_WIDTH - xLineStart;
                    display.drawLine(0, 0, DISPLAY_SCREEN_WIDTH, 0, SSD1306_BLACK);
                    display.drawLine(xLineStart, 0, xLineEnd + 2, 0, SSD1306_WHITE);
                    display.display();
                    bikeStatus.displayGotoStatusPageProgress = true;
                }
            }
        };

        // Inititate display autosuhutdown
        void gotoStatusPageInitiate() {
            bikeStatus.displayGotoStatusPageTimestamp = millis();
        };

        // Terminate display autosuhutdown and hide progress bar
        void gotoStatusPageCancel() {
            bikeStatus.displayGotoStatusPageTimestamp = 0;
            bikeStatus.displayGotoStatusPageProgress = false;
            display.drawLine(0, 0, DISPLAY_SCREEN_WIDTH, 0, SSD1306_BLACK);
        };

        // Refresh and show the status page if not a menu item is selected
        void refreshStatusPage() {
            if (bikeStatus.displayMenyPageSelected == 0)
            {
                // Prepare display for status page
                gotoStatusPageCancel();
                display.clearDisplay();
                if (bikeStatus.ignition == ignOn)
                {
                    Image image = Image();
                    // Dependig of bike status show 1, 2 or 3 image icons
                    if (bikeStatus.indicator != indOff) {
                        // Turn signals are on, show 3 icon layout, turn signal indicator as big
                        if (bikeStatus.indicator != indOff && bikeStatus.indicatorBlinkOn) {
                            if (bikeStatus.indicator == indLeft)
                                image.indicatorLeft(imgPos3Left);
                            else if (bikeStatus.indicator == indRight)
                                image.indicatorRight(imgPos3Left);
                            else if (bikeStatus.indicator == indHazard)
                                image.indicatorHazard(imgPos3Left);
                        }
                        if (bikeStatus.lights != lightsOff || bikeStatus.lightHighBeamFlash) {
                            if (bikeStatus.lightHighBeamFlash)
                                image.lightsHighSmall(imgPos3RightTop);
                            else if (bikeStatus.lights == lightsPark)
                                image.lightsParkSmall(imgPos3RightTop);
                            else if (bikeStatus.lightHilo == lightsLow)
                                image.lightsLowSmall(imgPos3RightTop);
                            else if (bikeStatus.lightHilo == lightsHigh)
                                image.lightsHighSmall(imgPos3RightTop);
                        }
                        if (bikeStatus.neutral) {
                            image.neutralSmall(imgPos3RightBottom);
                        }
                    }
                    else if (bikeStatus.lights != lightsOff || bikeStatus.lightHighBeamFlash) {
                        // Both lights and neutral/in gear to be shown, show to icon layout
                        if (bikeStatus.lightHighBeamFlash)
                            image.lightsHighBig(imgPos2Left);
                        else if (bikeStatus.lights == lightsPark)
                            image.lightsParkBig(imgPos2Left);
                        else if (bikeStatus.lightHilo == lightsLow)
                            image.lightsLowBig(imgPos2Left);
                        else if (bikeStatus.lightHilo == lightsHigh)
                            image.lightsHighBig(imgPos2Left);
                        // Neutral
                        if (bikeStatus.neutral) {
                            image.neutralBig(imgPos2Right);
                        }
                    }
                    else {
                        if (bikeStatus.neutral) {
                            image.neutralBig(imgPosCenter);
                        }
                    }
                }
                display.display();
            }
        }

        void statusTextRemove() {
            display.fillRect(0, DISPLAY_SCREEN_HEIGHT-DISPLAY_TEXT_CHAR_HEIGHT -1, DISPLAY_SCREEN_WIDTH, DISPLAY_TEXT_CHAR_HEIGHT + 2, SSD1306_BLACK); 
        };
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

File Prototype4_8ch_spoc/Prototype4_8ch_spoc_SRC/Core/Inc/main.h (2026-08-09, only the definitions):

#define BTN_DEV_BOARD_Pin GPIO_PIN_13
#define BTN_DEV_BOARD_GPIO_Port GPIOC
#define SW_IS_Pin GPIO_PIN_3
#define SW_IS_GPIO_Port GPIOA
#define SW_CSN_Pin GPIO_PIN_4
#define SW_CSN_GPIO_Port GPIOA
#define SW_SCLK_Pin GPIO_PIN_5
#define SW_SCLK_GPIO_Port GPIOA
#define SW_MISO_Pin GPIO_PIN_6
#define SW_MISO_GPIO_Port GPIOA
#define SW_MOSI_Pin GPIO_PIN_7
#define SW_MOSI_GPIO_Port GPIOA
#define LED_Pin GPIO_PIN_6
#define LED_GPIO_Port GPIOC
#define BTN_10_Pin GPIO_PIN_8
#define BTN_10_GPIO_Port GPIOA
#define BTN_9_Pin GPIO_PIN_9
#define BTN_9_GPIO_Port GPIOA
#define FDCAN1_WAKE_UP_Pin GPIO_PIN_10
#define FDCAN1_WAKE_UP_GPIO_Port GPIOA
#define BTN_8_Pin GPIO_PIN_15
#define BTN_8_GPIO_Port GPIOA
#define BTN_7_Pin GPIO_PIN_10
#define BTN_7_GPIO_Port GPIOC
#define BTN_6_Pin GPIO_PIN_3
#define BTN_6_GPIO_Port GPIOB
#define BTN_5_Pin GPIO_PIN_4
#define BTN_5_GPIO_Port GPIOB
#define BTN_4_Pin GPIO_PIN_5
#define BTN_4_GPIO_Port GPIOB
#define BTN_3_Pin GPIO_PIN_6
#define BTN_3_GPIO_Port GPIOB
#define BTN_2_Pin GPIO_PIN_7
#define BTN_2_GPIO_Port GPIOB
#define BTN_1_Pin GPIO_PIN_9
#define BTN_1_GPIO_Port GPIOB

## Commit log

2021-09-14 Not just changing project name, but also reworking most of the user configuration structure
    [_config.h, controlIgnition.h, setup.h]
2021-09-15 Implemented ignition on using password (from buttons)
2021-09-15 Reworked button method, restructuring a lot, not tested yet
    [_config.h, controlIgnition.h, setup.h]
2021-09-17 Moved all files to subfolder, first attemt is now moved to: Prototype_ver1
2021-09-20 Major improvement: implemented serial communication between Handlebar unit and Relay unit
2021-09-25 Improved some icons, stared adding handlebar button controls (HiLo)
2021-09-26 Reworked ignition on/off and lights images, cleaner layout, also some minor improvementt here and there
    [_config.h, controlDisplay.h, controlDisplayMenu.h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]
2021-10-02 Small fix, disable goto status page when status page is selected
    [controlDisplayMenu.h]
2021-10-03 Minor bugfixes and improvements
    [_config.h, controlDisplay.h, controlDisplayMenu.h]
2021-10-05 Implemented shared code as local library in new project: "Common", implemented for relay unit, TBD for handlebar unit Refacored relay unit project, each classes separated / not dependent on other cla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
2021-10-05 Removed first prototype project, added getting-started document (draft)
2021-10-23 Reworked Handlebar Unit to work with ESP32, Started moving config as common library, improved code for relay unit.
    [controlDisplayMenu.h, controlIgnition.h]
2021-11-12 Massive rework, still in progress.
    [ControlDisplay.h, Image.h]
2021-12-02 Several bugfixes after system test, added temperature sensor
2021-12-03 Added new display menu item for starter motor
2022-04-12 Added original wiring diagram for Honda CB400N CB250N Super Dream
2023-07-22 Updated documents, PCB for display unit beta ver 0.1
    [Ctrl-MC Dsiplay Module PCB ver1-B_Cu.gbr, Ctrl-MC Dsiplay Module PCB ver1-B_Mask.gbr, Ctrl-MC Dsiplay Module PCB ver1-B_Paste.gbr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]
2023-09-20 Marketing Images
    [Ctrl-MC Dsiplay Module PCB ver1.kicad_pcb]
2025-09-28 Refactoring, moving old code to: Prototype1
    [Ctrl-MC Dsiplay Module PCB ver1-B_Cu.gbr, Ctrl-MC Dsiplay Module PCB ver1-B_Mask.gbr, Ctrl-MC Dsiplay Module PCB ver1-B_Paste.gbr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]
2025-09-28 New Prototype 2: Head Unit (speedo & tach)
2025-09-28 Added support for hum/temp sensor + elefant logo
2025-11-29 Ported to STM32
2025-12-16 Refactoring after prototype 2
    [Ctrl-MC Dsiplay Module PCB ver1-B_Cu.gbr, Ctrl-MC Dsiplay Module PCB ver1-B_Mask.gbr, Ctrl-MC Dsiplay Module PCB ver1-B_Paste.gbr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]
2025-12-23 Added Prototype 3
2026-01-11 Refactored Prototype 2, moded code to SRC folder
2026-01-11 Added KiCad Project for prototype
2026-01-11 Added KiCad Project
2026-01-24 Added MC Wiring Sim Project
2026-01-24 Incl img of the MC Wiring Sim PCB
2026-02-25 Added prototype 4, still in progress
2026-02-25 Improved prototype info
2026-04-06 Added CANBUS message support structure using DBC-file
2026-04-24 Added canbus manager for send/receive messages + file descr
2026-04-25 Improved stm32 config (160Mhz ) canbus config and methods
2026-04-25 improved canbus message db file
2026-04-25 Small fixes, testet boot, verified code
    [cmc_config_manager.c]
2026-04-26 added system state status and onboard led error blink
    [cmc_config_manager.c, cmc_util_onboard_led.c]
2026-04-26 Startup sequence fixed, tested and found OK
    [cmc_config_manager.c, cmc_util_onboard_led.c]
2026-04-26 New methods for button mgmt and unit_store
2026-04-26 Improved startup sequence, set unit_id by button
2026-04-26 improve LED blink pattern
2026-04-26 added stm32 hw crc for config at save
2026-05-14 cleanup statup procedure - bugfixes
    [cmc_config_unit_info.c]
2026-05-24 Added LED functions
2026-08-07 Prototype 4 variant for stress testing
2026-08-08 Monitoring for the switches
2026-08-08 Fully working fault detection and current monitoring per switch
2026-08-09 Rename folder for 3ch profet prototype
2026-08-09 Prepare for 8ch spoc prototype
2026-08-09 Updated backup stm32 config file
2026-08-09 Removed mapping for PROFET switches
2026-08-09 Updated HAL from CubeMX for SPOC switches
2026-08-09 Refacor for spoc switches and separate mcu driver
2026-08-09 improvements for SPOC switches
2026-08-09 Improvements for canbus messages
2026-08-09 improvements spoc switches
2026-08-10 Working SPOC switches with CANBUS monitorin
2026-08-24 motorcycle wheel simulator readme
2026-09-16 hall effect wheel simulator tester
    [rotor.stl, rotor_base.stl, rotor_base_cover.stl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]

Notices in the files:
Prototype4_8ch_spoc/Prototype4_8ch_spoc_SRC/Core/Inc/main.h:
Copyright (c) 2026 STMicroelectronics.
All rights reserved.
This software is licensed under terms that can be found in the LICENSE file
